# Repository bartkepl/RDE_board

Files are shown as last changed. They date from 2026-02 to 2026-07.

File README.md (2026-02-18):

# RDE (Resistance DEcade)
Resistance DEcade with SCPI, UART, USB, RS485 and ETHERNET in 3U eurocard format

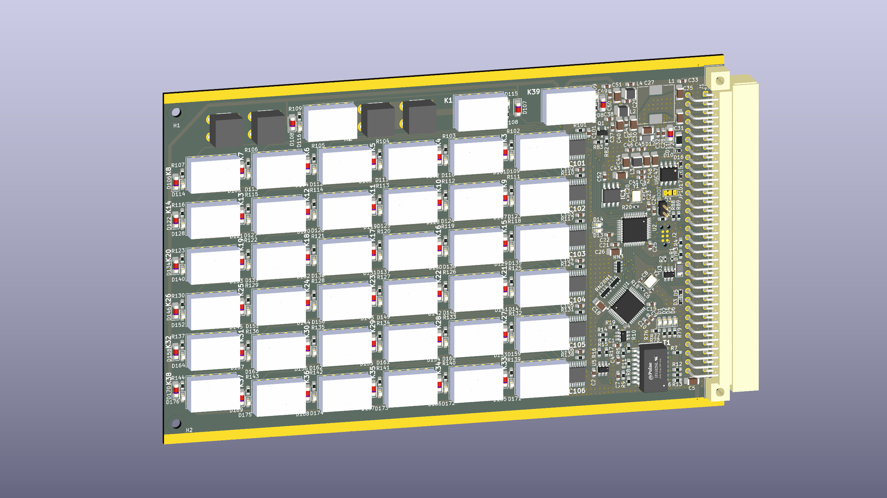
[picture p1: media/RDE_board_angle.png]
Resistance DEcade board


---
## Status : WIP

- First revision of schematic and PCB is done. 
- Creating a complementary board with a DIN 41612 connector and other interface connectors to order a complete assembly and begin work on software and interface testing.

---
## Features:
- 2 layer board
- ARM Cortex-M33 Processor in LQFP48 (STM32G431CBT6) 
- 0 - 999k&#8486; ressistor-relay matrix driven by 6x STPIC6C595
- USB 2.0
- 10/100 Ethernet (based on WIZnet W5500)
- UART
- Half-duplex RS485 
- 3U eurocard IEEE 1101.1-1998 format (160x100 mm)
----

## License and Contribution

[MIT License](/LICENSE)

Open to contributions in both software and hardware!

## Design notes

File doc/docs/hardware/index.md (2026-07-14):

# Sprzęt – Przegląd

## Mikrokontroler STM32G431CBT6

| Parametr | Wartość |
|---|---|
| Rdzeń | ARM Cortex-M33, 170 MHz |
| Flash | 128 KB |
| SRAM | 32 KB |
| Opakowanie | LQFP48 |
| USB | USB 2.0 Full Speed z CRS (bez zewnętrznego kwarcu) |
| Interfejsy | 2× SPI, 1× I2C, 2× UART, USB FS |
| ADC | 12-bit, 5 Msps |
| DAC | 12-bit |

### Przypisanie peryferiów

| Peryferium | Sygnały | Przeznaczenie |
|---|---|---|
| SPI1 | PA5/PA6/PA7, PA4 (REL_EN), PA6 (REL_RCK) | Sterowniki STPIC6C595 (przekaźniki) |
| SPI2 | PB13/PB14/PB15, PB12 (CS) | W5500 Ethernet |
| I2C1 | PB6/PB7 | FRAM FM24C64B |
| UART1 | PA9/PA10 | Debug / SCPI przez UART |
| UART2 | PA2/PA3 | RS485 (half-duplex przez transceiver) |
| USB FS | PA11/PA12, PA11 (VBUS det.) | USB-TMC (TinyUSB) |
| CRS | – | Automatyczne przycinanie HSI48 na SOF USB |

### Mapowanie pinów GPIO

| Pin | Kierunek | Sygnał | Opis |
|-----|:---:|---|---|
| PA2 | OUT | UART2_TX | RS485 TX / RS485 DE |
| PA3 | IN | UART2_RX | RS485 RX |
| PA4 | OUT | REL_EN | Zasilanie przekaźników (STPIC6C595 OE, active HIGH) |
| PA5 | OUT | SPI1_SCK | Zegar SPI dla shift-registrów |
| PA6 | OUT | REL_RCK | Latch shift-registrów (aktywny zboczem narastającym) |
| PA7 | OUT | SPI1_MOSI | Dane do shift-registrów |
| PA9 | OUT | UART1_TX | Debug TX |
| PA10 | IN | UART1_RX | Debug RX |
| PA11 | IN | USB_DETECT | Detekcja VBUS (5V obecne) |
| PA11/12 | IO | USB_DM/DP | Magistrala USB D−/D+ |
| PB6 | OUT | I2C1_SCL | Zegar I2C (FRAM) |
| PB7 | IO | I2C1_SDA | Dane I2C (FRAM) |
| PB12 | OUT | W5500_CS | Chip Select dla W5500 (active LOW) |
| PB13 | OUT | SPI2_SCK | Zegar SPI dla W5500 |
| PB14 | IN | SPI2_MISO | Dane z W5500 |
| PB15 | OUT | SPI2_MOSI | Dane do W5500 |
| PC13 | OUT | LED_R | LED czerwony (błąd SCPI) |
| PC14 | OUT | LED_G | LED zielony (heartbeat) |
| Pxx | OUT | W5500_RST | Reset W5500 (active LOW, 10 ms) |

---

## Schemat blokowy systemu

```
                    ┌──────────────────────────────────────┐
                    │         STM32G431CBT6 @ 170 MHz      │
                    │                                      │
 USB Host ─────────── USB FS (PA11/PA12)                  │
                    │   └─ TinyUSB (USB-TMC Class)         │
                    │                                      │
 RJ-45 ─── PHY ─── │ SPI2 (PB12-15) ── W5500             │
                    │   └─ VXI-11 / DHCP / mDNS            │
                    │                                      │
                    │ SPI1 (PA4-7) ─── STPIC6C595 ×6      │
                    │   └─ REL_EN (PA4)                    │── 48 przekaźników
                    │   └─ REL_RCK (PA6)                   │   (6 dekad + Q6/Q7)
                    │                                      │
 FRAM ─────────────── I2C1 (PB6/PB7) ── FM24C64B         │
 (kalibracja,       │                                      │
  config sieci)     │ UART1 (PA9/PA10) ── Debug           │
                    │ UART2 (PA2/PA3)  ── RS485            │
                    │                                      │
                    │ LED_G (PC14) 1 Hz heartbeat          │
                    │ LED_R (PC13) błąd SCPI               │
                    └──────────────────────────────────────┘
```

---

## Zasilanie

| Szyna | Napięcie | Źródło | Odbiorniki |
|---|:---:|---|---|
| VBUS | 5 V | Złącze USB lub zewnętrzne | Przetwornica 3.3 V, zasilanie przekaźników |
| VDD | 3.3 V | Przetwornica LDO | STM32, W5500, FRAM, STPIC6C595 |
| VREL | 5 V | VBUS | Cewki przekaźników przez STPIC6C595 |

---

## Format płyty

| Parametr | Wartość |
|---|---|
| Standard | 3U Eurocard (IEEE 1101.1-1998) |
| Wymiary | 160 × 100 mm |
| Warstwy PCB | 2 |
| Złącze tylne | DIN 41612 (typ C, 96 pin) |
| Rack | 19" 3U |
| Rewizja | v0.3 |

---

## Sekcje szczegółowe

- **[Macierz przekaźników](relay-matrix.md)** – STPIC6C595, kodowanie cyfr, sekwencja ochronna
- **[Ethernet – W5500](ethernet.md)** – W5500, SPI, gniazda, DHCP, VXI-11
- **[Pamięć – FRAM i Flash](memory.md)** – FM24C64B, mapa pamięci, CRC32, flash fallback

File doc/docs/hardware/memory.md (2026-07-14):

# Pamięć – FRAM i Flash

## FM24C64B – FRAM

**FM24C64B** to ferreoelektryczna pamięć nieulotna (FRAM) 64 Kb (8192 bajtów) firmy Cypress/Infineon, dostępna przez magistralę I2C1.

| Parametr | Wartość |
|---|---|
| Pojemność | 8192 bajtów (64 Kb) |
| Interfejs | I2C, do 1 MHz (Fast Plus) |
| Adres I2C | `0x50` (A0=A1=A2=GND) |
| Czas zapisu | Natychmiastowy (brak opóźnienia Write Cycle jak w EEPROM) |
| Wytrzymałość zapisu | 10^12 cykli (praktycznie nieograniczona) |
| Retencja danych | 151 lat @ 55 °C |
| Napięcie zasilania | 2.7–3.65 V |
| Prąd aktywny | < 1 mA |
| Opakowanie | SOP-8 |

### Przewaga nad Flash / EEPROM

| Cecha | FRAM FM24C64B | EEPROM | STM32 Flash |
|---|:---:|:---:|:---:|
| Czas zapisu | < 1 µs | 5–10 ms | 1–2 ms (po erase) |
| Kasowanie przed zapisem | Nie | Tak | Tak (cała strona) |
| Cykle zapisu | 10^12 | ~10^6 | ~10^4 |
| Granularność | 1 bajt | 1 bajt | 1 strona (2 KB) |

---

## Mapa pamięci FRAM

```
Adres       Rozmiar  Zawartość
──────────────────────────────────────────────────────────────
0x0000      24 B     net_config_t PRIMARY (IP, maska, GW, DHCP, magic)
0x0018       4 B     CRC32 net_config PRIMARY
0x001C       4 B     padding
0x0020      24 B     net_config_t BACKUP
0x0038       4 B     CRC32 net_config BACKUP
0x003C       4 B     padding
──────────────────────────────────────────────────────────────
0x0040     240 B     cal_data_t PRIMARY  [uint32_t milliohm[6][10]]
0x0130       4 B     CRC32 cal_data PRIMARY
0x0134       8 B     cal_config_t PRIMARY  {magic, enabled, pad[3]}
0x013C       4 B     CRC32 cal_config PRIMARY
──────────────────────────────────────────────────────────────
0x0140     240 B     cal_data_t BACKUP
0x0230       4 B     CRC32 cal_data BACKUP
0x0234       8 B     cal_config_t BACKUP
0x023C       4 B     CRC32 cal_config BACKUP
──────────────────────────────────────────────────────────────
0x0240    ~7872 B    WOLNE (do 0x1FFF)
```

### Struktury danych

**`net_config_t`** (24 bajty):
```c
typedef struct {
    uint32_t magic;        // NET_CONFIG_MAGIC = 0xDE1AC0DF
    uint8_t  ip[4];        // Statyczne IP
    uint8_t  sn[4];        // Maska podsieci
    uint8_t  gw[4];        // Brama domyślna
    uint8_t  use_dhcp;     // 0 = statyczne, 1 = DHCP
    uint8_t  phy_mode;     // 0=AUTO, 1=10M HD, 2=100M FD
    uint8_t  _pad[6];
} net_config_t;            // 24 bajty = 3 × DWORD
```

Tryb PHY konfigurowany komendą `NET:PHY:MODE`; patrz [NET – konfiguracja sieci](../scpi/network.md).

**`cal_data_t`** (240 bajtów):
```c
typedef struct {
    uint32_t milliohm[6][10];  // [dekada 0..5][cyfra 0..9]
} cal_data_t;
```

Całkowity rozmiar: 6 × 10 × 4 = **240 bajtów**.

**`cal_config_t`** (8 bajtów):
```c
typedef struct {
    uint32_t magic;    // CAL_MAGIC = 0xCA11B001
    uint8_t  enabled;  // 0 = korekcja wyłączona, 1 = włączona
    uint8_t  _pad[3];
} cal_config_t;
```

---

## Schemat CRC i redundancji

Każdy blok danych ma towarzyszący **CRC32** (IEEE 802.3). Strategia odczytu:

```
Odczyt PRIMARY
    │
    ├─ CRC OK? ──YES──► Użyj PRIMARY
    │
    └─ CRC FAIL──► Odczyt BACKUP
                       │
                       ├─ CRC OK? ──YES──► Użyj BACKUP, przepisz PRIMARY
                       │
                       └─ CRC FAIL──► (dla net_config) spróbuj Flash STM32
                                       │
                                       └─ też błąd → wartości domyślne
```

Przy każdym zapisie dane są najpierw zapisywane do PRIMARY, a następnie do BACKUP (dwa osobne zapisy FRAM z CRC).

---

## Inicjalizacja FRAM w firmware

```c
// Sprawdzenie obecności FRAM przez I2C ping
HAL_StatusTypeDef st = fm24_ping();
if (st != HAL_OK) {
    SCPI_ErrorPush(ctx, SCPI_ERROR_SYSTEM_ERROR);
    // Firmware kontynuuje, ale bez FRAM
    // Konfiguracja sieci: wczytana z Flash STM32
    // Kalibracja: tylko wartości nominalne
}
```

---

## Flash STM32G4 – zapasowa konfiguracja sieci

Gdy FRAM jest niedostępny, konfiguracja sieci jest przechowywana w **ostatniej stronie Flash STM32G4**:

| Parametr | Wartość |
|---|---|
| Adres | `0x0801F800` (strona 63, 2 KB) |
| Rozmiar strony | 2048 bajtów |
| Wytrzymałość | ~10 000 cykli kasowanie/zapis |
| Czas kasowania strony | ~10 ms |
| Format | `net_config_t` + CRC32 (28 bajtów) |

!!! warning
    Flash STM32G4 wymaga skasowania całej strony 2 KB przed zapisem. Ta operacja jest destruktywna i trwa ~10 ms podczas której CPU jest zablokowane (brak ICACHE w STM32G4). Unikaj częstego zapisu do Flash – używaj FRAM gdy dostępny.

### Procedura zapisu do Flash

```c
void net_config_flash_save(const net_config_t *cfg) {
    HAL_FLASH_Unlock();
    
    FLASH_EraseInitTypeDef erase = {
        .TypeErase = FLASH_TYPEERASE_PAGES,
        .Page      = 63,
        .NbPages   = 1
    };
    uint32_t error;
    HAL_FLASHEx_Erase(&erase, &error);
    
    // Zapis double-word (64-bit) – wymóg STM32G4
    for (int i = 0; i < sizeof(net_config_t); i += 8)
        HAL_FLASH_Program(FLASH_TYPEPROGRAM_DOUBLEWORD,
                          FLASH_CONFIG_ADDR + i,
                          *((uint64_t*)(buf + i)));
    
    HAL_FLASH_Lock();
}
```

---

## Sterownik I2C FRAM (`fm24c64b.c`)

| Funkcja | Opis |
|---|---|
| `fm24_ping()` | Sprawdza obecność przez HAL_I2C_IsDeviceReady |
| `fm24_read(addr, buf, len)` | Odczyt `len` bajtów z adresu `addr` |
| `fm24_write(addr, buf, len)` | Zapis `len` bajtów pod adres `addr` |

Bajty adresu wysyłane są big-endian (MSB first), zgodnie ze specyfikacją I2C FRAM.

Prędkość I2C1: **400 kHz** (Fast Mode). FRAM obsługuje do 1 MHz – ograniczenie po stronie konfiguracji STM32 CubeMX.

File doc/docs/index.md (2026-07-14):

# RDE – Programowalny Dekadnik Rezystancyjny

**RDE** (Resistance DEcade) to precyzyjny, programowalny dekadnik rezystancyjny w formacie **3U Eurocard** sterowany przez SCPI. Zastępuje ręczną skrzynkę oporową w stanowiskach automatycznego testowania.

RDE Board

---

## Schemat systemu

```
         ┌─────────────────────────────────────────┐
         │           STM32G431CBT6 @ 170 MHz        │
         │                                         │
USB ─────│─ USB-TMC (TinyUSB)   SPI1 ─ STPIC×6 ────── 48 przekaźników
         │                              REL_EN     │   (6 dekad + Q6/Q7)
RJ-45 ───│─ W5500 (SPI2)        SPI2 ─ W5500      │
  DHCP   │   └─ VXI-11 :703             I2C1 ─ FM24C64B
  mDNS   │   └─ Portmapper :111         UART1 ─ Debug
         │   └─ mDNS :5353              UART2 ─ RS485
         └─────────────────────────────────────────┘
```

---

## Specyfikacja

| Parametr | Wartość |
|---|---|
| Zakres rezystancji | 0 – 999 999 Ω (krok 1 Ω) |
| Dekady | 6 (1 Ω / 10 Ω / 100 Ω / 1 kΩ / 10 kΩ / 100 kΩ) |
| Interfejsy | USB-TMC, VXI-11/Ethernet, UART, RS485 |
| Procesor | ARM Cortex-M33 @ 170 MHz (STM32G431CBT6) |
| Ethernet | WIZnet W5500, 10 Mbps (v0.3), DHCP + mDNS |
| Sterowniki przekaźników | 6× STPIC6C595 (shift-register, SPI) |
| Pamięć nieulotna | FM24C64B FRAM 8 KB + flash STM32G4 (zapas) |
| Kalibracja | 60 punktów (6 dekad × 10 cyfr), CRC32, zapis w FRAM |
| Protokół | SCPI-1999 / IEEE 488.2 |
| Format płyty | 3U Eurocard 160 × 100 mm (IEEE 1101.1-1998) |
| USB VID/PID | `0xCAFE` / `0x4000` |

---

## Szybki start

=== "USB-TMC"

    ```python
    import pyvisa

    rm = pyvisa.ResourceManager('@py')
    inst = rm.open_resource('USB0::0xCAFE::0x4000::A3F7B201::0::INSTR')
    inst.timeout = 3000
    print(inst.query('*IDN?'))
    # bartkepl,RDE,1.0,A3F7B201

    inst.write('RESistance:VALue 4700')
    inst.write('OUTPut:STATe ON')
    ```

=== "VXI-11 / Ethernet"

    ```python
    import pyvisa

    rm = pyvisa.ResourceManager('@py')
    inst = rm.open_resource('TCPIP::192.168.1.6::INSTR')
    inst.timeout = 5000
    print(inst.query('*IDN?'))
    # bartkepl,RDE,1.0,A3F7B201

    inst.write('RESistance:VALue 4700')
    inst.write('OUTPut:STATe ON')
    ```

=== "mDNS (bez znajomości IP)"

    ```python
    import pyvisa

    rm = pyvisa.ResourceManager('@py')
    inst = rm.open_resource('TCPIP::RDE-A3F7B201.local::INSTR')
    print(inst.query('*IDN?'))
    ```

---

## Grupy komend SCPI

| Prefix | Opis | Strona |
|---|---|---|
| `*` | Komendy IEEE 488.2 (IDN, RST, CLS, TST…) | [IEEE 488.2](scpi/ieee488.md) |
| `RESistance`, `OUTPut` | Ustawianie rezystancji, sterowanie wyjściem | [RESistance & OUTPut](scpi/resistance.md) |
| `RELay` | Surowy dostęp do bitów shift-registrów (serwis) | [RELay](scpi/relay.md) |
| `CALibration` | Kalibracja 60-punktowa | [CALibration](scpi/calibration.md) |
| `NET` | Konfiguracja sieci Ethernet | [NET](scpi/network.md) |
| `SYSTem` | Błędy, numer seryjny, bootloader, reset | [SYSTem](scpi/system.md) |

---

## Struktura dokumentacji

| Sekcja | Zawartość |
|---|---|
| **[Pierwsze kroki](getting-started.md)** | Instalacja sterowników, połączenie, pierwsze komendy |
| **[Sprzęt](hardware/index.md)** | MCU, macierz przekaźników, Ethernet, pamięć FRAM |
| **[Firmware](firmware/index.md)** | Architektura kodu, inicjalizacja, API |
| **[Komendy SCPI](scpi/index.md)** | Pełna dokumentacja wszystkich komend |
| **[Procedura kalibracji](calibration.md)** | Krok po kroku: ręczna i automatyczna |
| **[Aplikacja rde_control.py](rde_control.md)** | Opis GUI Python, multimetry, raport PDF |
| **[Status & TODO](todo.md)** | Co zrealizowano, co pozostało, znane błędy |

---

## Licencja

Projekt na licencji **MIT** – zapraszamy do współpracy przy kodzie i elektronice.

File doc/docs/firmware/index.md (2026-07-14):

# Architektura firmware

## Środowisko i zależności

| Element | Wersja / Opis |
|---|---|
| IDE | STM32CubeIDE 1.14+ |
| Kompilator | arm-none-eabi-gcc 12.x (wbudowany w CubeIDE) |
| HAL | STM32Cube HAL + CMSIS (generowane przez CubeMX) |
| USB stack | TinyUSB (vendored w `App/tinyusb/`) |
| Ethernet stack | WIZnet ioLibrary Driver (vendored w `App/wiznet/`) |
| SCPI parser | libscpi (vendored w `App/libscpi/`) |
| Język | C11 |

---

## Struktura katalogów

```
firmware/RDE_soft/
├── Core/
│   ├── Inc/                        # Nagłówki CubeMX (GPIO, SPI, I2C, UART, USB)
│   ├── Src/
│   │   └── main.c                  # Punkt wejścia, inicjalizacja, główna pętla
│   └── Startup/                    # Plik startowy STM32 (assembly)
├── Drivers/
│   ├── CMSIS/                      # ARM CMSIS headers
│   └── STM32G4xx_HAL_Driver/       # STM32 HAL
└── App/                            # Kod aplikacji
    ├── scpi_def.h / scpi_def.c     # Tabela komend SCPI i handlery
    ├── net_config.h / net_config.c # Konfiguracja sieci (FRAM + flash)
    ├── w5500_net.h / w5500_net.c   # Zarządzanie W5500, DHCP, sockety
    ├── usbtmc_app.h / usbtmc_app.c # Warstwa aplikacji USB-TMC
    ├── relay/
    │   ├── relay_ctrl.h / .c       # Sterowanie STPIC6C595
    │   └── relay_cal.h  / .c       # Kalibracja + FRAM
    ├── fram/
    │   └── fm24c64b.h / .c         # Sterownik I2C FRAM
    ├── vxi11/
    │   └── vxi11_server.h / .c     # Serwer VXI-11 RPC
    ├── utils/
    │   └── utils.c                 # Numer seryjny (UID + FNV-1a)
    ├── libscpi/                    # Parser SCPI (zewnętrzny)
    ├── tinyusb/                    # Stack USB (zewnętrzny)
    ├── wiznet/                     # WIZnet driver (zewnętrzny)
    └── mdns/                       # mDNS (zewnętrzny)
```

---

## Przepływ danych

```
Klient VISA (PyVISA)
        │
   ┌────┴─────┐
   │          │
USB-TMC    VXI-11/TCP
(TinyUSB)  (port 703)
   │          │
   └────┬─────┘
        │ SCPI tekst ASCII
        ▼
   libscpi parser
   (scpi_def.c – tabela komend)
        │
   ┌────┴────────────┐
   │                 │
relay_ctrl.c     net_config.c
relay_cal.c      vxi11_server.c
   │                 │
SPI1 (STPIC)     SPI2 (W5500)
   │                 │
Przekaźniki      Ethernet PHY
```

---

## Inicjalizacja – kolejność

```c
// main.c

// 1. HAL i zegar systemowy
HAL_Init();
SystemClock_Config();          // 170 MHz PLL z HSI16, HSI48 dla USB

// 2. Peryferia (CubeMX)
MX_GPIO_Init();
MX_SPI1_Init();                // Shift-registery (przekaźniki)
MX_SPI2_Init();                // W5500 Ethernet
MX_I2C1_Init();                // FRAM FM24C64B
MX_USART1_UART_Init();         // Debug / SCPI przez UART
MX_USART2_UART_Init();         // RS485
MX_USB_Init();                 // USB FS

// 3. CRS – automatyczne trymianie HSI48 synchronizowane przez SOF USB
// (eliminuje potrzebę zewnętrznego kwarcu USB)

// 4. Moduły aplikacji
relay_init();                  // STPIC do bezpiecznego stanu (SHORT ON)
SCPI_Main_Init();              // Kontekst libscpi, rejestracja komend
fm24_ping();                   // Weryfikacja FRAM – push SCPI error jeśli brak
net_config_init();             // Wczytaj konfigurację sieci z FRAM lub flash
relay_cal_init();              // Wczytaj kalibrację z FRAM (lub nominały)

// 5. USB – czeka na VBUS zanim podciągnie D+
tud_init(0);
tud_disconnect();              // D+ LOW, nie widoczny dla hosta

// 6. Ethernet
w5500_net_init();              // Reset W5500, konfiguracja IP, DHCP start
```

---

## Główna pętla (`while(1)`)

Firmware realizuje **kooperatywne planowanie zadań** bez RTOS – wszystkie zadania są nieblokujące:

```c
while (1) {

    /* === Heartbeat i status LED === */
    if (HAL_GetTick() - led_tick > 500) {
        led_tick = HAL_GetTick();
        HAL_GPIO_TogglePin(LED_G_GPIO_Port, LED_G_Pin);  // 1 Hz blink
    }
    // LED_R – świeci gdy kolejka błędów SCPI niepusta
    HAL_GPIO_WritePin(LED_R_GPIO_Port, LED_R_Pin,
                      SCPI_ErrorCount(ctx) > 0 ? GPIO_PIN_SET : GPIO_PIN_RESET);

    /* === USB === */
    bool vbus = HAL_GPIO_ReadPin(USB_DETECT_GPIO_Port, USB_DETECT_Pin);
    if (vbus && !tud_connected()) tud_connect();
    if (!vbus && tud_connected())  tud_disconnect();
    if (vbus) {
        tud_task();               // obsługa zdarzeń USB (SOF, SETUP, IN/OUT)
        usbtmc_app_task_iter();   // parsowanie ramek USB-TMC
    }

    /* === SCPI poll (wymagane przez libscpi) === */
    SCPI_Main_Poll();

    /* === Ethernet: DHCP, VXI-11, portmapper, mDNS === */
    w5500_net_task();
}
```

### Czasy zadań

| Zadanie | Typ | Typowy czas |
|---|:---:|:---:|
| LED toggle | Co 500 ms | < 1 µs |
| `tud_task()` | Co iterację (polling) | 2–50 µs |
| `usbtmc_app_task_iter()` | Co iterację | 1–200 µs |
| `w5500_net_task()` | Co iterację | 50–500 µs |
| `SCPI_Main_Poll()` | Co iterację | < 1 µs |

---

## Moduły – opis

### `scpi_def.c` / `scpi_def.h`

- Tablica `scpi_commands[]` – mapuje ciągi SCPI na wskaźniki do funkcji handlerów
- Współdzielony bufor odpowiedzi `scpi_reply_buf[512]` (używany przez USB-TMC i VXI-11)
- Funkcja `SCPI_Main_Init()` – inicjalizuje kontekst libscpi
- Funkcja `SCPI_Main_Poll()` – nieblokujące wywołanie libscpi

### `net_config.c`

- `net_config_init()` – wczytuje konfigurację z FRAM (PRIMARY → BACKUP → Flash → domyślne)
- `net_config_save()` – zapisuje do FRAM (PRIMARY + BACKUP z CRC32)
- `net_config_flash_save()` – zapisuje do flash STM32G4 strona 63
- `net_config_apply()` – stosuje konfigurację: restartuje stos W5500

### `utils.c`

Generuje numery seryjne z **UID MCU** (96-bitowy unikalny numer STM32):

```c
// Krótki: 32-bitowy FNV-1a hash UID → 8 znaków HEX
void serial_get(char out[9]);

// Długi: surowe 96 bitów UID → 24 znaki HEX  
void serial_get_full(char out[25]);
```

---

## Obsługa błędów

- libscpi utrzymuje kolejkę błędów SCPI (max 16 pozycji)
- LED_R świeci gdy `SCPI_ErrorCount() > 0`
- Błędy kasowane przez `*CLS` lub `SYSTem:ERRor:NEXT?`
- Błąd braku FRAM przy starcie: `SCPI_ERROR_SYSTEM_ERROR` (kod -300)

---

## Sekcje szczegółowe

- **[API przekaźników i kalibracji](relay-api.md)** – `relay_ctrl.c`, `relay_cal.c`, typy, funkcje
- **[API komunikacji](comms-api.md)** – USB-TMC, VXI-11, SCPI, bufor współdzielony

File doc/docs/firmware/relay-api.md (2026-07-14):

# API przekaźników i kalibracji

## Moduł `relay_ctrl` – sterowanie przekaźnikami

### Typy i stałe

```c
// relay_ctrl.h

// Sentinel zwracany przez relay_get_resistance() gdy stan nieznany
#define RELAY_RESISTANCE_UNKNOWN  (-1)

// Maksymalna rezystancja nominalna
#define RELAY_MAX_RESISTANCE  999999   // Ω
```

### Funkcje

---

#### `relay_init`

```c
void relay_init(void);
```

Inicjalizuje SPI1 i ustawia bezpieczny stan startowy:

- PA4 (REL_EN) = LOW → wyłączone wyjścia STPIC
- Wszystkie bajty `data[6] = 0x00`
- Q6 (CONNECT) = 0, Q7 (SHORT) = 1 → zaciski zwarte
- PA4 = HIGH → wyjścia aktywne

Wywoływana raz przy starcie, przed `SCPI_Main_Init()`.

---

#### `relay_set_resistance`

```c
int relay_set_resistance(int32_t ohms);
```

Ustawia rezystancję z pełną sekwencją ochronną.

**Parametry:**

| Parametr | Typ | Zakres | Opis |
|---|:---:|:---:|---|
| `ohms` | `int32_t` | 0–999 999 | Żądana rezystancja w omach |

**Zwraca:** `0` sukces, `-1` błąd zakresu.

**Sekwencja wewnętrzna** (gdy wyjście podłączone):

```c
relay_set_bit_raw(6, SHORT_BIT, 1);   // SHORT ON
HAL_Delay(1);
// dekoduj ohms → cyfry 6 dekad
for (int d = 0; d < 6; d++)
    data[d] = digit_to_byte[digit[d]];
relay_latch();                         // prześlij przez SPI
HAL_Delay(1);
relay_set_bit_raw(6, CONNECT_BIT, 1); // CONNECT ON
relay_set_bit_raw(7, SHORT_BIT, 0);   // SHORT OFF
relay_latch();
```

Specjalny przypadek `ohms = 0`:

```c
relay_set_output(false);              // SHORT ON, CONNECT OFF
// Wszystkie dekady = cyfra 0 (bypass)
```

---

#### `relay_get_resistance`

```c
int32_t relay_get_resistance(void);
```

Zwraca aktualną nominalną rezystancję w omach, lub `RELAY_RESISTANCE_UNKNOWN` jeśli stan jest niezdefiniowany (np. po `RELay:STATe`).

---

#### `relay_set_output`

```c
void relay_set_output(bool connected);
```

Steruje przekaźnikami ochronnymi terminali:

| `connected` | Q6 (CONNECT) | Q7 (SHORT) |
|:---:|:---:|:---:|
| `true` | 1 | 0 |
| `false` | 0 | 1 |

Zapis natychmiastowy przez SPI bez zmiany bitów Q0–Q5.

---

#### `relay_get_output`

```c
bool relay_get_output(void);
```

Zwraca aktualny stan wyjścia (`true` = CONNECT, `false` = SHORT).

---

#### `relay_set_decade`

```c
int relay_set_decade(int decade, int digit);
```

Ustawia jedną dekadę z sekwencją ochronną. Pozostałe dekady nie są zmieniane.

**Parametry:**

| Parametr | Zakres | Opis |
|---|:---:|---|
| `decade` | 1–6 | Numer dekady (1=1Ω, 6=100kΩ) |
| `digit` | 0–9 | Żądana cyfra |

**Zwraca:** `0` sukces, `-1` błąd zakresu.

---

#### `relay_get_decade`

```c
int relay_get_decade(int decade);
```

Zwraca aktualną cyfrę dekady (0–9) lub `-1` gdy stan nieznany.

---

#### `relay_set_bit`

```c
void relay_set_bit(int decade, int bit, bool on);
```

Bezpośrednie ustawienie jednego bitu Q bez sekwencji ochronnej.

!!! warning
    Po wywołaniu tej funkcji `relay_get_resistance()` zwraca `RELAY_RESISTANCE_UNKNOWN`. Stan resetuje się dopiero przez `relay_set_resistance()` lub `relay_set_decade()`.

**Parametry:**

| Parametr | Zakres | Opis |
|---|:---:|---|
| `decade` | 1–6 | Numer dekady |
| `bit` | 0–5 | Numer bitu Q (Q0–Q5) |
| `on` | `bool` | Stan bitu |

---

#### `relay_get_bit`

```c
bool relay_get_bit(int decade, int bit);
```

Odczytuje stan bitu Q z wewnętrznego bufora (bez odczytu SPI).

---

#### `relay_set_raw`

```c
void relay_set_raw(const uint8_t data[6]);
```

Bezpośredni zapis 6 bajtów do shift-registrów przez SPI. Zachowuje aktualne bity Q6/Q7 (CONNECT/SHORT) – nadpisuje je wartościami z wewnętrznego stanu.

Używana przez komendę `RELay:RAW`.

---

#### `relay_get_raw`

```c
void relay_get_raw(uint8_t data[6]);
```

Kopiuje aktualny wewnętrzny bufor 6 bajtów do `data`.

---

### Przykłady użycia

```c
// Inicjalizacja
relay_init();

// Ustaw 4.7 kΩ, podłącz wyjście
relay_set_resistance(4700);
relay_set_output(true);

// Odczyt stanu
int32_t r = relay_get_resistance();   // 4700
int d4 = relay_get_decade(4);         // 4 (bo 4000 Ω w dekadzie 4)

// Zmień dekadę 2 na cyfrę 7 (70 Ω)
relay_set_decade(2, 7);
// r_total = 4700 - 0 + 70 = 4770 Ω (dekada 2 zmieniona z 0 na 7)

// Zwieranie wyjścia
relay_set_output(false);
```

---

## Moduł `relay_cal` – kalibracja

### Typy i stałe

```c
// relay_cal.h

#define CAL_MAGIC    0xCA11B001u   // Magic word w FRAM dla kalibracji

typedef struct {
    uint32_t milliohm[6][10];     // [dekada_idx 0..5][cyfra 0..9]
} cal_data_t;

typedef struct {
    uint32_t magic;               // CAL_MAGIC
    uint8_t  enabled;             // 0 = korekcja wyłączona, 1 = włączona
    uint8_t  _pad[3];
} cal_config_t;
```

Indeks dekady w tablicy: 0 = dekada 1 (1 Ω), 5 = dekada 6 (100 kΩ).

### Funkcje

---

#### `relay_cal_init`

```c
void relay_cal_init(void);
```

Wczytuje kalibrację z FRAM (PRIMARY → BACKUP → nominały). Wywoływana przy starcie po `fm24_ping()`.

---

#### `relay_cal_set`

```c
void relay_cal_set(int decade, int digit, uint32_t milliohm);
```

Zapisuje punkt kalibracyjny do RAM (nie do FRAM). Wymaga oddzielnego `relay_cal_save()`.

**Parametry:**

| Parametr | Zakres | Opis |
|---|:---:|---|
| `decade` | 1–6 | Numer dekady |
| `digit` | 0–9 | Cyfra |
| `milliohm` | 0–900 000 000 | Zmierzona rezystancja w mΩ |

---

#### `relay_cal_get`

```c
uint32_t relay_cal_get(int decade, int digit);
```

Zwraca zapisany punkt kalibracyjny w mΩ.

---

#### `relay_cal_save`

```c
int relay_cal_save(void);
```

Zapisuje całą tablicę kalibracji do FRAM (PRIMARY + BACKUP z CRC32).

**Zwraca:** `0` sukces, `-1` błąd zapisu FRAM.

---

#### `relay_cal_load`

```c
int relay_cal_load(void);
```

Przeładowuje kalibrację z FRAM (jak przy starcie). Przydatne po ręcznej zmianie `CALibration:DECade` bez `CALibration:SAVE`.

**Zwraca:** `0` sukces, `-1` błąd odczytu lub CRC.

---

#### `relay_cal_reset`

```c
void relay_cal_reset(void);
```

Resetuje wszystkie punkty do wartości nominalnych:

```c
milliohm[d][digit] = (uint32_t)digit * multiplier[d] * 1000;
// multiplier[] = {1, 10, 100, 1000, 10000, 100000}
```

Nie zapisuje do FRAM – wymagane oddzielne `relay_cal_save()`.

---

#### `relay_cal_set_enabled`

```c
void relay_cal_set_enabled(bool enable);
```

Włącza lub wyłącza stosowanie korekcji kalibracyjnej.

---

#### `relay_cal_get_enabled`

```c
bool relay_cal_get_enabled(void);
```

Zwraca stan flagi korekcji.

---

#### `relay_cal_get_resistance_mo`

```c
uint64_t relay_cal_get_resistance_mo(void);
```

Sumuje miliohmowe wartości kalibracyjne dla aktualnie nastawionych cyfr każdej dekady.

```c
uint64_t total = 0;
for (int d = 0; d < 6; d++)
    total += cal_data.milliohm[d][current_digit[d]];
return total;
```

Wywoływana przez handler `RESistance:VALue?` gdy kalibracja jest włączona.

---

### Przykłady użycia

```c
// Inicjalizacja (przy starcie)
relay_cal_init();

// Załaduj nowy punkt kalibracyjny (dekada 1, cyfra 5, zmierzono 4983 mΩ)
relay_cal_set(1, 5, 4983);

// Zapisz do FRAM
relay_cal_save();

// Włącz korekcję
relay_cal_set_enabled(true);

// Odczyt skalibrowanej rezystancji
uint64_t mo = relay_cal_get_resistance_mo();
printf("%.3f Ω\n", mo / 1000.0);
```

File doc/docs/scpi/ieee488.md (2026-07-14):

# IEEE 488.2 – Komendy obowiązkowe

Komendy zaczynające się od `*` są obowiązkowe w standardzie IEEE 488.2 i obecne w każdym urządzeniu SCPI.

---

## `*IDN?`

Identyfikacja urządzenia.

**Składnia:** `*IDN?`

**Odpowiedź:**
```
bartkepl,RDE,1.0,<serial>
```

Pola oddzielone przecinkami:

| Pole | Wartość | Opis |
|---|---|---|
| Manufacturer | `bartkepl` | Identyfikator producenta |
| Model | `RDE` | Model urządzenia |
| Serial | `<8 znaków HEX>` | FNV-1a hash z UID MCU |
| Firmware | `1.0` | Wersja firmware |

**Przykład Python:**

```python
idn = inst.query('*IDN?')
manufacturer, model, firmware, serial = idn.split(',')
print(f'Połączono z: {model} ({serial})')
```

---

## `*RST`

Reset urządzenia do stanu domyślnego.

**Składnia:** `*RST`

**Efekt:**

- Rezystancja → 0 Ω (zwarcie wszystkich dekad)
- Wyjście → SHORT ON, CONNECT OFF (zaciski zwarte)
- Kolejka błędów → **nie** czyszczona (użyj `*CLS`)
- Konfiguracja sieci → **nie** zmieniana
- Kalibracja → **nie** zmieniana

!!! note
    `*RST` jest równoważny `SYSTem:RST` w zakresie stanu przekaźników. Nie powoduje twardego restartu MCU.

**Przykład Python:**

```python
inst.write('*RST')
print(inst.query('RESistance:VALue?'))   # 0
print(inst.query('OUTPut:STATe?'))       # 0
```

---

## `*CLS`

Czyszczenie rejestrów statusu i kolejki błędów.

**Składnia:** `*CLS`

**Efekt:**

- Kolejka błędów SCPI → wyczyszczona
- Event Status Register (ESR) → 0
- Status Byte (STB) → 0
- LED_R → gaśnie

```python
inst.write('*CLS')
```

---

## `*TST?`

Self-test urządzenia.

**Składnia:** `*TST?`

**Odpowiedź:**

| Wartość | Znaczenie |
|:---:|---|
| `0` | Test przeszedł pomyślnie |
| `1` | Błąd: FRAM niedostępny (bit 0) |

Self-test sprawdza:
- Obecność FRAM FM24C64B na I2C (przez `fm24_ping()`)

!!! info
    Self-test nie testuje stanu przekaźników ani sieci Ethernet. Wartość `1` oznacza że kalibracja i konfiguracja sieci nie będą zapisywane trwale.

**Przykład Python:**

```python
result = inst.query('*TST?')
if int(result) != 0:
    print('Uwaga: FRAM niedostępny – kalibracja nie będzie zapisana')
```

---

## `*OPC` / `*OPC?`

Operation Complete – synchronizacja.

**Składnia:** `*OPC` / `*OPC?`

Ponieważ wszystkie operacje RDE są synchroniczne (przekaźniki przełączają się w callbacku komendy), `*OPC?` zawsze zwraca `1` natychmiast.

**Odpowiedź `*OPC?`:** `1`

```python
inst.write('RESistance:VALue 100000')
opc = inst.query('*OPC?')   # → "1" (operacja już zakończona)
```

---

## `*WAI`

Czekaj na zakończenie operacji.

**Składnia:** `*WAI`

No-op dla RDE – wszystkie operacje są synchroniczne.

---

## `*ESE <val>` / `*ESE?`

Event Status Enable – rejestr maski ESR.

**Składnia:**
- `*ESE <val>` – ustaw maskę (0–255)
- `*ESE?` – odczytaj maskę

**Bity ESR (IEEE 488.2):**

| Bit | Waga | Znaczenie |
|:---:|:---:|---|
| 0 | 1 | Operation Complete (OPC) |
| 2 | 4 | Query Error |
| 3 | 8 | Device Dependent Error |
| 4 | 16 | Execution Error |
| 5 | 32 | Command Error |
| 6 | 64 | User Request |
| 7 | 128 | Power On |

```python
inst.write('*ESE 255')   # włącz wszystkie bity
print(inst.query('*ESE?'))  # 255
```

---

## `*ESR?`

Event Status Register – odczyt i wyczyszczenie.

**Składnia:** `*ESR?`

**Odpowiedź:** liczba 0–255 (bity jak w `*ESE`)

Odczyt ESR automatycznie go zeruje.

```python
esr = int(inst.query('*ESR?'))
if esr & 0x20:
    print('Błąd komendy w ESR')
```

---

## `*SRE <val>` / `*SRE?`

Service Request Enable – rejestr maski SRQ.

**Składnia:**
- `*SRE <val>` – ustaw maskę (0–255)
- `*SRE?` – odczytaj maskę

Bit 6 (64) zarezerwowany (zawsze 0 w SRE, nie można włączyć własnego bitu MSS).

---

## `*STB?`

Status Byte – odczyt rejestru statusu.

**Składnia:** `*STB?`

**Odpowiedź:** liczba 0–255

| Bit | Waga | Znaczenie |
|:---:|:---:|---|
| 2 | 4 | Error/Event Queue not empty (MAV dla kolejki błędów) |
| 4 | 16 | Message Available (MAV) |
| 5 | 32 | Event Status Summary (ESB) |
| 6 | 64 | Request Service (MSS/RQS) |

---

## Tabela podsumowująca

| Komenda | Parametr | Odpowiedź | Opis |
|---|---|---|---|
| `*IDN?` | – | `bartkepl,RDE,1.0,<serial>` | Identyfikacja |
| `*RST` | – | – | Reset do stanu domyślnego |
| `*CLS` | – | – | Czyszczenie statusu i błędów |
| `*TST?` | – | `0` lub `1` | Self-test |
| `*OPC` | – | – | Operation Complete (set bit) |
| `*OPC?` | – | `1` | Czy wszystkie operacje zakończone |
| `*WAI` | – | – | Czekaj (no-op) |
| `*ESE <n>` | 0–255 | – | Ustaw maskę ESR |
| `*ESE?` | – | 0–255 | Odczyt maski ESR |
| `*ESR?` | – | 0–255 | Odczyt i zerowanie ESR |
| `*SRE <n>` | 0–255 | – | Ustaw maskę SRQ |
| `*SRE?` | – | 0–255 | Odczyt maski SRQ |
| `*STB?` | – | 0–255 | Odczyt Status Byte |

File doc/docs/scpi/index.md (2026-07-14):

# Komendy SCPI – Przegląd

RDE implementuje protokół **SCPI-1999** (Standard Commands for Programmable Instruments) nad IEEE 488.2. Komendy dostępne są przez USB-TMC i VXI-11/Ethernet – te same komendy, ten sam wynik.

---

## Grupy komend

| Prefix | Plik | Opis |
|---|---|---|
| `*` | [IEEE 488.2](ieee488.md) | Komendy obowiązkowe (IDN, RST, CLS, TST, ...) |
| `RESistance`, `OUTPut` | [RESistance & OUTPut](resistance.md) | Ustawianie rezystancji, sterowanie wyjściem |
| `RELay` | [RELay](relay.md) | Surowy dostęp do bitów shift-registrów |
| `CALibration` | [CALibration](calibration.md) | Kalibracja 60-punktowa |
| `NET` | [NET](network.md) | Konfiguracja sieci Ethernet |
| `SYSTem` | [SYSTem](system.md) | Błędy, wersja, numer seryjny, reset, bootloader |

---

## Składnia SCPI

### Forma długa i krótka

Duże litery w nazwie komendy wyznaczają minimalny skrót:

```
RESistance:VALue 1000   →  RES:VAL 1000   ✓
OUTPut:STATe ON         →  OUTP:STAT ON   ✓
SYSTem:ERRor:NEXT?      →  SYST:ERR:NEXT? ✓
```

### Zapytania (query)

Znak `?` na końcu tworzy zapytanie zamiast komendy:

```
RESistance:VALue 4700      ← ustawia
RESistance:VALue?          ← odpytuje → "4700"
```

### Łączenie komend

Średnik `;` łączy komendy w jednej linii (dzielą prefiks):

```
RESistance:VALue 1000; OUTPut:STATe ON
```

### Typy wartości

| Typ | Przykłady |
|-----|---|
| Liczba całkowita | `0`, `4700`, `999999` |
| Liczba zmiennoprzecinkowa | `4.983`, `1.5e3` |
| Bool | `ON`, `OFF`, `1`, `0` |
| String | `"tekst"` |
| Wybór | `SHORT`, `LONG`, `HIGH`, `MEDIUM`, `LOW` |

---

## Kolejka błędów

RDE utrzymuje kolejkę błędów SCPI (max 16 pozycji, FIFO).

- Błąd pojawia się przy: nieprawidłowej komendzie, złych parametrach, braku FRAM
- **LED_R** świeci gdy kolejka niepusta
- Odczyt i usunięcie błędu: `SYSTem:ERRor[:NEXT]?`
- Wyczyszczenie całej kolejki: `*CLS`

Format odpowiedzi:
```
SYSTem:ERRor?  →  -222,"Data out of range"
SYSTem:ERRor?  →  0,"No error"
```

### Wzorzec obsługi błędów w Pythonie

```python
def check_errors(inst):
    while True:
        resp = inst.query('SYSTem:ERRor?')
        code, desc = resp.split(',', 1)
        if int(code) == 0:
            break
        print(f'RDE Error {code}: {desc.strip()}')

inst.write('RESistance:VALue 9999999')  # błąd: poza zakresem
check_errors(inst)
# RDE Error -222: "Data out of range"
```

---

## Tabela dostępności komend

| Komenda | Dostępna | Uwagi |
|---|:---:|---|
| Wszystkie `*` (IEEE 488.2) | ✓ | Zawsze dostępne |
| `RESistance:*` | ✓ | – |
| `OUTPut:*` | ✓ | – |
| `RELay:*` | ✓ | Tryb serwisowy |
| `CALibration:*` | ✓ | Wymaga FRAM dla `CAL:SAVE/LOAD` |
| `NET:*` | ✓ | `NET:APPLy` restartuje stos |
| `SYSTem:*` | ✓ | `SYSTem:BOOTloader:ENter` nieodwracalne |

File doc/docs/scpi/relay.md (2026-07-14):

# RELay – surowy dostęp do przekaźników

!!! warning "Tryb serwisowy"
    Komendy `RELay` omijają sekwencję ochronną i mechanizm śledzenia rezystancji. Po ich użyciu `RESistance:VALue?` i `RESistance:DECade?` zwracają `UNKN`. Stan resetuje się dopiero przez `RESistance:VALue` lub `*RST`.

    Używaj wyłącznie do testowania sprzętu i serwisowania.

---

## `RELay:RAW`

Ustawia przekaźniki bezpośrednio przez format numeryczny kodujący dekadę i bit.

**Składnia:** `RELay:RAW <xRy>[,<xRy>,...]`

**Format parametru `xRy`:**

Trzy cyfry dziesiętne tworzą jeden adres bitu:

| Pozycja | Cyfra | Znaczenie |
|:---:|:---:|---|
| Setki (`x`) | 1–6 | Numer dekady |
| Dziesiątki | dowolne | Ignorowane (separator) |
| Jedności (`y`) | 0–5 | Numer bitu Q |

Można podać wiele adresów oddzielonych przecinkami – wszystkie bity zostaną ustawione jednocześnie.

**Uwaga:** `RELay:RAW` **ustawia** tylko podane bity; pozostałe bity zachowują poprzedni stan. Bity Q6 i Q7 (CONNECT/SHORT) są zawsze zachowywane z aktualnego stanu wyjścia – nie można ich zmienić przez `RELay:RAW`.

**Przykłady:**

```
RELay:RAW 103        ← dekada 1 (setki=1), bit Q3 (jedności=3) = ON
RELay:RAW 206,405    ← dekada 2 bit Q6 (nieważne – ale Q6 jest zarezerwowane)
                        i dekada 4 bit Q5 = ON
RELay:RAW 100        ← dekada 1, bit Q0 (bypass) = ON
```

```python
# Ustawienie bypass (cyfra 0) dla dekady 1
inst.write('RELay:RAW 100')

# Ustawienie cyfry 5 dla dekady 3 (bity Q1 i Q4)
# Cyfra 5 = Q1=1, Q4=1 → adresy: 301 i 304
inst.write('RELay:RAW 301,304')

# Sprawdzenie stanu
raw = inst.query('RELay:RAW?')
print(raw)   # np. "1,0,18,0,0,0"  (6 bajtów dziesiętnie)
```

---

## `RELay:RAW?`

Odczytuje aktualny stan wszystkich 6 bajtów shift-registrów.

**Składnia:** `RELay:RAW?`

**Odpowiedź:** `<b0>,<b1>,<b2>,<b3>,<b4>,<b5>` – 6 liczb dziesiętnych

Kolejność bajtów:

| Pozycja | Bajt | Odpowiada |
|:---:|:---:|---|
| `b0` | `data[0]` | Dekada 6 (100 kΩ) |
| `b1` | `data[1]` | Dekada 5 (10 kΩ) |
| `b2` | `data[2]` | Dekada 4 (1 kΩ) |
| `b3` | `data[3]` | Dekada 3 (100 Ω) |
| `b4` | `data[4]` | Dekada 2 (10 Ω) |
| `b5` | `data[5]` | Dekada 1 (1 Ω) + bity Q6/Q7 |

```python
raw = inst.query('RELay:RAW?')
bytes_val = [int(x) for x in raw.split(',')]

# Dekodowanie bajtu dekady 1 (b5)
b5 = bytes_val[5]
connect = (b5 >> 6) & 1
short   = (b5 >> 7) & 1
print(f'CONNECT={connect}, SHORT={short}')
print(f'Bity Q0-Q5 dekady 1: {b5 & 0x3F:06b}')
```

---

## `RELay:STATe`

Ustawia pojedynczy bit Q bez sekwencji ochronnej.

**Składnia:** `RELay:STATe <decade>,<bit>,<state>`

**Parametry:**

| Parametr | Typ | Zakres | Opis |
|---|:---:|:---:|---|
| `<decade>` | Integer | 1–6 | Numer dekady |
| `<bit>` | Integer | 0–5 | Numer bitu Q |
| `<state>` | Bool | ON/OFF/1/0 | Żądany stan bitu |

Po tej komendzie wszystkie odczyty `RESistance:DECade?` dla tej dekady zwrócą `UNKN`.

```python
# Włącz bit Q3 w dekadzie 2 (bez sekwencji ochronnej!)
inst.write('RELay:STATe 2,3,ON')
inst.write('RELay:STATe 2,3,1')    # równoważne

# Wyłącz bit Q0 (bypass) w dekadzie 4
inst.write('RELay:STATe 4,0,OFF')
```

---

## `RELay:STATe?`

Odczytuje stan bitu Q.

**Składnia:** `RELay:STATe? <decade>,<bit>`

**Parametry:**

| Parametr | Zakres |
|---|:---:|
| `<decade>` | 1–6 |
| `<bit>` | 0–5 |

**Odpowiedź:** `0` lub `1`

```python
# Sprawdzenie stanu bitu Q0 (bypass) dekady 1
bit = int(inst.query('RELay:STATe? 1,0'))
print('Bypass' if bit else 'Normalny')
```

---

## Typowy przypadek użycia: testowanie sprzętu

```python
# Sekwencja testu: czy każdy przekaźnik reaguje?
import time

inst.write('OUTPut:RELay:ENable ON')
inst.write('OUTPut:STATe OFF')   # SHORT dla bezpieczeństwa

for decade in range(1, 7):
    for bit in range(6):
        inst.write(f'RELay:STATe {decade},{bit},ON')
        time.sleep(0.02)   # 20 ms stabilizacja
        state = int(inst.query(f'RELay:STATe? {decade},{bit}'))
        print(f'd{decade} Q{bit}: {"OK" if state == 1 else "BŁĄD"}')
        inst.write(f'RELay:STATe {decade},{bit},OFF')

# Powrót do normalnego stanu
inst.write('*RST')
```

---

## Tabela podsumowująca

| Komenda | Parametry | Odpowiedź | Opis |
|---|---|---|---|
| `RELay:RAW <xRy>[,...]` | Format `xRy` (dekada×100 + bit) | – | Ustaw bity przez adres |
| `RELay:RAW?` | – | `b0,b1,...,b5` | Odczyt 6 bajtów shift-registrów |
| `RELay:STATe <d>,<b>,<s>` | d=1–6, b=0–5, s=ON/OFF | – | Ustaw pojedynczy bit Q |
| `RELay:STATe? <d>,<b>` | d=1–6, b=0–5 | 0 lub 1 | Odczyt stanu bitu Q |

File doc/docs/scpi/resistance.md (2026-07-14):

# RESistance & OUTPut

Komendy do ustawiania rezystancji i sterowania terminalami wyjściowymi.

---

## `RESistance:VALue`

Ustawia rezystancję wyjściową.

**Składnia:** `RESistance:VALue <ohms>`

**Parametry:**

| Parametr | Typ | Zakres | Opis |
|---|:---:|:---:|---|
| `<ohms>` | Integer | 0–999 999 | Żądana rezystancja w omach |

Wartość `0` powoduje:

- SHORT ON, CONNECT OFF (zaciski zwarte)
- Wszystkie dekady ustawione na cyfrę 0

Wartość `> 0` powoduje sekwencję ochronną (SHORT → nastaw dekad → CONNECT):

```python
inst.write('RESistance:VALue 0')       # zwarcie wyjścia
inst.write('RESistance:VALue 4700')    # 4.7 kΩ
inst.write('RESistance:VALue 999999')  # 999.999 kΩ
```

!!! warning "Wartość poza zakresem"
    Wartości < 0 lub > 999 999 generują błąd SCPI `-222,"Data out of range"`.

---

## `RESistance:VALue?`

Odczytuje aktualną rezystancję.

**Składnia:** `RESistance:VALue?`

**Odpowiedź:**

| Tryb kalibracji | Format | Przykład |
|:---:|:---:|:---:|
| Wyłączona (domyślnie) | Integer | `4700` |
| Włączona (`CALibration:ENable ON`) | Float 3 miejsca | `4700.123` |
| Stan nieznany (po `RELay:STATe`) | String | `UNKN` |

```python
# Kalibracja wyłączona
r = inst.query('RESistance:VALue?')
print(int(r))          # 4700

# Kalibracja włączona
r = inst.query('RESistance:VALue?')
print(float(r))        # 4700.123

# Stan nieznany
r = inst.query('RESistance:VALue?')
if r.strip() == 'UNKN':
    print('Rezystancja nieznana – użyj RELay:STATe lub RST')
```

---

## `RESistance:DECade`

Ustawia pojedynczą dekadę.

**Składnia:** `RESistance:DECade <decade>,<digit>`

**Parametry:**

| Parametr | Typ | Zakres | Opis |
|---|:---:|:---:|---|
| `<decade>` | Integer | 1–6 | Numer dekady (1 = 1 Ω, 6 = 100 kΩ) |
| `<digit>` | Integer | 0–9 | Cyfra |

Wkład dekady do łącznej rezystancji:

| Dekada | Jednostka | Cyfra 1 | Cyfra 5 | Cyfra 9 |
|:---:|:---:|:---:|:---:|:---:|
| 1 | 1 Ω | 1 Ω | 5 Ω | 9 Ω |
| 2 | 10 Ω | 10 Ω | 50 Ω | 90 Ω |
| 3 | 100 Ω | 100 Ω | 500 Ω | 900 Ω |
| 4 | 1 kΩ | 1 kΩ | 5 kΩ | 9 kΩ |
| 5 | 10 kΩ | 10 kΩ | 50 kΩ | 90 kΩ |
| 6 | 100 kΩ | 100 kΩ | 500 kΩ | 900 kΩ |

```python
# Ustaw 4 700 Ω = dekada 4 na 4, dekada 3 na 7, reszta 0
inst.write('RESistance:VALue 0')        # najpierw zerownie
inst.write('RESistance:DECade 4,4')     # +4000 Ω
inst.write('RESistance:DECade 3,7')     # +700 Ω
# Łącznie: 4700 Ω
```

---

## `RESistance:DECade?`

Odczytuje aktualną cyfrę dekady.

**Składnia:** `RESistance:DECade? <decade>`

**Parametry:**

| Parametr | Typ | Zakres |
|---|:---:|:---:|
| `<decade>` | Integer | 1–6 |

**Odpowiedź:**

| Wartość | Znaczenie |
|:---:|---|
| `0`–`9` | Aktualna cyfra dekady |
| `UNKN` | Stan nieznany (po komendzie `RELay:STATe`) |

```python
# Odczyt wszystkich cyfr
for d in range(1, 7):
    digit = inst.query(f'RESistance:DECade? {d}')
    print(f'Dekada {d}: {digit}')
```

---

## `OUTPut:STATe`

Steruje podłączeniem sieci rezystorów do zacisków wyjściowych.

**Składnia:** `OUTPut:STATe <state>`

**Parametry:**

| Parametr | Akceptowane wartości |
|---|---|
| `<state>` | `ON`, `1`, `OFF`, `0` |

| Stan | Q6 CONNECT | Q7 SHORT | Efekt |
|:---:|:---:|:---:|---|
| `ON` / `1` | 1 | 0 | Sieć rezystorów podłączona do zacisków |
| `OFF` / `0` | 0 | 1 | Zaciski zwarte do masy |

!!! tip "Dobra praktyka"
    Zawsze zwieraj zaciski (`OUTPut:STATe OFF`) przed i po pomiarze. Chroni to przed przepięciami indukcyjnymi podczas przełączania dekad.

```python
# Przełączanie z odpowiednim opóźnieniem
import time

inst.write('RESistance:VALue 10000')
inst.write('OUTPut:STATe ON')
time.sleep(0.05)                    # 50 ms stabilizacja przekaźników
# ... pomiar ...
inst.write('OUTPut:STATe OFF')
```

---

## `OUTPut:STATe?`

Odczytuje stan wyjścia.

**Składnia:** `OUTPut:STATe?`

**Odpowiedź:** `1` (CONNECT) lub `0` (SHORT)

```python
state = int(inst.query('OUTPut:STATe?'))
print('Wyjście: ' + ('podłączone' if state else 'zwarte'))
```

---

## `OUTPut:RELay:ENable`

Włącza lub wyłącza zasilanie przekaźników (pin REL_EN / PA4).

**Składnia:** `OUTPut:RELay:ENable <state>`

**Parametry:** `ON`, `1`, `OFF`, `0`

!!! warning
    Wyłączenie zasilania (`OFF`) powoduje otwarcie **wszystkich** przekaźników (cewki bez prądu). Zaciski wyjściowe stają się otwarte (rezystancja → ∞), niezależnie od nastawy CONNECT/SHORT. Stan shift-registrów jest zachowany w RAM i zostaje przywrócony po ponownym włączeniu.

```python
inst.write('OUTPut:RELay:ENable OFF')   # wyłącz wszystkie przekaźniki
# ... bezpieczna praca mechaniczna ...
inst.write('OUTPut:RELay:ENable ON')    # włącz z powrotem
```

---

## `OUTPut:RELay:ENable?`

Odczytuje stan zasilania przekaźników.

**Składnia:** `OUTPut:RELay:ENable?`

**Odpowiedź:** `1` (włączone) lub `0` (wyłączone)

---

## Tabela podsumowująca

| Komenda | Parametr | Odpowiedź | Opis |
|---|---|---|---|
| `RESistance:VALue <ohms>` | 0–999 999 | – | Ustaw rezystancję z sekwencją ochronną |
| `RESistance:VALue?` | – | int lub float lub `UNKN` | Odczytaj aktualną rezystancję |
| `RESistance:DECade <d>,<n>` | d=1–6, n=0–9 | – | Ustaw cyfrę jednej dekady |
| `RESistance:DECade? <d>` | d=1–6 | 0–9 lub `UNKN` | Odczytaj cyfrę dekady |
| `OUTPut:STATe <s>` | ON/OFF/1/0 | – | Podłącz lub zwórz zaciski |
| `OUTPut:STATe?` | – | 0 lub 1 | Stan zacisków |
| `OUTPut:RELay:ENable <s>` | ON/OFF/1/0 | – | Zasilanie przekaźników |
| `OUTPut:RELay:ENable?` | – | 0 lub 1 | Stan zasilania przekaźników |

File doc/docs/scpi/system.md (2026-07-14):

# SYSTem – system i diagnostyka

---

## `SYSTem:ERRor[:NEXT]?`

Pobiera i usuwa pierwszy błąd z kolejki SCPI.

**Składnia:** `SYSTem:ERRor?` lub `SYSTem:ERRor:NEXT?`

**Odpowiedź:** `<code>,"<description>"`

| Przykład odpowiedzi | Znaczenie |
|---|---|
| `0,"No error"` | Kolejka pusta |
| `-222,"Data out of range"` | Parametr poza zakresem |
| `-113,"Undefined header"` | Nieznana komenda |

!!! tip "Wzorzec obsługi błędów"
    Zawsze opróżniaj kolejkę po sekwencji komend:
    ```python
    def drain_errors(inst):
        errors = []
        while True:
            resp = inst.query('SYSTem:ERRor?')
            code, desc = resp.split(',', 1)
            if int(code) == 0:
                break
            errors.append((int(code), desc.strip().strip('"')))
        return errors
    ```

---

## `SYSTem:ERRor:COUNt?`

Zwraca liczbę błędów w kolejce bez ich usuwania.

**Składnia:** `SYSTem:ERRor:COUNt?`

**Odpowiedź:** Integer (0–16)

```python
count = int(inst.query('SYSTem:ERRor:COUNt?'))
if count > 0:
    print(f'{count} błędów w kolejce')
```

---

## `SYSTem:VERSion?`

Wersja standardu SCPI zaimplementowanego w urządzeniu.

**Składnia:** `SYSTem:VERSion?`

**Odpowiedź:** `1999.0`

---

## `SYSTem:ID?`

Numer seryjny urządzenia z UID mikrokontrolera STM32G431.

**Składnia:** `SYSTem:ID? [SHORT|LONG]`

**Parametry (opcjonalne):**

| Wartość | Opis |
|:---:|---|
| `SHORT` (domyślne) | 8 znaków HEX – FNV-1a hash 96-bitowego UID MCU |
| `LONG` | 24 znaki HEX – surowe 96 bitów UID MCU |

**Przykłady odpowiedzi:**

```
SYSTem:ID?        → A3F7B201
SYSTem:ID? SHORT  → A3F7B201
SYSTem:ID? LONG   → 0034002B3438510A00360035
```

!!! info "Skąd pochodzi numer seryjny"
    UID STM32G4 to trzy słowa 32-bitowe zapisane w flash at adresie `0x1FFF7590`. Hash FNV-1a (32-bit) zapewnia równomierne rozkładanie wartości – nie ma ryzyka kolizji przy małych wolumenach urządzeń.

```python
serial_short = inst.query('SYSTem:ID?')
serial_long  = inst.query('SYSTem:ID? LONG')
print(f'S/N: {serial_short}')
print(f'UID: {serial_long}')
```

---

## `SYSTem:BOOTloader:ENter`

Wchodzi w tryb bootloadera DFU (Device Firmware Update) przez USB.

**Składnia:** `SYSTem:BOOTloader:ENter`

Sekwencja:

1. Urządzenie ustawia magiczny znacznik w RAM (`0xDEADBEEF` na początku SRAM)
2. Wywołuje `NVIC_SystemReset()`
3. Startup code wykrywa znacznik i przeskakuje do systemowego bootloadera ST (`0x1FFF0000`)
4. Urządzenie pojawia się jako `STM32 BOOTLOADER` w menedżerze urządzeń

!!! warning "Nieodwracalne (do restartu)"
    Po wejściu w bootloader nie można wysyłać komend SCPI. Wymagane fizyczne odłączenie i ponowne podłączenie USB (lub power cycle) po zakończeniu aktualizacji.

**Procedura aktualizacji firmware:**

```bash
# Wejście w bootloader przez SCPI (jeśli połączony)
python -c "import pyvisa; rm=pyvisa.ResourceManager('@py'); \
           inst=rm.open_resource('USB0::0xCAFE::0x4000::...::INSTR'); \
           inst.write('SYSTem:BOOTloader:ENter')"

# Wgranie firmware przez dfu-util (Linux/macOS)
dfu-util -a 0 -s 0x08000000:leave -D RDE_soft.bin

# Lub przez DfuSe (Windows) – GUI aplikacja STMicroelectronics
```

---

## `SYSTem:FRAM:PING?`

Sprawdza obecność modułu FRAM na magistrali I2C.

**Składnia:** `SYSTem:FRAM:PING?`

**Odpowiedź:** `1` (FRAM odpowiada na I2C) lub `0` (NACK/timeout)

```python
ok = int(inst.query('SYSTem:FRAM:PING?'))
print('FRAM OK' if ok else 'FRAM BRAK')
```

!!! note
    Wynik `0` oznacza brak fizycznego modułu lub zablokowaną magistralę I2C. W takim przypadku konfiguracja sieci jest pobierana z flash STM32G4, a kalibracja z wartości nominalnych.

---

## `SYSTem:FRAM:DIAG?`

Diagnostyka magistrali I2C1 – zwraca surowe dane sprzętowe do analizy zawieszenia.

**Składnia:** `SYSTem:FRAM:DIAG?`

**Odpowiedź:** `"<ping>,<isr_hex>,<hal_state>"`

| Pole | Opis |
|---|---|
| `ping` | `1` = FRAM ACK, `0` = NACK/timeout |
| `isr_hex` | Rejestr `I2C1->ISR` w hex (flagi: BUSY, TCR, TC, STOPF, NACKF, RXNE, TXIS, TXE) |
| `hal_state` | `HAL_I2C_GetState()`: `0`=READY, `1`=BUSY, `2`=BUSY_TX, `3`=BUSY_RX |

**Przykładowe odpowiedzi:**

```
"1,0x00000001,0"   → FRAM OK, I2C gotowy
"0,0x00008000,1"   → BRAK FRAM, I2C zablokowany (BUSY bit ustawiony)
```

```python
diag = inst.query('SYSTem:FRAM:DIAG?')
ping, isr, state = diag.split(',')
print(f'ping={ping}  ISR={isr}  state={state}')
```

!!! tip "Kiedy używać"
    Po wykryciu błędów kalibracji lub konfiguracji – pozwala sprawdzić czy problem tkwi w sprzęcie FRAM czy w magistrali I2C. Przy `BUSY=1` w ISR magistrala jest zablokowana i wymaga resetu przez `SYSTem:RST`.

---

## `SYSTem:I2C:SCAN?`

Skanuje magistralę I2C1 w poszukiwaniu podłączonych urządzeń.

**Składnia:** `SYSTem:I2C:SCAN?`

**Odpowiedź:** lista adresów hex rozdzielona przecinkami lub `NONE`

Skanuje adresy 0x08–0x77 z timeoutem 10 ms na adres.

**Przykładowe odpowiedzi:**

```
"0x50"          → tylko FRAM FM24C64B
"0x50,0x51"     → FRAM + drugie urządzenie
"NONE"          → brak urządzeń I2C
```

```python
devices = inst.query('SYSTem:I2C:SCAN?')
print(f'Urządzenia I2C: {devices}')
# Oczekiwany wynik: "0x50"
```

!!! note
    Czas trwania skanu: ~1,7 s (112 adresów × 10 ms timeout przy braku odpowiedzi). Nie używaj w pętli produkcyjnej.

---

## `SYSTem:RST`

Miękki reset mikrokontrolera.

**Składnia:** `SYSTem:RST`

Wywołuje `NVIC_SystemReset()` – pełny restart CPU, peryferiów i stosu aplikacji. Urządzenie wraca do normalnej pracy po ~1 sekundzie.

Różnica względem `*RST`:

| Komenda | Efekt |
|---|---|
| `*RST` | Reset stanu przekaźników do domyślnego (bez restartu CPU) |
| `SYSTem:RST` | Twardy restart CPU – jak power cycle |

!!! note
    `SYSTem:RST` przeładowuje konfigurację z FRAM – przydatne po ręcznej modyfikacji FRAM.

---

## Kody błędów SCPI

| Kod | Kategoria | Opis |
|:---:|:---:|---|
| 0 | – | Brak błędu |
| **Błędy komend** | | |
| -100 | Command | Ogólny błąd komendy |
| -101 | Command | Nieprawidłowy znak |
| -102 | Command | Błąd składni |
| -103 | Command | Nieprawidłowy separator |
| -104 | Command | Typ danych niezgodny |
| -108 | Command | Błąd delimitera parametru |
| -109 | Command | Brakujący parametr |
| -113 | Command | Nieznana komenda (Undefined header) |
| **Błędy wykonania** | | |
| -200 | Execution | Ogólny błąd wykonania |
| -220 | Execution | Błąd parametru |
| -221 | Execution | Ustawienie sprzeczne |
| -222 | Execution | Wartość poza zakresem |
| -223 | Execution | Zbyt dużo danych |
| -224 | Execution | Niedozwolona wartość parametru |
| **Błędy zapytań** | | |
| -400 | Query | Ogólny błąd zapytania |
| -410 | Query | Przerwa zapytania (INTERRUPTED) |
| -420 | Query | Brak danych (UNTERMINATED) |
| **Błędy systemowe** | | |
| -300 | System | Błąd systemowy (np. brak FRAM) |
| -350 | System | Przepełnienie kolejki błędów |

---

## Tabela podsumowująca

| Komenda | Parametry | Odpowiedź | Opis |
|---|---|---|---|
| `SYSTem:ERRor[:NEXT]?` | – | `<code>,"<desc>"` | Pobierz i usuń błąd z kolejki |
| `SYSTem:ERRor:COUNt?` | – | Integer | Liczba błędów w kolejce |
| `SYSTem:VERSion?` | – | `1999.0` | Wersja standardu SCPI |
| `SYSTem:ID? [SHORT\|LONG]` | SHORT/LONG | HEX string | Numer seryjny z UID MCU |
| `SYSTem:BOOTloader:ENter` | – | – | Wejdź w DFU bootloader |
| `SYSTem:RST` | – | – | Miękki reset CPU |
| `SYSTem:FRAM:PING?` | – | `0` lub `1` | Sprawdź obecność FRAM na I2C |
| `SYSTem:FRAM:DIAG?` | – | `ping,isr_hex,state` | Diagnostyka magistrali I2C1 |
| `SYSTem:I2C:SCAN?` | – | lista hex / `NONE` | Skanuj adresy 0x08–0x77 |

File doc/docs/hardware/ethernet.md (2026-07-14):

# Ethernet – W5500

## Układ WIZnet W5500

**W5500** to jednoukładowy sterownik Ethernet z wbudowanym, sprzętowym stosem TCP/IP. Podłączony przez SPI2 do STM32G431.

| Parametr | Wartość |
|---|---|
| Prędkość | 10/100 Mbps |
| Interfejs do MCU | SPI (tryb 0, do 80 MHz) |
| Gniazda sprzętowe | 8 niezależnych (TCP/UDP/MACRAW) |
| Protokoły wbudowane | TCP, UDP, ICMP, IPv4, ARP, IGMP, PPPoE |
| DHCP | Przez bibliotekę ioLibrary (klient) |
| Zasilanie | 3,3 V I/O, wbudowane terminatory magistrali |
| Obudowa | QFN48 |

### Podłączenie SPI2

| Pin MCU | Sygnał | Pin W5500 | Opis |
|:---:|:---:|:---:|---|
| PB12 | SPI2_CS | /SCS | Chip Select (active LOW) |
| PB13 | SPI2_SCK | SCLK | Zegar SPI |
| PB14 | SPI2_MISO | MISO | Dane z W5500 |
| PB15 | SPI2_MOSI | MOSI | Dane do W5500 |
| Pxx | W5500_RST | /RSTn | Reset (active LOW, min 2 µs) |
| Pxx | W5500_INT | INTn | Przerwanie (opcjonalne, polling w v0.3) |

Prędkość SPI2: **10 MHz** (przez prescaler APB1, konfiguracja w `MX_SPI2_Init()`).

---

## Adres MAC

Adres MAC jest generowany z prefiksu **WIZnet OUI** i 3 bajtów z unikalnego numeru seryjnego MCU (`serial_get_full()`):

```c
mac[0] = 0x00;   /* WIZnet OUI – globally administered unicast */
mac[1] = 0x08;
mac[2] = 0xDC;
/* Ostatnie 3 bajty z numeru seryjnego (hex ASCII → binary) */
mac[3] = (serial[0] << 4) | serial[1];
mac[4] = (serial[2] << 4) | serial[3];
mac[5] = (serial[4] << 4) | serial[5];
```

Dzięki temu każde urządzenie ma unikalny adres MAC oparty na zarejestrowanym OUI producenta układu Ethernet (WIZnet Co., Ltd).

!!! info
    Prefix `00:08:DC` to zarejestrowany OUI firmy WIZnet (globally administered). Trzy ostatnie bajty są wyznaczane ze skróconego numeru seryjnego MCU.

---

## Alokacja gniazd

W5500 ma 8 niezależnych gniazd sprzętowych. RDE używa:

| Gniazdo | Protokół | Port | Cel |
|:---:|:---:|:---:|---|
| 0 | UDP | 68 (DHCP) | Klient DHCP |
| 1 | TCP | 111 | Portmapper ONC-RPC |
| 2 | UDP | 111 | Portmapper ONC-RPC |
| 3 | TCP | 703 | VXI-11 Core serwer |
| 4 | UDP | 5353 | mDNS (multicast 224.0.0.251) |
| 5–7 | – | – | Wolne |

---

## PHY i interfejs fizyczny

W5500 ma wbudowany PHY 10/100BASE-T z auto-negocjacją. Podłączony bezpośrednio do złącza RJ-45 z transformatorem (magnetic module lub integrowany w gnieździe).

### Konfiguracja prędkości PHY przez SCPI

Tryb PHY jest konfigurowany w czasie rzeczywistym komendą `NET:PHY:MODE` (integer 0/1/2) i przechowywany w FRAM. Zmiana wchodzi w życie po `NET:APPLy` (restart stosu W5500).

| Kod | Tryb | Komenda SCPI | PHYCFGR (reset/run) | OPMDC | Uwagi |
|:---:|:---:|:---:|:---:|:---:|---|
| `0` | Auto-negocjacja | `NET:PHY:MODE 0` | (domyślne z PMODE) | – | Wymaga dobrego sygnału 100M RX |
| `1` | 10 Mbps half-duplex  | `NET:PHY:MODE 1` | `0x40` / `0xC0` | `000` | Działa przy osłabionym RX |
| `2` | 100 Mbps full-duplex | `NET:PHY:MODE 2` | `0x58` / `0xD8` | `011` | Wymaga dobrego sygnału RX |

!!! danger "Uwaga – nie używaj 0x70/0xF0!"
    Te wartości kodują **OPMDC=110 (PHY Power Down)**, nie 100M FD. Poprawne dla 100BT FD bez auto-neg to **OPMDC=011 → 0x58/0xD8**.

```python
inst.write('NET:PHY:MODE 2')   # 100M FD
inst.write('NET:APPLy')
```

---

## Topologia sieci

```
                 STM32G431
                 ┌────────┐
     SPI2 ───── │ W5500  │ ── MAG ── RJ-45
                │        │
                └────────┘
                     │
               (DHCP klient)
                     │
              ┌──────┴──────┐
              │             │
           Router        Komputer
           (DHCP serwer) (PyVISA)
```

---

## Konfiguracja sieci – wartości domyślne

| Parametr | Wartość domyślna |
|---|:---:|
| DHCP | Włączony |
| Statyczne IP (fallback) | `192.168.1.6` |
| Maska podsieci | `255.255.255.0` |
| Brama domyślna | `192.168.1.1` |
| Link speed | Konfigurowalny przez SCPI `NET:PHY:MODE` (domyślnie: AUTO) |

Zmiana przez SCPI: patrz [NET – konfiguracja sieci](../scpi/network.md).

---

## DHCP – mechanizm

```
w5500_net_init()
   │
   ├── DHCP enabled? ──YES──► DHCP_init() → DHCP_run() (nieblokujące)
   │                              │
   │                              ├── Odpowiedź w < 10s → używaj adresu DHCP
   │                              └── Timeout → fallback na statyczne IP
   │
   └── DHCP disabled? ──YES──► Użyj natychmiast statycznego IP
```

Timeout DHCP: **12 sekund** (`DHCP_TIMEOUT_MS` w `w5500_net.c`).

Po przyznaniu adresu przez DHCP, aktualny adres można odczytać komendą `NET:STATe?`.

---

## mDNS

Urządzenie rozgłasza obecność przez **Multicast DNS** (RFC 6762) na gnieździe 4 (UDP 5353):

- **Hostname**: `RDE-<serial_short>.local` (np. `RDE-A3F7B201.local`)
- **Rekord A**: wskazuje na aktualny adres IP urządzenia
- **Rekord SRV**: usługa `_vxi-11._tcp`, port 703
- **Rekord TXT**: `model=RDE`

Dzięki mDNS można połączyć się z urządzeniem bez znajomości adresu IP:
```
TCPIP::RDE-A3F7B201.local::INSTR
```

---

## VXI-11 – protokół sieciowy

VXI-11 Core działa przez ONC-RPC (Remote Procedure Call) na TCP port **703**. Portmapper (port 111) informuje klienta o tym porcie.

Szczegółowy opis implementacji VXI-11: [API komunikacji](../firmware/comms-api.md).

Konfiguracja sieci przez SCPI: [NET – konfiguracja sieci](../scpi/network.md).

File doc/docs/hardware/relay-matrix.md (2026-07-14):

# Macierz przekaźników rezystancyjnych

## Sterownik STPIC6C595

Każda z 6 dekad jest sterowana przez jeden układ **STPIC6C595TTR** – 8-bitowy shift-register z wyjściami open-drain 50 V / 150 mA (zdolny do bezpośredniego sterowania cewkami przekaźników).

| Parametr | Wartość |
|---|---|
| Napięcie zasilania | 5 V |
| Prąd wyjścia (sink) | 150 mA per kanał, 500 mA suma |
| Napięcie wyjściowe (max) | 50 V |
| Interfejs wejściowy | SPI (MOSI/SCK) + latch (RCLK) |
| Czas propagacji | < 50 ns |
| Liczba układów | 6 (połączone szeregowo) |

### Podłączenie do MCU (SPI1)

```
MCU PA7 (MOSI) ─────────────────────────────────────── SER IN
MCU PA5 (SCK) ──────────────────────────────────────── SRCLK
MCU PA6 (REL_RCK) ──────────────────────────────────── RCLK (latch)
MCU PA4 (REL_EN) ──────── OE\ ─── wszystkie 6 układów  (active LOW!)
                  ┌──────────────────────────────┐
         QH' ─────┤STPIC1 (d1, 1Ω)  data[5]     ├── Q0..Q7
                  ├──────────────────────────────┤
         QH' ─────┤STPIC2 (d2, 10Ω) data[4]     ├── Q0..Q7
                  ├──────────────────────────────┤
         ...  ────┤STPIC3..6                     ├── Q0..Q7
                  └──────────────────────────────┘
```

!!! note "Polaryzacja OE"
    REL_EN (PA4) jest aktywny **HIGH** w firmware (`relay_init()` ustawia PA4=HIGH żeby włączyć wyjścia), ale pin OE układu STPIC6C595 jest aktywny LOW. Między PA4 a OE\ jest inwerter na płycie lub sygnał jest podłączony bezpośrednio (sprawdź schemat v0.3).

### Kolejność danych w łańcuchu

SPI wysyła **6 bajtów** – pierwszy bajt trafia do ostatniego układu w łańcuchu:

| Bajt `data[]` | Układ STPIC | Dekada | Jednostka |
|:---:|:---:|:---:|:---:|
| `data[0]` | STPIC6 | 6 | 100 kΩ |
| `data[1]` | STPIC5 | 5 | 10 kΩ |
| `data[2]` | STPIC4 | 4 | 1 kΩ |
| `data[3]` | STPIC3 | 3 | 100 Ω |
| `data[4]` | STPIC2 | 2 | 10 Ω |
| `data[5]` | STPIC1 | 1 | 1 Ω + Q6/Q7 |

Po wysłaniu 6 bajtów dany jest sygnał RCLK (PA6) – dane przechodzą z shift register do output register.

---

## Topologia sieci rezystorowej

Każda dekada składa się z **5 rezystorów** w topologii drabinkowej 1-2-2-2-2:

```
         Q0  Q1  Q2         Q3         Q4         Q5
(wejście) ●───┤  ├───R1───●───R2───●───R2───●───R2───●───R2───● (wyjście)
               │          │        │        │        │
              (0Ω)       tap1    tap2    tap3    tap4
```

| Przekaźnik | Typ | Rezystancja |
|:---:|:---:|:---:|
| Q0 (SW1) | Bypass | Zwarcie całej dekady → 0 × jednostka |
| Q1 (SW2) | Bypass R1 | Pomija R1 (umożliwia parzyste kroki) |
| Q2 (SW3) | Tap po R1 | Wybór wartości 1× |
| Q3 (SW4) | Tap po R2 | Wybór wartości 3× |
| Q4 (SW5) | Tap po R3 | Wybór wartości 5× |
| Q5 (SW6) | Tap po R4 | Wybór wartości 7× |

---

## Kodowanie cyfr 0–9

Poniższa tabela pokazuje, które bity Q są aktywne dla każdej cyfry każdej dekady. Kodowanie jest identyczne dla wszystkich 6 dekad (tylko wartości jednostkowe różnią się):

| Cyfra | Q0 | Q1 | Q2 | Q3 | Q4 | Q5 | Bajt HEX | Rezystancja |
|:---:|:---:|:---:|:---:|:---:|:---:|:---:|:---:|:---:|
| 0 | 1 | 0 | 0 | 0 | 0 | 0 | `0x01` | 0 × unit |
| 1 | 0 | 1 | 1 | 0 | 0 | 0 | `0x06` | 1 × unit |
| 2 | 0 | 0 | 1 | 0 | 0 | 0 | `0x04` | 2 × unit |
| 3 | 0 | 1 | 0 | 1 | 0 | 0 | `0x0A` | 3 × unit |
| 4 | 0 | 0 | 0 | 1 | 0 | 0 | `0x08` | 4 × unit |
| 5 | 0 | 1 | 0 | 0 | 1 | 0 | `0x12` | 5 × unit |
| 6 | 0 | 0 | 0 | 0 | 1 | 0 | `0x10` | 6 × unit |
| 7 | 0 | 1 | 0 | 0 | 0 | 1 | `0x22` | 7 × unit |
| 8 | 0 | 0 | 0 | 0 | 0 | 1 | `0x20` | 8 × unit |
| 9 | 0 | 0 | 1 | 1 | 0 | 1 | `0x24` | 9 × unit |

!!! note
    Bajt HEX dotyczy **tylko bitów Q0–Q5** (bity 0–5 bajtu). Bity 6 i 7 są używane tylko w bajcie `data[5]` (STPIC1) dla Q6 i Q7.

---

## Przekaźniki ochronne terminali wyjściowych

W bajcie `data[5]` (STPIC1, dekada 1 Ω) bity 6 i 7 sterują **przekaźnikami ochronnymi**:

| Bit | Nazwa | Stan = 1 | Stan = 0 |
|:---:|:---:|---|---|
| 6 | Q6 – CONNECT | Sieć rezystorów podłączona do zacisków | Zaciski odłączone |
| 7 | Q7 – SHORT | Zaciski wyjściowe zwarte do masy | Zaciski otwarte |

### Dozwolone stany Q6/Q7

| Stan wyjścia | Q6 | Q7 | Efekt |
|:---:|:---:|:---:|---|
| **Zwarte** (`OUTPut:STATe OFF`) | 0 | 1 | Zaciski zwarte – bezpieczny stan przy braku pomiaru |
| **Podłączone** (`OUTPut:STATe ON`) | 1 | 0 | Dekady podłączone do zacisków – pomiar możliwy |
| ~~Q6=1, Q7=1~~ | ~~1~~ | ~~1~~ | **Zabroniony** – zwarcie dekad przez SHORT |
| Q6=0, Q7=0 | 0 | 0 | Wyjście otwarte (niezdefiniowane – unikać) |

---

## Sekwencja ochronna

Przy zmianie rezystancji firmware realizuje sekwencję chroniącą przed przepięciami indukcyjnymi:

### Ustawianie R > 0 przy wyjściu podłączonym (CONNECT ON)

```
1. SHORT ON  (Q7=1)          ← zwiera wyjście zanim cokolwiek zmieni się w dekadach
2. Czekaj > 1 ms             ← prąd przez cewki opada
3. Nastawiaj każdą dekadę    ← możliwa dowolna zmiana bitu
4. CONNECT ON, SHORT OFF      ← odblokowanie wyjścia
```

### Przejście do R = 0

```
1. CONNECT OFF               ← odłącza dekady od zacisków
2. SHORT ON                  ← zwiera zaciski
3. Nastawiaj dekadę 1 na cyfrę 0  ← opcjonalnie
```

### Zmiana pojedynczej dekady (`RESistance:DECade`)

```
1. SHORT ON                  ← bezpieczne zwieranie
2. Zmień cyfrę wybranej dekady
3. SHORT OFF (jeśli CONNECT był ON)
```

!!! warning "Pominięcie sekwencji"
    Komendy `RELay:RAW` i `RELay:STATe` **pomijają** sekwencję ochronną. Mogą powodować przepięcia indukcyjne jeśli zmiana dotyczy aktywnego przekaźnika przy podłączonym wyjściu. Używaj tylko w trybie serwisowym.

---

## Prędkość SPI i czas latch

- Prędkość SPI1: 10 MHz (wewnętrzny APB2 / prescaler)
- Czas transferu 6 bajtów: ~5 µs
- Opóźnienie po RCLK: ≥ 50 ns (już gwarantowane przez HAL)
- Czas ustabilizowania przekaźnika: 5–10 ms (typowo dla małych przekaźników sygnałowych)

Firmware czeka minimalnie **1 ms** po każdym przełączeniu gdy wyjście jest aktywne.

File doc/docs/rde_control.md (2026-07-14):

# Aplikacja rde_control.py

Desktopowa aplikacja GUI w Pythonie do sterowania urządzeniem RDE, konfiguracji sieci i przeprowadzania kalibracji z obsługą popularnych multimetrów laboratoryjnych.

**Plik:** `test_tools/rde_control.py`  
**Wersja:** 1.0

---

## Instalacja

```bash
# Wymagane
pip install pyvisa pyvisa-py ttkthemes fpdf2

# Windows – USB-TMC
pip install pyusb
# + zainstaluj sterownik WinUSB przez Zadig dla VID=0xCAFE, PID=0x4000

# Uruchomienie
python test_tools/rde_control.py
```

| Biblioteka | Cel | Wymagana |
|---|-----|:---:|
| `pyvisa` | Interfejs VISA (USB-TMC, VXI-11) | Tak |
| `pyvisa-py` | Backend VISA bez NI-VISA | Tak |
| `ttkthemes` | Motywy Tkinter (wygląd) | Nie |
| `fpdf2` | Generowanie raportu PDF kalibracji | Nie |
| `pyusb` | USB-TMC na Windows | Tak (Windows) |

---

## Architektura kodu

```
rde_control.py
│
├── Stałe (COL_*, DECADE_LABELS, SCPI_ERRORS, NPLC_VALUES, ...)
│
├── Klasy transportu
│   ├── Transport (ABC)            # interfejs bazowy
│   └── VISATransport              # implementacja PyVISA (USB-TMC / VXI-11)
│
├── Klasy multimetrów
│   ├── Multimeter (ABC)           # interfejs bazowy
│   ├── HP34401A                   # HP/Agilent 34401A
│   ├── Agilent34970A              # 34970A z kartą MUX
│   └── Keithley2000               # Keithley 2000/2002
│
├── RDEDevice                      # wrapper komend SCPI dla RDE
│
├── Widżety GUI
│   ├── LogPanel                   # kolorowany panel logów
│   ├── DecadeFrame                # panel sterowania jedną dekadą
│   ├── CalTableFrame              # tabela kalibracyjna 6×10
│   └── NetworkFrame               # panel konfiguracji sieci
│
└── App (tk.Tk / ThemedTk)         # główne okno aplikacji
```

---

## Transport i połączenie

Aplikacja używa PyVISA jako warstwy abstrakcji:

```python
class VISATransport(Transport):
    def __init__(self, resource_name: str, timeout_ms: int = 3000):
        self.rm   = pyvisa.ResourceManager('@py')
        self.inst = self.rm.open_resource(resource_name)
        self.inst.timeout = timeout_ms

    def query(self, cmd: str) -> str:
        return self.inst.query(cmd).strip()

    def write(self, cmd: str) -> None:
        self.inst.write(cmd)
```

### Obsługiwane adresy VISA

| Typ | Format |
|-----|---|
| USB-TMC | `USB0::0xCAFE::0x4000::<serial>::0::INSTR` |
| VXI-11/Ethernet | `TCPIP::<ip>::INSTR` |
| VXI-11/mDNS | `TCPIP::<name>.local::INSTR` |

---

## Klasa RDEDevice

Wrapper wysokopoziomowy – każda metoda odpowiada jednej lub kilku komendą SCPI:

```python
class RDEDevice:
    def identify(self) -> str:
        return self.transport.query('*IDN?')

    def reset(self) -> None:
        self.transport.write('*RST')

    def set_resistance(self, ohms: int) -> None:
        self.transport.write(f'RESistance:VALue {ohms}')

    def get_resistance(self) -> str:
        return self.transport.query('RESistance:VALue?')

    def set_decade(self, decade: int, digit: int) -> None:
        self.transport.write(f'RESistance:DECade {decade},{digit}')

    def set_output(self, connected: bool) -> None:
        self.transport.write(f'OUTPut:STATe {"ON" if connected else "OFF"}')

    def cal_set(self, decade: int, digit: int, milliohm: int) -> None:
        self.transport.write(f'CALibration:DECade {decade},{digit},{milliohm}')

    def cal_save(self) -> None:
        self.transport.write('CALibration:SAVE')

    def get_errors(self) -> list[tuple[int, str]]:
        errors = []
        while True:
            resp = self.transport.query('SYSTem:ERRor?')
            code, desc = resp.split(',', 1)
            if int(code) == 0:
                break
            errors.append((int(code), desc.strip().strip('"')))
        return errors
```

---

## Sterowniki multimetrów

### HP/Agilent 34401A

```python
class HP34401A(Multimeter):
    def measure_resistance_4w(self) -> float:
        """Pomiar 4-przewodowy (Kelvin)."""
        self.inst.write(f'SENSe:RESistance:NPLCycles {self.nplc}')
        return float(self.inst.query('MEASure:FRESistance?'))
```

Konfiguracja:
- NPLC: 0.02 / 0.2 / 1 / 2 / 10 / 100 (domyślnie 10)
- Rozdzielczość: 4.5 / 5.5 / 6.5 cyfry

### Agilent 34970A

```python
class Agilent34970A(Multimeter):
    def __init__(self, ...):
        # Auto-detekcja kart MUX przez SYSTem:CTYPE?
        cards = self.inst.query('SYSTem:CTYPE? 100').split(',')
        # 34901A / 34902A → OK
        # 34908A → ostrzeżenie (mniejsza dokładność)
        # inne → odrzucone
```

Obsługiwane karty:

| Karta | Obsługa | Opis |
|:---:|:---:|---|
| 34901A | ✓ | 20-kanałowy MUX, 4-przewodowy |
| 34902A | ✓ | 16-kanałowy MUX, 4-przewodowy |
| 34908A | ⚠ | 40-kanałowy, brak 4W – ostrzeżenie |
| Inne | ✗ | Nieobsługiwane |

### Keithley 2000/2002

```python
class Keithley2000(Multimeter):
    def measure_resistance_4w(self) -> float:
        self.inst.write(f':SENSe:FRESistance:NPLCycles {self.nplc}')
        return float(self.inst.query(':MEASure:FRESistance?'))
```

---

## Zakładki GUI

### Sterowanie

```
┌──────────────────────────────────────────┐
│  Rezystancja: [________4700__________]   │
│  [Ustaw]  [0 Ω]  [999999 Ω]  [OFF]      │
│                                          │
│  100 kΩ (d6): [▼][ 0 ][▲]  contrib: 0   │
│   10 kΩ (d5): [▼][ 0 ][▲]  contrib: 0   │
│    1 kΩ (d4): [▼][ 4 ][▲]  contrib: 4000│
│   100 Ω (d3): [▼][ 7 ][▲]  contrib: 700 │
│    10 Ω (d2): [▼][ 0 ][▲]  contrib: 0   │
│     1 Ω (d1): [▼][ 0 ][▲]  contrib: 0   │
│                                          │
│  Łącznie: 4700 Ω                         │
│  Wyjście: [ON]  [OFF]                    │
└──────────────────────────────────────────┘
```

Każda dekada ma przyciski `-`/`+` oraz pole spinbox (0–9). Łączna rezystancja aktualizuje się na żywo (bez wysyłania do urządzenia aż do naciśnięcia [Ustaw]).

### Kalibracja

```
┌────────────────────────────────────────────────┐
│  Multimetr: [HP 34401A ▼]  [Połącz]            │
│  NPLC: [10 ▼]  Próbki: [3]                     │
│                                                 │
│  ┌──────────────────────────────────────────┐   │
│  │      0      1      2  ...      9         │   │
│  │ 1Ω   0    983   1981  ...   8972         │   │
│  │10Ω   0   9990  19988  ...  89910         │   │
│  │ ...                                      │   │
│  └──────────────────────────────────────────┘   │
│                                                 │
│  [Odczyt z RDE]  [Start auto-kalibracji]        │
│  [Zapisz do FRAM]  [Reset nominały]  [PDF]      │
└────────────────────────────────────────────────┘
```

### Konfiguracja sieci

```
┌──────────────────────────────────┐
│  DHCP:  [☑] Włączony             │
│  IP:    [192.168.1.6           ] │
│  Maska: [255.255.255.0         ] │
│  Brama: [192.168.1.1           ] │
│  Aktywny adres: 192.168.1.67    │
│                                  │
│  [Odczyt z RDE]  [Zastosuj]      │
└──────────────────────────────────┘
```

[Zastosuj] wysyła `NET:APPLy` – urządzenie restartuje stos Ethernet.

### Terminal SCPI

Pole tekstowe do ręcznego wpisywania komend z historią i kolorowaniem:

```
[    Wyślij komendę SCPI:  _____________________  ] [Wyślij]

▶ *IDN?
◀ bartkepl,RDE,1.0,A3F7B201
▶ RESistance:VALue 1000
▶ RESistance:VALue?
◀ 1000
⚠ SYSTem:ERRor? → 0,"No error"
```

Kolory logów:

| Kolor | Znaczenie |
|:---:|---|
| Szary | Komendy wysłane (`▶`) |
| Niebieski | Odpowiedzi RDE (`◀`) |
| Czerwony | Błędy SCPI |
| Zielony | Komunikaty systemowe (połączenie, zapis) |

---

## Automatyczna kalibracja – algorytm

```python
def run_auto_calibration(self):
    self.rde.write('CALibration:ENable OFF')
    self.rde.write('OUTPut:STATe ON')

    for decade in range(6, 0, -1):    # od 100kΩ do 1Ω
        for digit in range(10):
            self.rde.set_decade_isolated(decade, digit)
            time.sleep(0.2)            # stabilizacja przekaźnika

            readings = []
            for _ in range(self.num_samples):
                readings.append(self.dmm.measure_resistance_4w())
                time.sleep(0.05)

            avg_ohm = statistics.mean(readings)
            avg_mo  = round(avg_ohm * 1000)
            self.rde.cal_set(decade, digit, avg_mo)

            self.update_table(decade, digit, avg_mo)
            self.update_progress()

    self.rde.cal_save()
    self.rde.write('CALibration:ENable ON')
    self.generate_pdf_report()
```

---

## Raport PDF kalibracji

Generowany przez `fpdf2` w wątku tła (nie blokuje GUI). Uruchamiany przyciskiem **[PDF]** lub automatycznie po zakończeniu auto-kalibracji.

**Nazwa pliku:** `RDE_cal_YYYYMMDD_HHMM.pdf`  
Przykład: `RDE_cal_20260524_1445.pdf`

Raport składa się z czterech części:

**1. Nagłówek**

| Pole | Opis |
|---|---|
| Data i czas | Timestamp kalibracji |
| RDE IDN | Odpowiedź na `*IDN?` |
| Meter IDN | Identyfikacja multimetru |
| Tryb | `4W FRES` lub `2W RES`, NPLC, liczba uśrednień |

**2. Tabela kalibracyjna [mΩ]**

Siatka 6 dekad × 10 cyfr ze zmierzonymi wartościami w miliohmach. Komórki kolorowane wg odchyłki od wartości nominalnej:

| Kolor | Odchyłka |
|:-----:|---|
| Biały | ≤ 1% |
| Żółty | 1–5% |
| Czerwony | > 5% |

**3. Tabela odchyłek od nominału**

- Kolumna `d=0`: bezwzględna wartość zwarcia w mΩ (brak wartości nominalnej)
- Kolumny `d=1..9`: odchyłka procentowa `|zmierzone - nominalne| / nominalne × 100%`
- Ta sama kolorystyka co tabela kalibracyjna

**4. Tabela podsumowująca**

Dla każdej dekady i wiersz zbiorczy `ALL DECADES`:

| Kolumna | Opis |
|---|---|
| Zwarcie d=0 [mΩ] | Offset zwarciowy dekady |
| Średnia odchyłka [%] | Średnia z cyfr 1–9 |
| Maks. odchyłka [%] | Najgorsza cyfra w dekadzie |

---

## Skaner VXI-11

Menu **Narzędzia → Skanuj sieć** skanuje podsieć w poszukiwaniu urządzeń VXI-11:

```python
def scan_vxi11(subnet: str, timeout: float = 0.5):
    for ip in ipaddress.ip_network(subnet, strict=False).hosts():
        try:
            with socket.create_connection((str(ip), 703), timeout=timeout):
                # Spróbuj portmapper query
                idn = probe_vxi11_idn(str(ip))
                if 'RDE' in idn:
                    yield str(ip), idn
        except (socket.timeout, ConnectionRefusedError, OSError):
            pass
```

---

## Katalog błędów SCPI (`SCPI_ERRORS`)

Lokalny słownik opisów dla 30+ kodów błędów SCPI – używany do czytelniejszego logowania:

```python
SCPI_ERRORS = {
      0: "No error",
   -100: "Command error",
   -113: "Undefined header",
   -222: "Data out of range",
   -350: "Queue overflow",
   # ...
}
```

---

## Wymagania systemowe

| Element | Wymaganie |
|---|---|
| Python | 3.9+ |
| pyvisa + pyvisa-py | ≥ 1.13 + ≥ 0.7 |
| ttkthemes | ≥ 3.2 (opcjonalne) |
| fpdf2 | ≥ 2.7 (opcjonalne) |
| pyusb | ≥ 1.2 (Windows, USB-TMC) |
| OS | Windows 10/11, Linux, macOS |

---

## Znane ograniczenia

- Brak auto-reconnect po utracie połączenia (wymaga ręcznego ponownego połączenia)
- Eksport/import tabeli kalibracyjnej do CSV nie zaimplementowany
- Jednoczesna praca multimetru i RDE na tym samym interfejsie USB wymaga dwóch oddzielnych VISA resource managers
- Na Linuksie wymagana reguła udev: `SUBSYSTEM=="usb", ATTRS{idVendor}=="cafe", MODE="0666"`

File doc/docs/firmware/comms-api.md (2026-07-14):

# API komunikacji

Moduł komunikacji obejmuje trzy warstwy: parser SCPI (libscpi), USB-TMC (TinyUSB), oraz VXI-11/Ethernet. Wszystkie trzy współdzielą jeden bufor odpowiedzi.

---

## Bufor współdzielony

```c
// scpi_def.h
extern uint8_t scpi_reply_buf[512];
extern uint16_t scpi_reply_len;
```

```
                ┌──────────────────────┐
                │    libscpi context   │
                │    SCPI_Main_Init()  │
                └──────────┬───────────┘
                           │ wypełnia po każdej komendzie
                           ▼
                  scpi_reply_buf[512]
                      ┌────┴────┐
                      │         │
               usbtmc_app   vxi11_server
               (USB-TMC)   (VXI-11/TCP)
```

!!! warning "Brak mutexa"
    Bufor nie jest chroniony mutexem. Jednoczesne żądania przez USB i Ethernet (od różnych hostów) mogą powodować wyścig danych. W praktyce jest to mało prawdopodobne przy braku RTOS, ale jest to znane ograniczenie.

---

## Parser SCPI – libscpi

### Inicjalizacja

```c
// scpi_def.c

static scpi_t scpi_context;
static char   scpi_input_buf[256];
static scpi_error_t scpi_error_queue[16];

void SCPI_Main_Init(void) {
    SCPI_Init(&scpi_context,
              scpi_commands,         // tablica komend
              &scpi_interface,       // callbacks I/O
              scpi_units_def,        // definicje jednostek SCPI
              "bartkepl", "RDE", "1.0", serial_str,
              scpi_input_buf, sizeof(scpi_input_buf),
              scpi_error_queue, ARRAY_SIZE(scpi_error_queue),
              scpi_reply_buf, sizeof(scpi_reply_buf));
}
```

### Interfejs I/O libscpi

libscpi wywołuje cztery callbacki przez wskaźnik `scpi_interface`:

| Callback | Kiedy wywoływany | Implementacja |
|---|---|---|
| `write(ctx, data, len)` | Przy każdej odpowiedzi komendy | Wypełnia `scpi_reply_buf` |
| `flush(ctx)` | Po zakończeniu komendy | Ustawia `scpi_reply_len` |
| `error(ctx, err)` | Przy błędzie parsowania | Wpisuje do kolejki błędów |
| `control(ctx, name, val)` | Sygnały statusu IEEE 488 | Opcjonalne |

### Przetwarzanie danych wejściowych

```c
// Wejście od USB-TMC:
SCPI_Input(&scpi_context, (char*)buf, len);

// Wejście od VXI-11:
SCPI_Input(&scpi_context, (char*)buf, len);
// → po zakończeniu, scpi_reply_buf zawiera odpowiedź
```

### Poll (nieblokujące)

```c
void SCPI_Main_Poll(void) {
    SCPI_Input(&scpi_context, NULL, 0);  // brak danych → tylko housekeeping
}
```

---

## USB-TMC – TinyUSB

### Konfiguracja deskryptorów USB

```c
// usb_descriptors.c (generowane przez TinyUSB)

#define USB_VID   0xCAFE
#define USB_PID   0x4000

// Klasa USBTMC: Class=0xFE, SubClass=0x03, Protocol=0x01 (USB488)
// Interfejs 0: USBTMC Bulk-OUT (komendy) + Bulk-IN (odpowiedzi) + Interrupt-IN (status)
```

### Maszyna stanów USB-TMC (`usbtmc_app.c`)

```c
typedef enum {
    USBTMC_STATE_IDLE,
    USBTMC_STATE_PROCESSING,
    USBTMC_STATE_REPLY_READY,
} usbtmc_state_t;
```

```c
void usbtmc_app_task_iter(void) {
    switch (state) {

    case USBTMC_STATE_IDLE:
        if (tud_usbtmc_rx_buf_count()) {         // Czy jest nowy pakiet?
            tud_usbtmc_receive_cb(buf, &len);    // Pobierz dane
            if (is_end_of_message(buf, len)) {
                SCPI_Input(&scpi_context, buf, len);
                state = USBTMC_STATE_REPLY_READY;
            }
        }
        break;

    case USBTMC_STATE_REPLY_READY:
        // Host prosi o dane (REQUEST_DEV_DEP_MSG_IN)?
        if (pending_request_dev_dep_in) {
            tud_usbtmc_transmit(scpi_reply_buf, scpi_reply_len, true /* EOM */);
            state = USBTMC_STATE_IDLE;
        }
        break;
    }
}
```

### Obsługiwane MsgID USBTMC

| MsgID | Nazwa | Kierunek | Opis |
|:---:|---|:---:|---|
| 1 | `DEV_DEP_MSG_OUT` | Host → Urządzenie | Komenda SCPI (ASCII) |
| 2 | `REQUEST_DEV_DEP_MSG_IN` | Host → Urządzenie | Żądanie odpowiedzi |
| 3 | `DEV_DEP_MSG_IN` | Urządzenie → Host | Odpowiedź SCPI |
| 128 | `VENDOR_SPECIFIC_OUT` | Host → Urządzenie | Ignorowany |

### Wykrywanie VBUS

```c
// W głównej pętli main.c:
bool vbus = HAL_GPIO_ReadPin(USB_DETECT_GPIO_Port, USB_DETECT_Pin) == GPIO_PIN_SET;

if (vbus && !tud_connected())  tud_connect();    // PA12 (D+) podciągnięty
if (!vbus && tud_connected())  tud_disconnect(); // PA12 LOW
```

Urządzenie nie jest widoczne dla hosta dopóki nie ma napięcia na VBUS (PA11).

---

## VXI-11 – serwer ONC-RPC

### Protokół

VXI-11 Core to protokół RPC (Remote Procedure Call) zdefiniowany przez VXI-11 rev 1.0:

| Element | Wartość |
|---|---|
| Transport | TCP port **703** |
| RPC Program | `0x0607AF` |
| RPC Version | `1` |
| Portmapper | UDP+TCP port 111 |

### Obsługiwane procedury RPC

| Numer RPC | Nazwa | Opis |
|:---:|---|----|
| 10 | `create_link` | Otwiera sesję instrumentu, zwraca `link_id` |
| 11 | `device_write` | Wysyła dane do parsera SCPI |
| 12 | `device_read` | Odczytuje z `scpi_reply_buf` |
| 15 | `device_clear` | Czyści kolejkę błędów (jak `*CLS`) |
| 17 | `device_remote` | Wejście w tryb zdalny (no-op) |
| 18 | `device_local` | Wyjście z trybu zdalnego (no-op) |
| 23 | `destroy_link` | Zamyka sesję instrumentu |

### Ograniczenia

- **Jedno połączenie naraz** – próba `create_link` gdy sesja już otwarta zwraca błąd `ERR_DEVICE_LOCKED`
- **Brak SRQ** (Service Request) – przerwanie instrumentu niezaimplementowane
- **Brak Lock** mechanizmu (VXI-11 `device_lock` ignorowany)

### Przepływ połączenia

```
Klient (PyVISA)                     Serwer RDE
      │                                   │
      │── Portmapper TCP:111 ────────────►│ "Gdzie VXI-11 Core?"
      │◄─────────────────── Port 703 ────-│
      │                                   │
      │── TCP connect :703 ─────────────► │
      │── RPC: create_link ─────────────► │ Otwiera sesję
      │◄─────────── link_id=1, error=0 ──-│
      │                                   │
      │── RPC: device_write "*IDN?\n" ──► │ → SCPI_Input()
      │── RPC: device_read ─────────────► │ ← scpi_reply_buf
      │◄── "bartkepl,RDE,1.0,A3F7B201" ──│
      │                                   │
      │── RPC: destroy_link ────────────► │ Zamknięcie sesji
      │── TCP FIN ──────────────────────► │
```

---

## mDNS (`mdns/`)

Implementacja mDNS rozgłasza urządzenie w sieci lokalnej co **~1 sekundę** (TTL = 120 s):

```
Multicast 224.0.0.251:5353 (UDP, gniazdo W5500 nr 4)
  Rekord A:   RDE-A3F7B201.local → <aktualny IP>
  Rekord SRV: _vxi-11._tcp.local → RDE-A3F7B201.local:703
  Rekord TXT: model=RDE
```

---

## Portmapper (`w5500_net.c`)

Portmapper (RFC 1833) informuje klientów VXI-11 o porcie serwera. RDE implementuje uproszczoną wersję obsługującą tylko jeden program:

```
Program:  0x0607AF (VXI-11 Core)
Version:  1
Protocol: TCP → port 703
```

Gniazda 1 (TCP:111) i 2 (UDP:111) obsługują zapytania portmappera.

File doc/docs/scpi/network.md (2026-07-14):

# NET – konfiguracja sieci

Komendy do konfiguracji Ethernet. Zmiany NET:IPADdress/SMASk/GATEway/DHCP są tymczasowe (RAM) do czasu wywołania `NET:APPLy`, które zapisuje je do FRAM i restartuje stos W5500.

---

## `NET:IPADdress`

Ustawia statyczny adres IP.

**Składnia:** `NET:IPADdress <a.b.c.d>`

**Parametry:**

| Parametr | Format | Przykład |
|---|:---:|:---:|
| `<a.b.c.d>` | IPv4 dziesiętny z kropkami | `192.168.10.25` |

!!! note
    Zmiana jest tymczasowa (tylko RAM). Wywołaj `NET:APPLy` aby zapisać i zastosować.

```python
inst.write('NET:IPADdress 192.168.10.25')
```

---

## `NET:IPADdress?`

Odczytuje skonfigurowany statyczny adres IP.

**Składnia:** `NET:IPADdress?`

**Odpowiedź:** `<a.b.c.d>` – aktualnie skonfigurowany statyczny IP (może być inny niż operacyjny gdy DHCP przydzieliło inny adres)

```python
print(inst.query('NET:IPADdress?'))   # 192.168.1.6
```

---

## `NET:SMASk`

Ustawia maskę podsieci.

**Składnia:** `NET:SMASk <a.b.c.d>`

```python
inst.write('NET:SMASk 255.255.255.0')
```

---

## `NET:SMASk?`

Odczytuje maskę podsieci.

**Składnia:** `NET:SMASk?`

**Odpowiedź:** `<a.b.c.d>`

---

## `NET:GATEway`

Ustawia adres bramy domyślnej.

**Składnia:** `NET:GATEway <a.b.c.d>`

```python
inst.write('NET:GATEway 192.168.10.1')
```

---

## `NET:GATEway?`

Odczytuje adres bramy domyślnej.

**Składnia:** `NET:GATEway?`

**Odpowiedź:** `<a.b.c.d>`

---

## `NET:DHCP`

Włącza lub wyłącza klienta DHCP.

**Składnia:** `NET:DHCP <state>`

**Parametry:** `ON`, `1`, `OFF`, `0`

| Stan | Działanie |
|:---:|---|
| `ON` | Urządzenie próbuje uzyskać IP przez DHCP. Po timeout (~10 s) przełącza się na statyczne IP |
| `OFF` | Zawsze używa statycznego IP (NET:IPADdress) |

```python
inst.write('NET:DHCP OFF')           # wyłącz DHCP
inst.write('NET:IPADdress 10.0.0.5')
inst.write('NET:SMASk 255.0.0.0')
inst.write('NET:GATEway 10.0.0.1')
inst.write('NET:APPLy')              # zapisz i zastosuj
```

---

## `NET:DHCP?`

Odczytuje stan flagi DHCP.

**Składnia:** `NET:DHCP?`

**Odpowiedź:** `1` (DHCP włączone) lub `0` (DHCP wyłączone)

---

## `NET:PHY:MODE`

Ustawia tryb prędkości PHY. Zmiana jest tymczasowa (RAM) do czasu wywołania `NET:APPLy`.

**Składnia:** `NET:PHY:MODE <code>`

**Parametry (integer):**

| Kod | Tryb | Opis |
|:---:|:---:|---|
| `0` | `AUTO` | Auto-negocjacja przez piny PMODE (wymaga dobrego sygnału 100M RX) |
| `1` | `10M`  | Wymuś 10 Mbps half-duplex (działa przy osłabionym sygnale RX) |
| `2` | `100M` | Wymuś 100 Mbps full-duplex (wymaga dobrego sygnału RX) |

!!! info "Dlaczego integer?"
    Parser libscpi traktuje `10M`/`100M` jako liczbę z sufiksem mega (M), a nie mnemonik. Integer 0/1/2 jest najbardziej niezawodną formą.

!!! note
    Zmiana jest tymczasowa (tylko RAM). Wywołaj `NET:APPLy` aby zapisać do FRAM i zastosować (wymaga restartu stosu W5500).

```python
inst.write('NET:PHY:MODE 0')   # AUTO (auto-negocjacja)
inst.write('NET:APPLy')

inst.write('NET:PHY:MODE 2')   # 100M FD
inst.write('NET:APPLy')
```

---

## `NET:PHY:MODE?`

Odczytuje skonfigurowany tryb PHY.

**Składnia:** `NET:PHY:MODE?`

**Odpowiedź (human-readable):** `AUTO`, `10M` lub `100M`

```python
print(inst.query('NET:PHY:MODE?'))   # 100M
```

---

## `NET:APPLy`

Zapisuje konfigurację sieci do FRAM i restartuje stos Ethernet.

**Składnia:** `NET:APPLy`

Sekwencja po wywołaniu:

1. Zapisuje `net_config_t` do FRAM (PRIMARY + BACKUP + CRC32)
2. Jeśli FRAM niedostępny: zapisuje do flash STM32G4 (strona 63)
3. Zamyka wszystkie otwarte gniazda W5500
4. Restartuje W5500 z nową konfiguracją
5. Jeśli DHCP=ON: uruchamia klienta DHCP

!!! warning "Chwilowa przerwa w komunikacji"
    Po `NET:APPLy` połączenie TCP/VXI-11 zostaje zerwane (restart stosu). Jeśli zmieniasz IP, musisz nawiązać nowe połączenie pod nowym adresem.

```python
# Kompletna zmiana adresacji
inst.write('NET:DHCP OFF')
inst.write('NET:IPADdress 192.168.20.100')
inst.write('NET:SMASk 255.255.255.0')
inst.write('NET:GATEway 192.168.20.1')
inst.write('NET:APPLy')

# Poczekaj na restart stosu
import time
time.sleep(3)

# Nawiąż połączenie pod nowym adresem
inst.close()
inst = rm.open_resource('TCPIP::192.168.20.100::INSTR')
print(inst.query('*IDN?'))
```

---

## `NET:STATe?`

Odczytuje aktualny operacyjny adres IP.

**Składnia:** `NET:STATe?`

**Odpowiedź:** `<a.b.c.d>` – aktualny adres IP (DHCP lub statyczny)

Różni się od `NET:IPADdress?` gdy DHCP przydzieliło inny adres niż skonfigurowany statyczny.

```python
static_ip = inst.query('NET:IPADdress?')   # 192.168.1.6 (skonfigurowany)
actual_ip  = inst.query('NET:STATe?')       # 192.168.1.100 (przydzielony przez DHCP)
```

---

## Przykład: odczyt pełnej konfiguracji sieci

```python
print(f"DHCP:     {inst.query('NET:DHCP?')}")
print(f"IP:       {inst.query('NET:IPADdress?')}")
print(f"Maska:    {inst.query('NET:SMASk?')}")
print(f"Brama:    {inst.query('NET:GATEway?')}")
print(f"PHY:      {inst.query('NET:PHY:MODE?')}")
print(f"Aktywne:  {inst.query('NET:STATe?')}")
```

Przykładowy wynik:
```
DHCP:     1
IP:       192.168.1.6
Maska:    255.255.255.0
Brama:    192.168.1.1
PHY:      AUTO
Aktywne:  192.168.1.100
```

---

## Wartości domyślne

| Parametr | Wartość domyślna |
|---|:---:|
| DHCP | `ON` |
| Statyczne IP | `192.168.1.6` |
| Maska | `255.255.255.0` |
| Brama | `192.168.1.1` |
| PHY Speed | `AUTO` |

---

## Tabela podsumowująca

| Komenda | Parametry | Odpowiedź | Opis |
|---|---|---|---|
| `NET:IPADdress <ip>` | IPv4 | – | Ustaw statyczny IP (RAM) |
| `NET:IPADdress?` | – | IPv4 | Odczytaj statyczny IP |
| `NET:SMASk <mask>` | IPv4 | – | Ustaw maskę podsieci (RAM) |
| `NET:SMASk?` | – | IPv4 | Odczytaj maskę |
| `NET:GATEway <gw>` | IPv4 | – | Ustaw bramę (RAM) |
| `NET:GATEway?` | – | IPv4 | Odczytaj bramę |
| `NET:DHCP <s>` | ON/OFF/1/0 | – | Włącz/wyłącz DHCP (RAM) |
| `NET:DHCP?` | – | 0 lub 1 | Stan DHCP |
| `NET:PHY:MODE <n>` | 0/1/2 | – | Ustaw tryb PHY (RAM): 0=AUTO, 1=10M, 2=100M |
| `NET:PHY:MODE?` | – | AUTO/10M/100M | Odczytaj tryb PHY |
| `NET:APPLy` | – | – | Zapisz do FRAM i restartuj stos W5500 |
| `NET:STATe?` | – | IPv4 | Aktualny operacyjny adres IP |

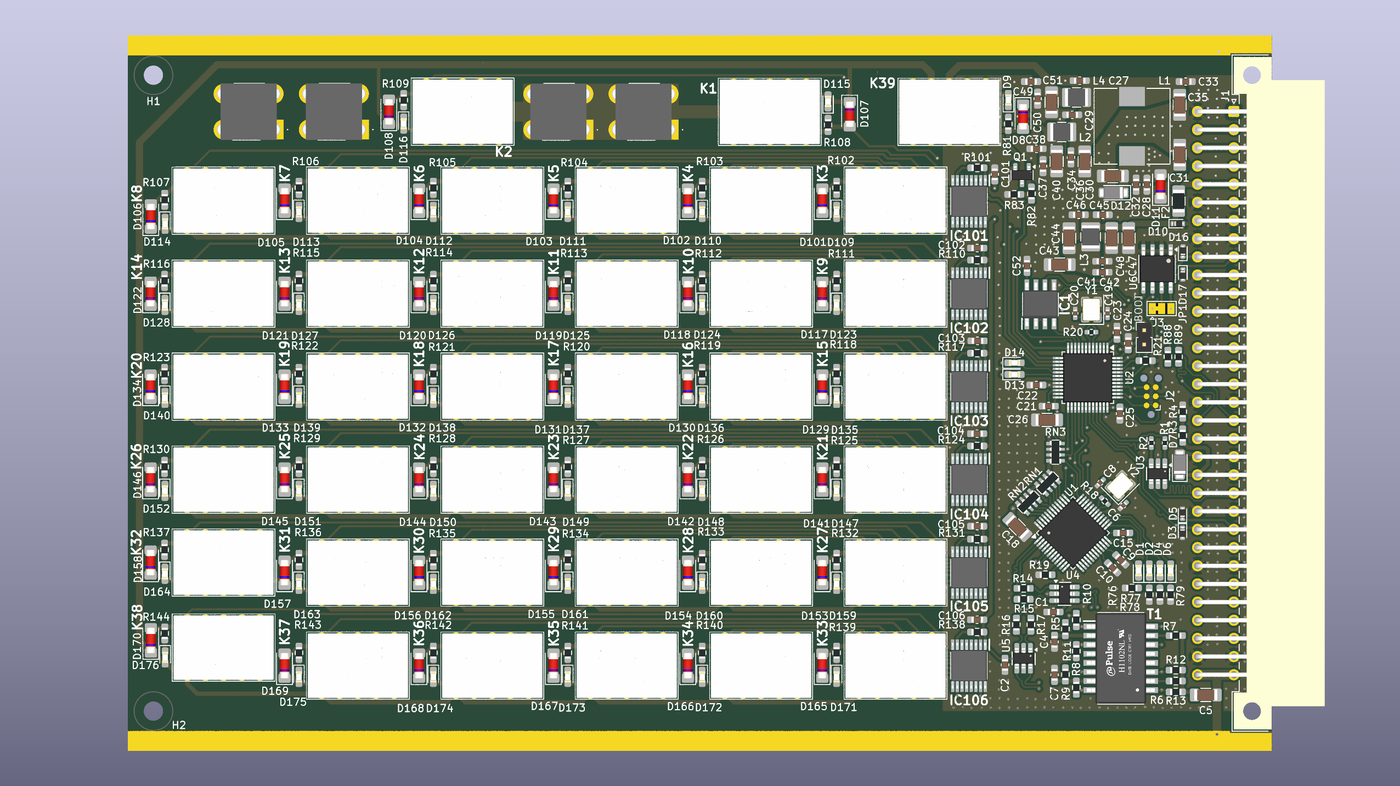
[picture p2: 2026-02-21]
doc/docs/img/RDE_board_front.png

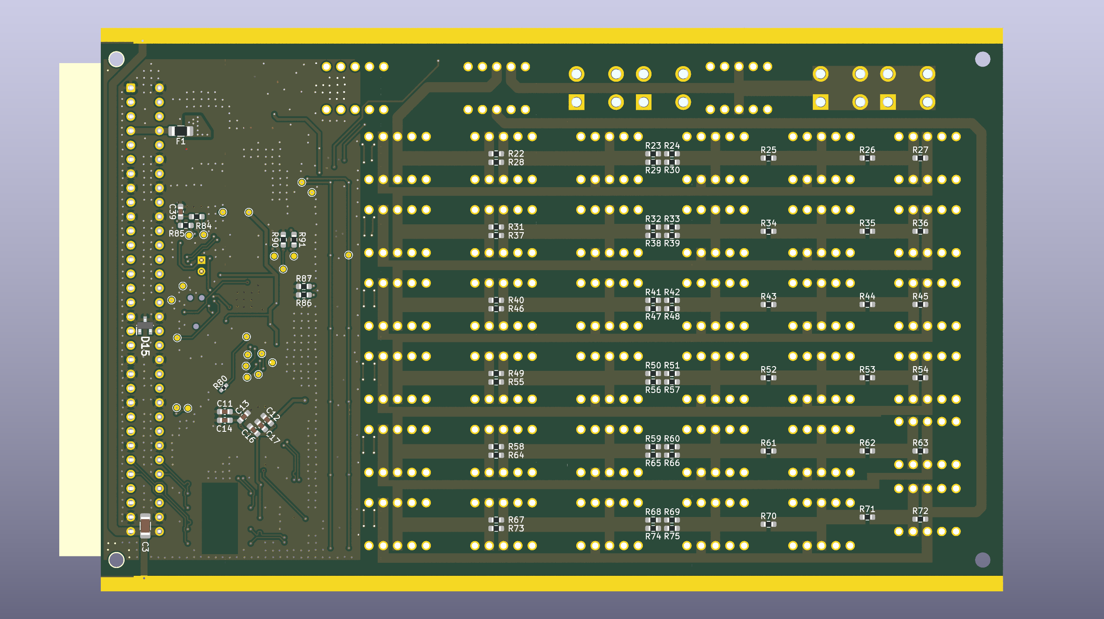
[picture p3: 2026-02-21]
media/RDE_board_back.png

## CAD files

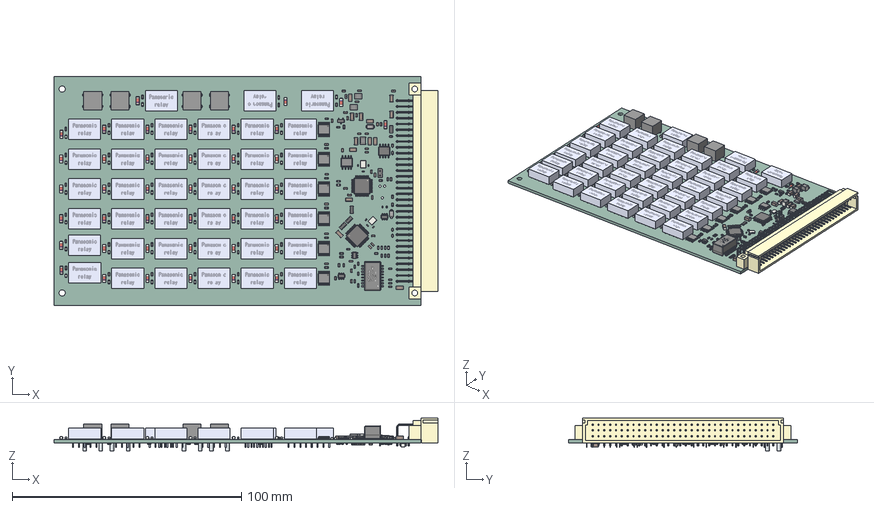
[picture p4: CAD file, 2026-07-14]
mechanical/RDE_board_model.step
167.4 x 100.0 x 14.4 mm
LQFP-48_7x7mm_P0.5mm x 2
LED_0603_1608Metric x 45
TQ2-5V x 39
PinsArrayLR x 6
D_SMF x 2
R_0603_1608Metric x 130
C_0603_1608Metric x 40
SOIC-8_3.9x4.9mm_P1.27mm
C_0402_1005Metric x 4
R_0402_1005Metric x 5
D_MiniMELF x 40
D_SOD-523 x 5
DIN41612_C_2x32_Male_Horizontal_THT
SOT-23-6 x 3
L_1210_3225Metric x 3
C_1206_3216Metric x 14
Leads x 4
Crystal_SMD_3225-4Pin_3.2x2.5mm x 2
R_Array_Convex_4x0603 x 3
Fuse_1206_3216Metric x 2
H1102NL
SOT-23
BODY-SO
LEAD-D0008A x 8
PinHeader_1x02_P2.00mm_Vertical
PinsArrayL
FilletPinR
RDE_board_PCB

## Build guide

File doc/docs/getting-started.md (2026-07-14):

# Pierwsze kroki

## Wymagania

| Element | Minimalne wymaganie |
|---|---|
| Python | 3.9+ |
| PyVISA | ≥ 1.13 |
| pyvisa-py | ≥ 0.7 (bez NI-VISA) lub NI-VISA ≥ 21 |
| System | Windows 10/11, Linux, macOS |
| Kabel | USB Micro-B lub RJ-45 Ethernet |

---

## Podłączenie przez USB

### 1. Instalacja sterownika (Windows)

USBTMC wymaga sterownika libusb na Windows. Bez niego urządzenie nie pojawi się w PyVISA.

1. Pobierz **[Zadig](https://zadig.akeo.ie/)** i uruchom jako Administrator.
2. Podłącz urządzenie kablem USB – powinno się pojawić jako `RDE` lub `USB Serial Device`.
3. W menu *Options* zaznacz **List All Devices**.
4. Wybierz urządzenie z VID = `0xCAFE`, PID = `0x4000`.
5. Wybierz sterownik **WinUSB** i kliknij **Install Driver**.

!!! info "Linux / macOS"
    Sterownik `usbtmc` jest wbudowany w jądro Linux. Na macOS działa przez `pyvisa-py`. Dodaj regułę udev na Linuksie:
    ```
    echo 'SUBSYSTEM=="usb", ATTRS{idVendor}=="cafe", MODE="0666"' | sudo tee /etc/udev/rules.d/99-rde.rules
    sudo udevadm control --reload-rules
    ```

### 2. Instalacja bibliotek Python

```bash
pip install pyvisa pyvisa-py
# Windows USB:
pip install pyusb
```

### 3. Pierwsze połączenie USB

```python
import pyvisa

rm = pyvisa.ResourceManager('@py')      # pyvisa-py bez NI-VISA
resources = rm.list_resources()
print(resources)
# ('USB0::0xCAFE::0x4000::A3F7B201::0::INSTR',)

inst = rm.open_resource('USB0::0xCAFE::0x4000::A3F7B201::0::INSTR')
inst.timeout = 3000
print(inst.query('*IDN?'))
# bartkepl,RDE,1.0,A3F7B201
```

---

## Podłączenie przez Ethernet

### 1. Połączenie fizyczne

Podłącz kabel RJ-45 do tej samej podsieci co komputer. Urządzenie automatycznie pobierze adres przez DHCP.

!!! tip "Wykrywanie adresu IP"
    Sprawdź DHCP lease w routerze lub użyj skanera mDNS:
    ```bash
    # Linux/macOS
    avahi-browse -t _vxi-11._tcp
    # Windows (z Bonjour)
    dns-sd -B _vxi-11._tcp
    ```
    Hostname mDNS: `RDE-<serial>.local`

Domyślny fallback jeśli brak DHCP: **`192.168.1.6`**

### 2. Pierwsze połączenie VXI-11

```python
import pyvisa

rm = pyvisa.ResourceManager('@py')
inst = rm.open_resource('TCPIP::192.168.1.6::INSTR')
inst.timeout = 5000
print(inst.query('*IDN?'))
# bartkepl,RDE,1.0,A3F7B201
```

Lub przez mDNS (Python ≥ 3.13 lub z biblioteką `zeroconf`):

```python
inst = rm.open_resource('TCPIP::RDE-A3F7B201.local::INSTR')
```

---

## Podstawowe komendy SCPI

Po nawiązaniu połączenia możesz od razu sterować urządzeniem:

```python
# Identyfikacja
print(inst.query('*IDN?'))
# bartkepl,RDE,1.0,A3F7B201

# Reset do stanu domyślnego (R = 0 Ω, wyjście zwarte)
inst.write('*RST')

# Ustawienie rezystancji
inst.write('RESistance:VALue 4700')
print(inst.query('RESistance:VALue?'))
# 4700

# Podłączenie wyjścia (CONNECT)
inst.write('OUTPut:STATe ON')
print(inst.query('OUTPut:STATe?'))
# 1

# Zwieranie wyjścia (SHORT – bezpieczny stan pomiarowy)
inst.write('OUTPut:STATe OFF')
```

---

## Kompletny przykład – pomiar 4-przewodowy

```python
import pyvisa
import time

def check_errors(inst):
    """Odczytaj i wydrukuj błędy z kolejki SCPI."""
    while True:
        err = inst.query('SYSTem:ERRor?')
        code, desc = err.split(',', 1)
        if int(code) == 0:
            break
        print(f'  SCPI Error {code}: {desc.strip()}')

rm = pyvisa.ResourceManager('@py')
inst = rm.open_resource('TCPIP::192.168.1.6::INSTR')
inst.timeout = 5000

# Zresetuj i ustaw rezystancję
inst.write('*RST')
inst.write('*CLS')
inst.write('RESistance:VALue 10000')   # 10 kΩ

# Podłącz wyjście – teraz możesz mierzyć
inst.write('OUTPut:STATe ON')
time.sleep(0.1)    # stabilizacja przekaźników

# Odczyt (jeśli kalibracja włączona – wartość ze skrótem mΩ)
r = inst.query('RESistance:VALue?')
print(f'Nastawa: {r} Ω')

check_errors(inst)
inst.write('OUTPut:STATe OFF')   # bezpieczne zwieranie po pomiarze
inst.close()
```

---

## Ustawianie pojedynczej dekady

```python
# Dekada 4 (1 kΩ) = cyfra 7 → wkład 7000 Ω
inst.write('RESistance:DECade 4,7')

# Odczyt cyfry danej dekady
d = inst.query('RESistance:DECade? 4')
print(d)   # 7
```

---

## Sprawdzenie konfiguracji sieci

```python
print(inst.query('NET:DHCP?'))        # 1
print(inst.query('NET:IPADdress?'))   # 192.168.1.6
print(inst.query('NET:STATe?'))       # 192.168.1.67  (adres DHCP)
```

---

## Wejście w bootloader DFU (aktualizacja firmware)

```python
inst.write('SYSTem:BOOTloader:ENter')
# Urządzenie pojawi się jako "STM32 BOOTLOADER" w menedżerze urządzeń
# Wgraj nowy firmware przez DfuSe lub dfu-util
```

!!! warning
    Po wejściu w bootloader urządzenie nie odpowiada na SCPI. Wymagane fizyczne odłączenie i ponowne podłączenie USB po aktualizacji.

---

## Rozwiązywanie problemów

| Objaw | Przyczyna | Rozwiązanie |
|---|---|---|
| Urządzenie niewidoczne w `list_resources()` | Brak sterownika WinUSB | Ponownie uruchom Zadig jako Admin |
| `VISA ERROR -1073807339` | Błędny VID/PID lub brak sterownika | Sprawdź VID=0xCAFE, PID=0x4000 w Zadig |
| Timeout po `*IDN?` | Zbyt krótki timeout | Ustaw `inst.timeout = 5000` |
| LED_R świeci | Błędy w kolejce SCPI | Wywołaj `SYSTem:ERRor?` do wyczyszczenia |
| Brak odpowiedzi przez Ethernet | Urządzenie nie dostało IP | Sprawdź DHCP, użyj statycznego IP |
| `RESistance:VALue?` zwraca `UNKN` | Po komendzie `RELay:STATe` | Ustaw ponownie przez `RESistance:VALue` |

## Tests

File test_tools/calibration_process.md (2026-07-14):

# Proces kalibracji dekady rezystancyjnej RDE_board

## Cel

Kalibracja polega na zmierzeniu rzeczywistej rezystancji dla każdej cyfry (0–9) w każdej z 6 dekad
i wpisaniu tych wartości do pamięci FRAM. Po włączeniu korekcji komenda `RESistance:VALue?` zwraca
rzeczywistą wartość w ohmach (z 3 miejscami po przecinku) zamiast wartości nominalnej.

---

## Wymagany sprzęt

| Sprzęt | Minimalne wymagania |
|---|---|
| Multimetr wzorcowy | 4,5 cyfry (np. Keithley 2000, HP 34401A, Fluke 8846A) |
| Kable pomiarowe | 4-przewodowe Kelvin (pomiar 4-wire) – eliminuje rezystancję przewodów |
| Ewentualnie | 2-przewodowe + zerowanie (REL / NULL) na multimetrze |

> **Uwaga:** Dla dekady 1Ω (1–9 Ω) rezystancja przewodów (~0,1–0,5 Ω) jest istotna.
> Użyj pomiaru 4-wire lub wyzeruj multimetr przy zwartych zaciskach RDE.

---

## Przygotowanie

1. Podłącz multimetr do zacisków wyjściowych RDE (terminale OUTPUT).
2. Połącz się z urządzeniem (VXI-11 lub USB-TMC) przez `rde_tester.py` lub PyVISA.
3. Włącz zasilanie przekaźników:
   ```
   OUTPut:RELay:ENable ON
   OUTPut:STATe ON
   ```
4. Jeśli używasz pomiaru 2-wire: ustaw `RESistance:VALue 0`, zwróć kable na zaciski
   i wyzeruj (NULL/REL) multimetr.

---

## Procedura kalibracji (dekada po dekadzie)

Dla każdej dekady D (1=1Ω, 2=10Ω, 3=100Ω, 4=1kΩ, 5=10kΩ, 6=100kΩ):

### Krok 1: Zeruj pozostałe dekady

```
RESistance:VALue 0
```

Lub ręcznie przez GUI: ustaw wszystkie spinboxy na 0 → `Set All`.

### Krok 2: Kalibruj cyfry 1–9 tej dekady

Dla cyfry N = 1, 2, ..., 9:

```
RESistance:DECade D,N
```

Odczytaj wskazanie multimetru i wpisz wartość w **miliohmach**:

```
CALibration:DECade D,N,<wartość_mΩ>
```

**Przykład** — dekada 1 (1Ω), cyfra 5, zmierzono 4,983 Ω = 4983 mΩ:
```
RESistance:DECade 1,5
CALibration:DECade 1,5,4983
```

### Krok 3: Cyfra 0 (zawsze 0 mΩ)

Cyfra 0 oznacza zwarcie przez przekaźnik SW1 (0 Ω). Wartość nominalna = 0 mΩ.
Jeśli chcesz uwzględnić resztkową rezystancję stykową, możesz wpisać zmierzoną wartość.
W przeciwnym razie zostaw 0 mΩ (wartość domyślna).

---

## Sekwencja SCPI – pełna kalibracja dekady 1 (przykład)

```
RESistance:VALue 0
RESistance:DECade 1,1
CALibration:DECade 1,1,985
RESistance:DECade 1,2
CALibration:DECade 1,2,1978
RESistance:DECade 1,3
CALibration:DECade 1,3,2963
RESistance:DECade 1,4
CALibration:DECade 1,4,3952
RESistance:DECade 1,5
CALibration:DECade 1,5,4941
RESistance:DECade 1,6
CALibration:DECade 1,6,5928
RESistance:DECade 1,7
CALibration:DECade 1,7,6914
RESistance:DECade 1,8
CALibration:DECade 1,8,7902
RESistance:DECade 1,9
CALibration:DECade 1,9,8888
```

Powtórz dla dekad 2–6 (zmieniaj `D` i wpisuj wartości w mΩ).

---

## Zapis do FRAM

Po skalibraniu wszystkich dekad zapisz dane:

```
CALibration:SAVE
```

Dane są przechowywane z CRC-32 i kopią backup — bezpieczne przy utracie zasilania.

---

## Weryfikacja po kalibracji

1. Włącz korekcję:
   ```
   CALibration:ENable ON
   ```

2. Ustaw wartość i sprawdź odczyt:
   ```
   RESistance:VALue 5000
   RESistance:VALue?
   ```
   Odpowiedź będzie w formacie `XXXX.XXX` (ohmy z 3 miejscami po przecinku), np. `4998.450`.

3. Porównaj z multimetrem – powinna być zgodność w granicach dokładności kalibracji.

---

## Kalibracja przez GUI (rde_tester.py)

Sekcja **Calibration** w GUI zawiera:

- **Decade / Digit / Milliohm** – selektor punktu + przycisk `Set Point` i `Query Point`
- **Save to FRAM** – zapisuje wszystkie punkty do FRAM
- **Load from FRAM** – ładuje punkty z FRAM i odświeża tabelę
- **Reset to nominal** – przywraca wartości nominalne w RAM (bez zapisu do FRAM)
- **Enable correction ON/OFF** – włącza/wyłącza korekcję
- **Query All → Table** – odpytuje wszystkie 60 punktów i wyświetla w tabeli

### Zalecana kolejność w GUI

1. Ustaw dekadę i cyfrę spinboxami
2. Wyślij `RESistance:DECade D,N` przez sekcję Decade Control lub pole Manual Command
3. Odczytaj multimetr
4. Wpisz wartość milliohm w polu **Milliohm**
5. Kliknij **Set Point**
6. Powtórz dla wszystkich punktów
7. Kliknij **Save to FRAM**
8. Kliknij **Query All → Table** żeby sprawdzić wpisane wartości

---

## Notatki

- Kalibracja poprawia jedynie **odczyt** (`RESistance:VALue?`). Nastawiona wartość
  (relay_set_resistance) pozostaje nominalna – dekada zawsze ustawia dokładnie te
  przekaźniki które odpowiadają zadanej cyfrze.
- Suma kalibrowanych wartości = `cal[dec1][digit] + cal[dec2][digit] + ... + cal[dec6][digit]`.
  Zakłada niezależność dekad (typowe dla dekad rezystancyjnych klasy 0,1–1%).
- Zalecana rekalibracja po wymianie przekaźników lub elementów rezystancyjnych.
- Dane kalibracyjne przeżywają restart i wyłączenie zasilania (FRAM, >10^13 cykli zapisu).

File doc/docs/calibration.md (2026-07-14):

# Procedura kalibracji

Kalibracja polega na zmierzeniu rzeczywistej rezystancji każdego stopnia każdej dekady i zapisaniu tych wartości jako punktów korekcyjnych. Komendy SCPI służące do kalibracji opisane są w [CALibration](scpi/calibration.md).

---

## Zasada działania

- Kalibracja **nie zmienia** nastawianych wartości przekaźników
- Korekta jest stosowana tylko przy odpowiedzi na `RESistance:VALue?`
- Dane przechowywane w FRAM – trwałe przez wyłączenie zasilania
- 60 punktów: **6 dekad × 10 cyfr (0–9)**

Gdy kalibracja włączona (`CALibration:ENable ON`):

```
RESistance:VALue?  →  suma mΩ ze wszystkich aktywnych dekad / 1000
                       format: "XXXX.XXX" (3 miejsca po przecinku)
```

---

## Wymagany sprzęt

| Urządzenie | Wymaganie | Obsługa w rde_control.py |
|---|---|:---:|
| **HP/Agilent 34401A** | 4,5–6,5 cyfry, 4-przewodowe (Kelvin) | ✓ |
| **Agilent 34970A** z kartą 34901A/34902A | MUX, 4-przewodowe | ✓ |
| **Keithley 2000/2002** | 4,5–6,5 cyfry, 4-przewodowe | ✓ |
| Inny multimetr 4W | SCPI-kompatybilny | Ręczna obsługa |

Kable 4-przewodowe (Kelvin) do podłączenia z zaciskami wyjściowymi RDE są niezbędne dla dokładności poniżej 1 Ω.

---

## Procedura ręczna (przez SCPI)

### Krok 1: Przygotowanie

```python
inst.write('*RST')               # reset do stanu domyślnego
inst.write('*CLS')               # wyczyść kolejkę błędów
inst.write('CALibration:ENable OFF')  # wyłącz korekcję podczas kalibracji
inst.write('OUTPut:STATe ON')    # podłącz wyjście do sieci rezystorów
```

### Krok 2: Pomiar cyfry 0 każdej dekady (rezystancja zacisku)

Cyfra 0 to bypass – dekada zwarta. Zmierz oporność zacisku i przewodów:

```python
for decade in range(1, 7):
    # Ustaw tylko tę dekadę na 0, resztę też na 0
    inst.write('RESistance:VALue 0')
    # Zmierz multimetrem 4-przewodowo (np. 12 mΩ = 0.012 Ω)
    measured_mo = int(input(f'Dekada {decade}, cyfra 0 [mΩ]: '))
    inst.write(f'CALibration:DECade {decade},0,{measured_mo}')
```

### Krok 3: Pomiar cyfr 1–9

Dla każdej dekady, ustaw tylko tę dekadę na daną cyfrę (pozostałe = 0):

```python
multipliers = {1: 1, 2: 10, 3: 100, 4: 1000, 5: 10000, 6: 100000}

for decade in range(1, 7):
    for digit in range(1, 10):
        # Ustaw tylko jedną dekadę
        inst.write('RESistance:VALue 0')
        inst.write(f'RESistance:DECade {decade},{digit}')
        inst.write('OUTPut:STATe ON')

        nominal_mo = digit * multipliers[decade] * 1000
        print(f'Dekada {decade}, cyfra {digit}: nominal = {nominal_mo/1000:.3f} Ω')

        # Zmierz 4-przewodowo i wpisz wynik w mΩ
        measured_mo = int(input('  Zmierzone [mΩ]: '))
        inst.write(f'CALibration:DECade {decade},{digit},{measured_mo}')

        inst.write('OUTPut:STATe OFF')
```

!!! tip "Kolejność pomiarów"
    Zacznij od dekad 6→1 (od największych). Ciepło wydzielane w mniejszych rezystorach przy dużym prądzie testowym zaburza pomiar. Przy dekadach 100 kΩ – 10 kΩ prąd testowy z multimetru jest minimalny.

### Krok 4: Zapis i aktywacja

```python
inst.write('CALibration:SAVE')       # zapis do FRAM (PRIMARY + BACKUP + CRC32)
inst.write('CALibration:ENable ON')  # włącz korekcję

# Weryfikacja
inst.write('RESistance:VALue 4700')
r = inst.query('RESistance:VALue?')
print(f'Skalibrowane: {r} Ω')       # np. 4700.012
```

---

## Procedura automatyczna (rde_control.py)

Aplikacja `rde_control.py` realizuje pełną automatyczną kalibrację z obsługą multimetru:

1. Uruchom `python test_tools/rde_control.py`
2. Połącz się z RDE (zakładka *Połączenie*)
3. Połącz multimetr przez VISA (zakładka *Kalibracja*)
4. Podłącz kable 4-przewodowe z multimetru do zacisków RDE
5. Kliknij **Start kalibracji automatycznej**

Aplikacja:
- Iteruje przez 60 punktów (dekady 6→1, cyfry 0→9)
- Ustawia dekadę przez `RESistance:DECade`
- Odpytuje multimetr N razy i uśrednia (domyślnie 3 próbki)
- Zapisuje wynik przez `CALibration:DECade`
- Po zakończeniu wywołuje `CALibration:SAVE` i `CALibration:ENable ON`
- Generuje **raport PDF** z wynikami i odchyłkami w ppm

Czas kalibracji: ok. **15–30 minut** (zależy od NPLC multimetru i liczby uśrednień).

---

## Weryfikacja kalibracji

Po kalibracji porównaj wartości nominalne ze skalibrowanymi:

```python
print(f'{"Dekada":>8} {"Cyfra":>6} {"Nominal [Ω]":>14} {"Skalibrowane [Ω]":>18} {"Błąd [ppm]":>12}')

multipliers = {1: 1, 2: 10, 3: 100, 4: 1000, 5: 10000, 6: 100000}
for decade in range(1, 7):
    for digit in range(1, 10):
        inst.write(f'RESistance:DECade {decade},{digit}')
        nominal = digit * multipliers[decade]
        cal_mo  = int(inst.query(f'CALibration:DECade? {decade},{digit}'))
        cal_ohm = cal_mo / 1000.0
        ppm     = (cal_ohm - nominal) / nominal * 1e6
        print(f'{multipliers[decade]:>8} {digit:>6} {nominal:>14.3f} {cal_ohm:>18.3f} {ppm:>+12.0f}')
```

---

## Typowe wartości odchyłek

Dla rezystorów metalowych (MFR 0,1% tolerancja):

| Dekada | Typowy błąd |
|:---:|:---:|
| 1 Ω | ±5 000 ppm (5 mΩ absolutne) |
| 10 Ω | ±2 000 ppm |
| 100 Ω | ±1 000 ppm |
| 1 kΩ | ±500 ppm |
| 10 kΩ | ±300 ppm |
| 100 kΩ | ±200 ppm |

Kalibracja eliminuje błąd systematyczny rezystorów. Błąd powtarzalności (stabilność termiczna, kontakty przekaźników) pozostaje na poziomie ok. 50–200 ppm.

---

## Mapa danych w FRAM

| Adres FRAM | Zawartość |
|:---:|---|
| `0x0040` | `cal_data_t` PRIMARY (240 B: `uint32_t milliohm[6][10]`) |
| `0x0130` | CRC32 PRIMARY (4 B) |
| `0x0138` | `cal_config_t` PRIMARY (8 B: magic + enabled) |
| `0x0148` | CRC32 cal_config PRIMARY (4 B) |
| `0x0150` | `cal_data_t` BACKUP (240 B) |
| `0x0248` | `cal_config_t` BACKUP (12 B) |

Szczegółowa mapa pamięci: [Pamięć – FRAM i Flash](hardware/memory.md).

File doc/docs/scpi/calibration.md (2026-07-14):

# CALibration – komendy kalibracyjne

Komendy do zarządzania 60-punktową kalibracją rezystancji. Szczegółowa procedura kalibracji z multimetrem opisana jest na stronie [Procedura kalibracji](../calibration.md).

---

## `CALibration:DECade`

Zapisuje punkt kalibracyjny do RAM.

**Składnia:** `CALibration:DECade <decade>,<digit>,<milliohm>`

**Parametry:**

| Parametr | Typ | Zakres | Opis |
|---|:---:|:---:|---|
| `<decade>` | Integer | 1–6 | Numer dekady (1=1Ω, 6=100kΩ) |
| `<digit>` | Integer | 0–9 | Cyfra |
| `<milliohm>` | Integer | 0–900 000 000 | Zmierzona rezystancja w miliohmach |

!!! note "Przelicznik"
    1 Ω = 1 000 mΩ, 1 kΩ = 1 000 000 mΩ.
    Przykład: zmierzono 4.983 Ω → `<milliohm>` = 4983.

**Przykłady:**

```python
# Dekada 1 (1Ω), cyfra 5: zmierzono 4.983 Ω = 4983 mΩ
inst.write('CALibration:DECade 1,5,4983')

# Dekada 4 (1kΩ), cyfra 3: zmierzono 2998.7 Ω = 2998700 mΩ
inst.write('CALibration:DECade 4,3,2998700')

# Cyfra 0 każdej dekady: oporność zacisku i przewodów (np. 12 mΩ)
inst.write('CALibration:DECade 1,0,12')
```

---

## `CALibration:DECade?`

Odczytuje zapisany punkt kalibracyjny.

**Składnia:** `CALibration:DECade? <decade>,<digit>`

**Odpowiedź:** Wartość w miliohmach (Integer)

```python
mo = int(inst.query('CALibration:DECade? 1,5'))
print(f'{mo / 1000:.3f} Ω')    # 4.983 Ω

# Odczyt całej tabeli kalibracyjnej
print(f'{"":8}', end='')
for digit in range(10):
    print(f'{digit:>10}', end='')
print()
for decade in range(1, 7):
    unit = 10**(decade-1)
    print(f'{unit:>6} Ω:', end='')
    for digit in range(10):
        mo = int(inst.query(f'CALibration:DECade? {decade},{digit}'))
        print(f'{mo:>10}', end='')
    print()
```

---

## `CALibration:SAVE`

Zapisuje wszystkie 60 punktów kalibracyjnych do FRAM.

**Składnia:** `CALibration:SAVE`

Operacja zapisuje PRIMARY i BACKUP z CRC32. Dane są trwałe po wyłączeniu zasilania.

!!! warning "Wymaga FRAM"
    Jeśli FRAM jest niedostępny (`*TST?` zwraca 1), komenda zakończy się błędem SCPI. Dane w RAM zostają zachowane do restartu urządzenia.

```python
# Po zmodyfikowaniu punktów kalibracyjnych:
inst.write('CALibration:SAVE')

# Sprawdzenie czy nie było błędu:
err = inst.query('SYSTem:ERRor?')
code = int(err.split(',')[0])
if code == 0:
    print('Kalibracja zapisana do FRAM')
else:
    print(f'Błąd zapisu: {err}')
```

---

## `CALibration:LOAD`

Przeładowuje kalibrację z FRAM do RAM.

**Składnia:** `CALibration:LOAD`

Przydatne po ręcznych zmianach `CALibration:DECade` które chcesz cofnąć (bez restartu urządzenia). Efekt jest taki sam jak restart, ale bez przerwy w pracy.

```python
inst.write('CALibration:DECade 1,5,9999')  # tymczasowa zmiana
# ... testowanie ...
inst.write('CALibration:LOAD')              # cofnij do zapisanej wersji
```

---

## `CALibration:RESet`

Resetuje wszystkie 60 punktów do wartości nominalnych.

**Składnia:** `CALibration:RESet`

Wartości nominalne: `digit × multiplier × 1000` mΩ, gdzie multiplier to 1, 10, 100, ... 100 000.

!!! note
    `CALibration:RESet` **nie zapisuje** do FRAM. Aby utrwalić nominały, wywołaj następnie `CALibration:SAVE`.

```python
# Reset i zapis nominałów
inst.write('CALibration:RESet')
inst.write('CALibration:SAVE')

# Weryfikacja – cyfra 7 dekady 3 (700 Ω nominalnie)
mo = int(inst.query('CALibration:DECade? 3,7'))
print(mo)   # 700000 (700.000 Ω)
```

---

## `CALibration:ENable`

Włącza lub wyłącza stosowanie korekcji kalibracyjnej.

**Składnia:** `CALibration:ENable <state>`

**Parametry:** `ON`, `1`, `OFF`, `0`

| Stan | Efekt na `RESistance:VALue?` |
|:---:|---|
| `OFF` (domyślnie) | Zwraca nominalną wartość całkowitą (np. `4700`) |
| `ON` | Zwraca sumę mΩ ze skalibrowanych punktów podzieloną przez 1000, 3 miejsca po przecinku (np. `4700.123`) |

```python
inst.write('CALibration:ENable ON')
r = inst.query('RESistance:VALue?')
print(float(r))    # 4700.123

inst.write('CALibration:ENable OFF')
r = inst.query('RESistance:VALue?')
print(int(r))      # 4700
```

!!! tip
    Flaga `CALibration:ENable` jest zapisywana do FRAM razem z danymi przez `CALibration:SAVE`. Po restarcie urządzenia stan jest odtwarzany.

---

## `CALibration:ENable?`

Odczytuje stan flagi korekcji.

**Składnia:** `CALibration:ENable?`

**Odpowiedź:** `1` (włączona) lub `0` (wyłączona)

---

## Tabela podsumowująca

| Komenda | Parametry | Odpowiedź | Opis |
|---|---|---|---|
| `CALibration:DECade <d>,<n>,<mΩ>` | d=1–6, n=0–9, mΩ=0..9×10^8 | – | Zapisz punkt kalibracyjny do RAM |
| `CALibration:DECade? <d>,<n>` | d=1–6, n=0–9 | Integer [mΩ] | Odczytaj punkt kalibracyjny |
| `CALibration:SAVE` | – | – | Zapisz 60 punktów do FRAM (PRIMARY + BACKUP + CRC32) |
| `CALibration:LOAD` | – | – | Przeładuj kalibrację z FRAM do RAM |
| `CALibration:RESet` | – | – | Przywróć nominały (bez zapisu do FRAM) |
| `CALibration:ENable <s>` | ON/OFF/1/0 | – | Włącz/wyłącz korekcję kalibracyjną |
| `CALibration:ENable?` | – | 0 lub 1 | Stan korekcji |

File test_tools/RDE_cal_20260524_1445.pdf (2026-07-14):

# RDE Calibration Report

### Date: 2026-05-24 14:45:15 RDE IDN: bartkepl,RDE,15A07EC4,1.0 Meter IDN: HEWLETT-PACKARD,34401A,0,4-1-1

Mode: | 4W (FRES), NPLC=100.0, Avg=13
Decade | d=0 | d=1 | d=2 | d=3 | d=4 | d=5 | d=6 | d=7 | d=8 | d=9
1 Ohm (d1) | 20 | 1264 | 2288 | 3272 | 4293 | 5278 | 6300 | 7284 | 8284 | 9270
10 Ohm (d2) | 19 | 10249 | 20260 | 30229 | 40238 | 50207 | 60217 | 70185 | 80167 | 90137
100 Ohm(d3) | 18 | 100174 | 200106 | 300002 | 399923 | 499819 | 599716 | 699610 | 799536 | 899435
1 kOhm (d4) | 18 | 999116 | 1998034 | 2996850 | 3995659 | 4994489 | 5993378 | 6992187 | 7991022 | 8989879
10 kOhm(d5) | 17 | 9989037 | 19980397 | 29969786 | 39960183 | 49949781 | 59943149 | 69932556 | 79921805 | 89911895
100 kOhm(d6) | 17 | 99898523 | 199781508 | 299671577 | 399558658 | 499449693 | 599327475 | 699218828 | 799106822 | 898998239

### Deviation from Nominal:

Decade | d=0 (mO) | d=1 % | d=2 % | d=3 % | d=4 % | d=5 % | d=6 % | d=7 % | d=8 % | d=9 %
1 Ohm (d1) | 20 | 26.40 | 14.40 | 9.07 | 7.32 | 5.56 | 5.00 | 4.06 | 3.55 | 3.00
10 Ohm (d2) | 19 | 2.49 | 1.30 | 0.76 | 0.60 | 0.41 | 0.36 | 0.26 | 0.21 | 0.15
100 Ohm(d3) | 18 | 0.17 | 0.05 | 0.00 | 0.02 | 0.04 | 0.05 | 0.06 | 0.06 | 0.06
1 kOhm (d4) | 18 | 0.09 | 0.10 | 0.10 | 0.11 | 0.11 | 0.11 | 0.11 | 0.11 | 0.11
10 kOhm(d5) | 17 | 0.11 | 0.10 | 0.10 | 0.10 | 0.10 | 0.09 | 0.10 | 0.10 | 0.10
100 kOhm(d6) | 17 | 0.10 | 0.11 | 0.11 | 0.11 | 0.11 | 0.11 | 0.11 | 0.11 | 0.11

### Summary:

Decade | Short d=0 (mO) | Mean dev % | Max dev %
1 Ohm (d1) | 20 | 8.71 | 26.40
10 Ohm (d2) | 19 | 0.73 | 2.49
100 Ohm(d3) | 18 | 0.06 | 0.17
1 kOhm (d4) | 18 | 0.11 | 0.11
10 kOhm(d5) | 17 | 0.10 | 0.11
100 kOhm(d6) | 17 | 0.11 | 0.11
ALL DECADES | - | 1.63 | 26.40

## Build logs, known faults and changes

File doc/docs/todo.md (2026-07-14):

# Status projektu & TODO

## Co zostało zrealizowane

### Elektronika / PCB

- [x] Projekt schematu elektrycznego (13 arkuszy KiCAD)
- [x] Projekt PCB dwuwarstwowy, format 3U Eurocard 160×100 mm
- [x] Złącze tylne DIN 41612 (montaż w rack 19")
- [x] Sprzętowy stos TCP/IP (W5500 na SPI2)
- [x] Sterowniki shift-register STPIC6C595 (6 układów, łańcuch SPI1)
- [x] Pamięć FRAM FM24C64B (I2C1)
- [x] Interfejs USB 2.0 FS (STM32G4 wbudowany, CRS)
- [x] UART1 (debug), UART2 (RS485 half-duplex)
- [x] Wskaźniki LED (heartbeat + błąd SCPI)
- [x] Zamówienie i składanie prototypu PCB v0.3

### Firmware

- [x] Inicjalizacja STM32G431CBT6 (HAL, zegary, peryferia)
- [x] Obsługa STPIC6C595 – sterowanie 6 dekadami rezystancji
- [x] Sekwencja ochronna przekaźników (zapobiega przepięciom przy przełączaniu)
- [x] Przekaźniki ochronne terminali Q6 (CONNECT) i Q7 (SHORT)
- [x] Parser SCPI (libscpi) – pełna zgodność z IEEE 488.2
- [x] Komendy SCPI: `RESistance`, `OUTPut`, `RELay`, `NET`, `CALibration`, `SYSTem`, IEEE 488.2
- [x] USB-TMC (TinyUSB) z detekcją VBUS
- [x] VXI-11 serwer (ONC-RPC, port 703)
- [x] Portmapper RPC (port 111 TCP+UDP)
- [x] Klient DHCP (WIZnet ioLibrary)
- [x] mDNS/zeroconf discovery
- [x] Sterownik FRAM FM24C64B (I2C)
- [x] Kalibracja 60-punktowa z zapisem do FRAM (PRIMARY + BACKUP + CRC32)
- [x] Konfiguracja sieci w FRAM + fallback na flash STM32G4 (strona 63)
- [x] Numer seryjny z UID MCU (FNV-1a hash)
- [x] Heartbeat LED_G, błąd LED_R
- [x] Komenda `SYSTem:BOOTloader:ENter` (DFU przez USB)

### Oprogramowanie PC

- [x] `rde_control.py` – GUI Tkinter, sterowanie dekadami, kalibracja, config sieci
- [x] Obsługa multimetrów: HP 34401A, Agilent 34970A, Keithley 2000/2002
- [x] Automatyczna kalibracja z raportem PDF
- [x] Skaner VXI-11 w podsieci
- [x] Katalog błędów SCPI z opisami

---

## TODO – do zrobienia

### Krytyczne / Hardware

- [ ] **v0.4**: naprawa problemu tłumienia RX (umożliwi 100 Mbps Ethernet)
- [ ] Weryfikacja wartości rezystorów sieci dekad na płycie v0.3 pod kątem liniowości
- [ ] Testy termiczne (dryf rezystancji w zakresie -20°C do +70°C)

### Firmware

- [ ] **RS485**: zaimplementować obsługę UART2 z half-duplex transceiverem
- [ ] Pełna obsługa SCPI przez UART1 (aktualnie tylko debug)
- [ ] Mutex na buforze `scpi_reply_buf` (zabezpieczenie przed jednoczesnym USB+ETH)
- [ ] Komenda `NET:MACaddress?` – odczyt adresu MAC
- [ ] `CALibration:DATE?` – data ostatniej kalibracji (wymaga RTC lub NTP)
- [ ] Weryfikacja sekwencji ochronnej w ekstremalnych przypadkach (R = 999 999 → 0)
- [ ] Aktualizacja firmware OTA przez Ethernet (prosty HTTP bootloader)

### Oprogramowanie PC

- [ ] Testy `rde_control.py` na docelowym sprzęcie z wszystkimi multimetrami
- [ ] Auto-reconnect po utracie połączenia VISA
- [ ] Eksport/import tabeli kalibracyjnej do CSV
- [ ] Testy regresji dla `scpi_test.py` – automatyczny smoke-test po wgraniu firmware
- [ ] Obsługa RS485 w `rde_control.py` (gdy firmware gotowe)
- [ ] Pakiet instalacyjny (PyInstaller exe dla Windows)

### Dokumentacja

- [ ] Schemat elektryczny jako PDF w dokumentacji (link do `prod/`)
- [ ] Interaktywny BoM (link do `prod/`)

---

## Znane błędy / ograniczenia

| ID | Opis | Severity | Status |
|----|---|:---:|:---:|
| HW-01 | PCB v0.3: tłumienie RX Ethernet – tylko 10 Mbps half-duplex | Medium | Obejście w FW |
| FW-01 | Brak mutexa na `scpi_reply_buf` – ryzyko przy jednoczesnym USB+ETH | Low | Otwarte |
| FW-02 | RS485 (UART2) niezaimplementowane | Medium | Otwarte |
| SW-01 | `rde_control.py` brak auto-reconnect | Low | Otwarte |

---

## Historia zmian (git)

| Commit | Opis |
|---|---|
| `8cf27d9` | Added FRAM param storage and calibration |
| `c4bb4f2` | Done core functionality – needs polishing |
| `50a9998` | Firmware development – USBTMC done, ETH almost with hardware and soft modifications |
| `19b9de2` | Edited Resistor array to be included in BoM |
| `6d148f0` | Updated revision: v0.3 |

---

## Środowisko pracy

| Narzędzie | Wersja / Uwagi |
|---|---|
| STM32CubeIDE | 1.14+ |
| arm-none-eabi-gcc | 12.x (wbudowany w CubeIDE) |
| KiCAD | 7.x / 8.x |
| Python | 3.9+ |
| ST-Link | V2/V3 (debug i flash) |
| PyVISA | 1.13+ |

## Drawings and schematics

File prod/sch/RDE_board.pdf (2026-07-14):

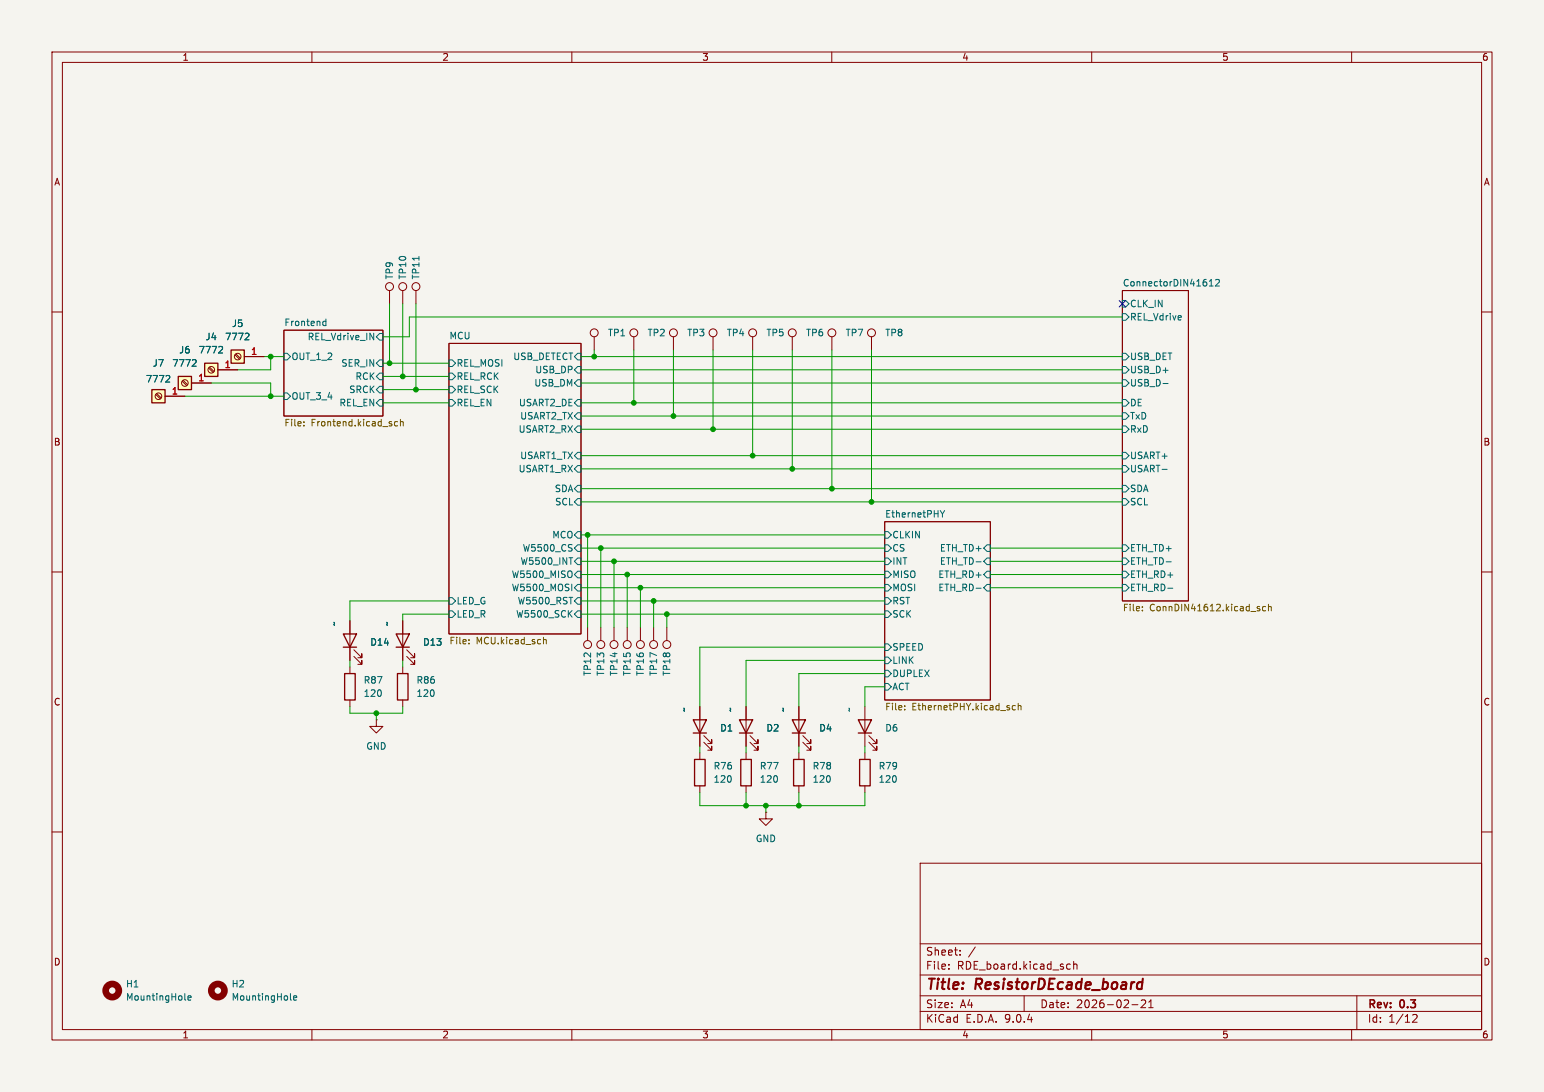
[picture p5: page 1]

USB_DP W5500_CS W5500_INT W5500_MISO W5500_MOSI W5500_RST W5500_SCK MCO
File: RDE_board.kicad_sch Sheet: / ACT CSDUPLEX

SCL SDA ConnectorDIN41612 File: ConnDIN41612.kicad_sch RCK

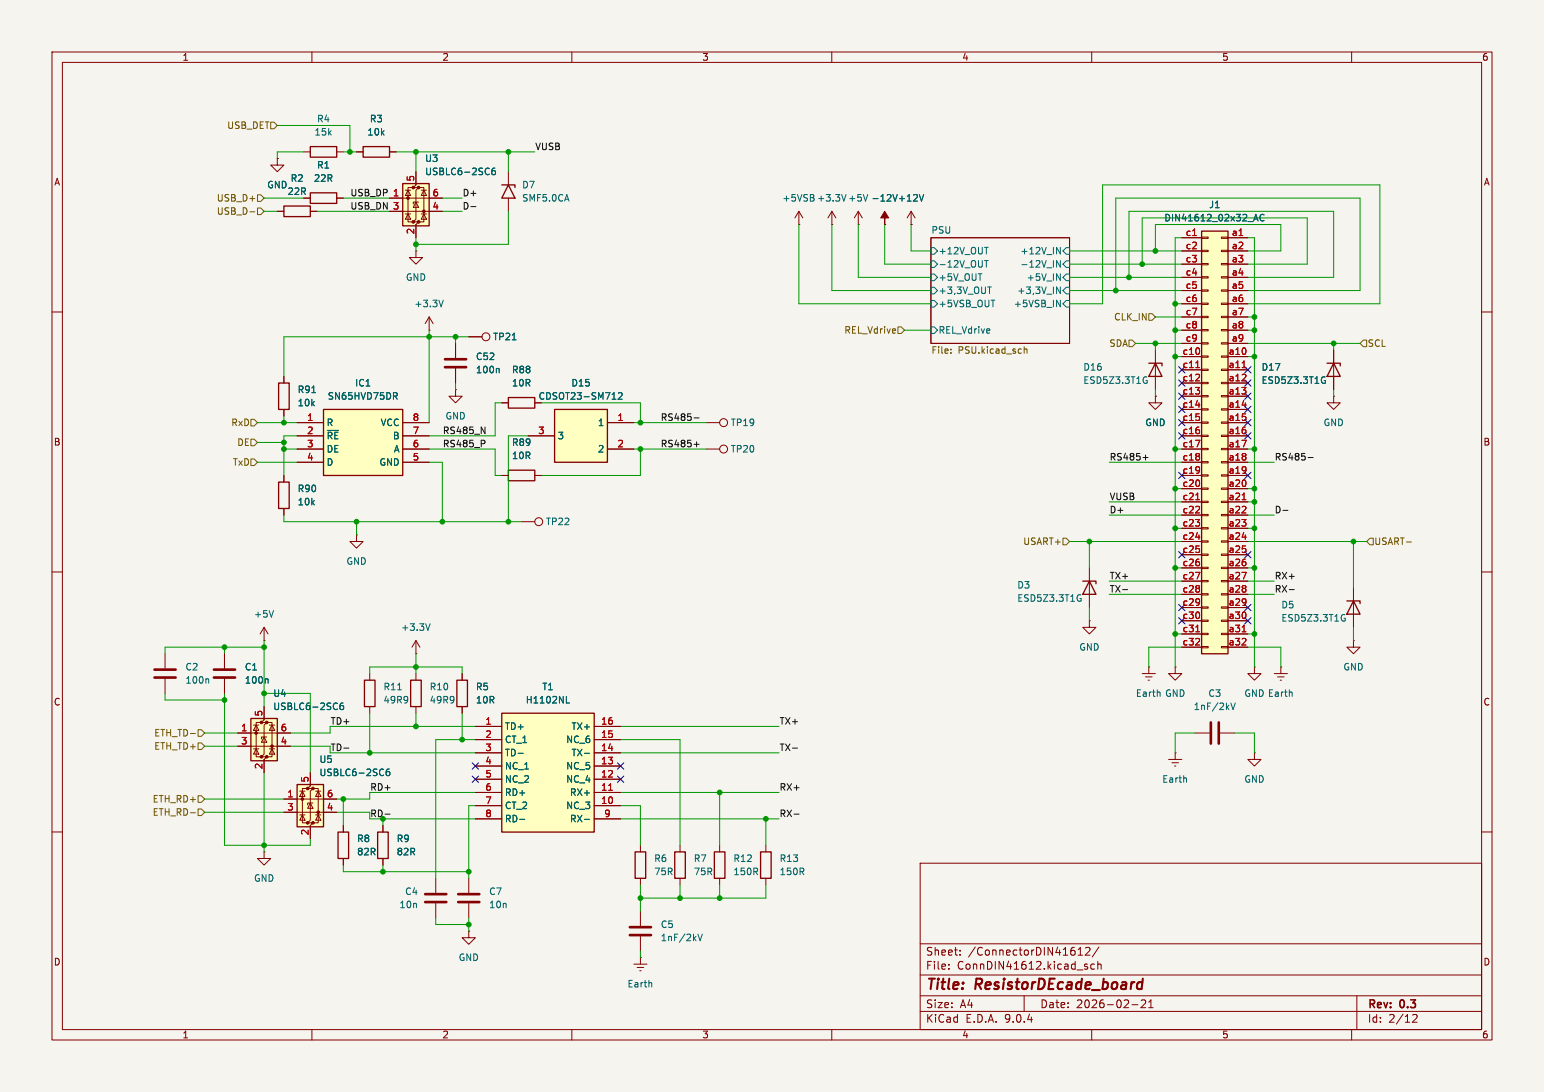
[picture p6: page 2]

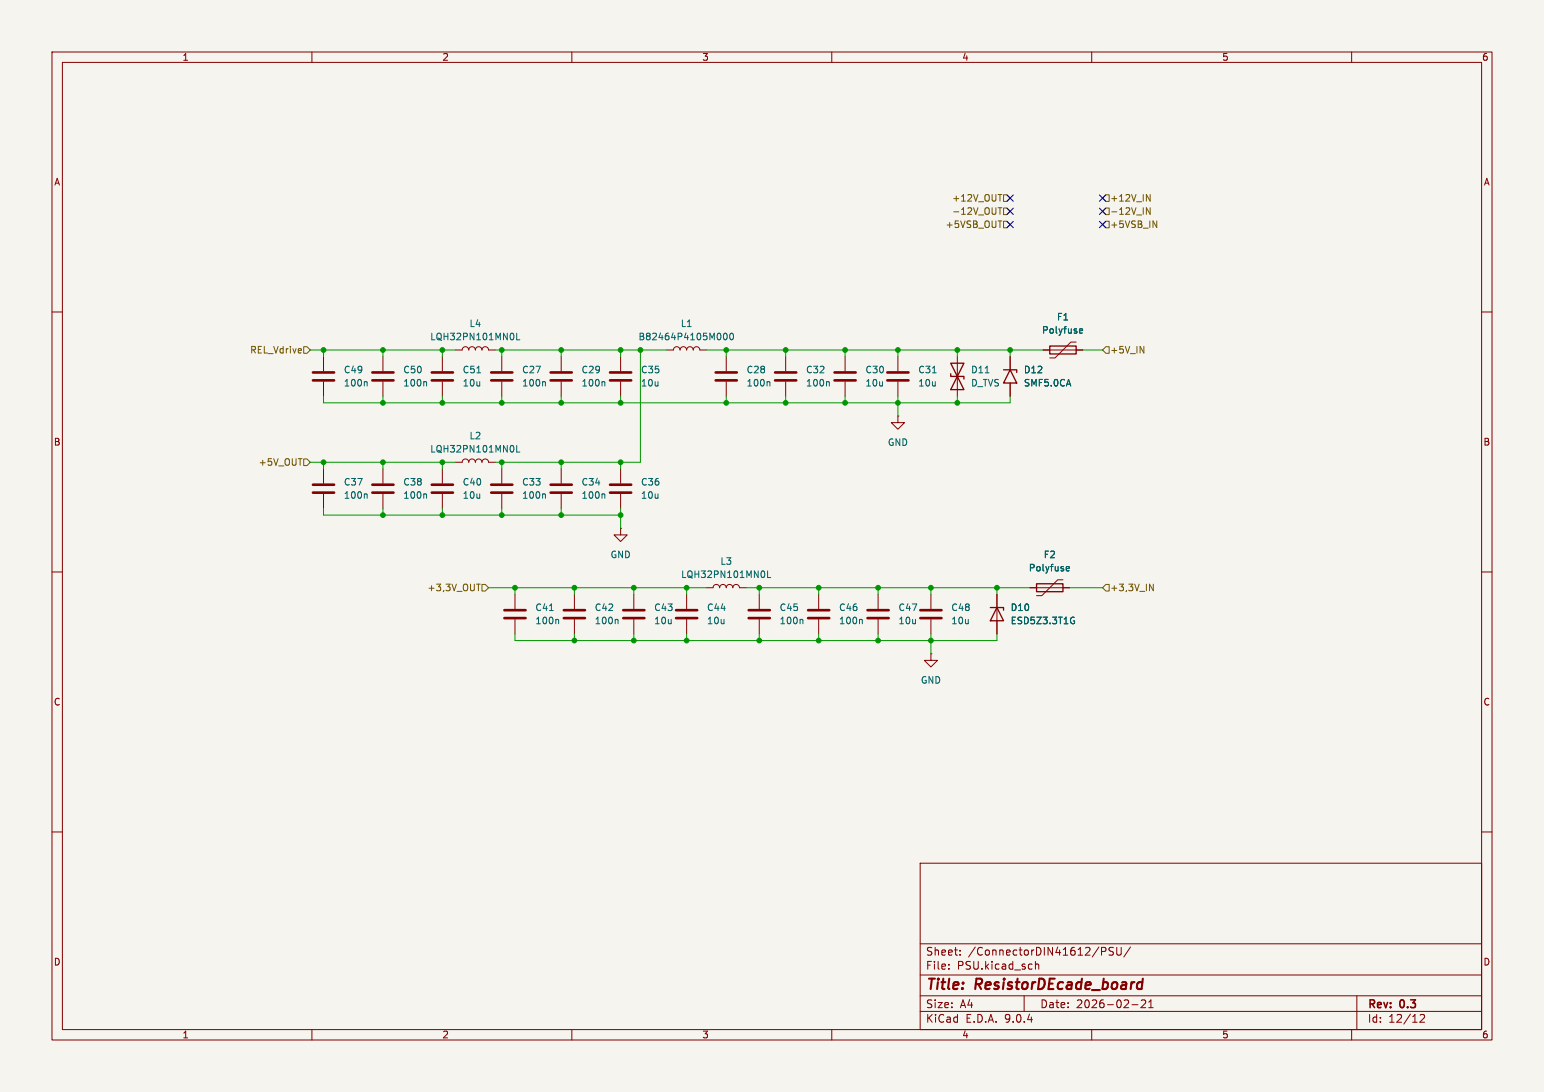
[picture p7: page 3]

File: PSU.kicad_sch Sheet: /ConnectorDIN41612/PSU/
Id: 12/12 Title: ResistorDEcade_board

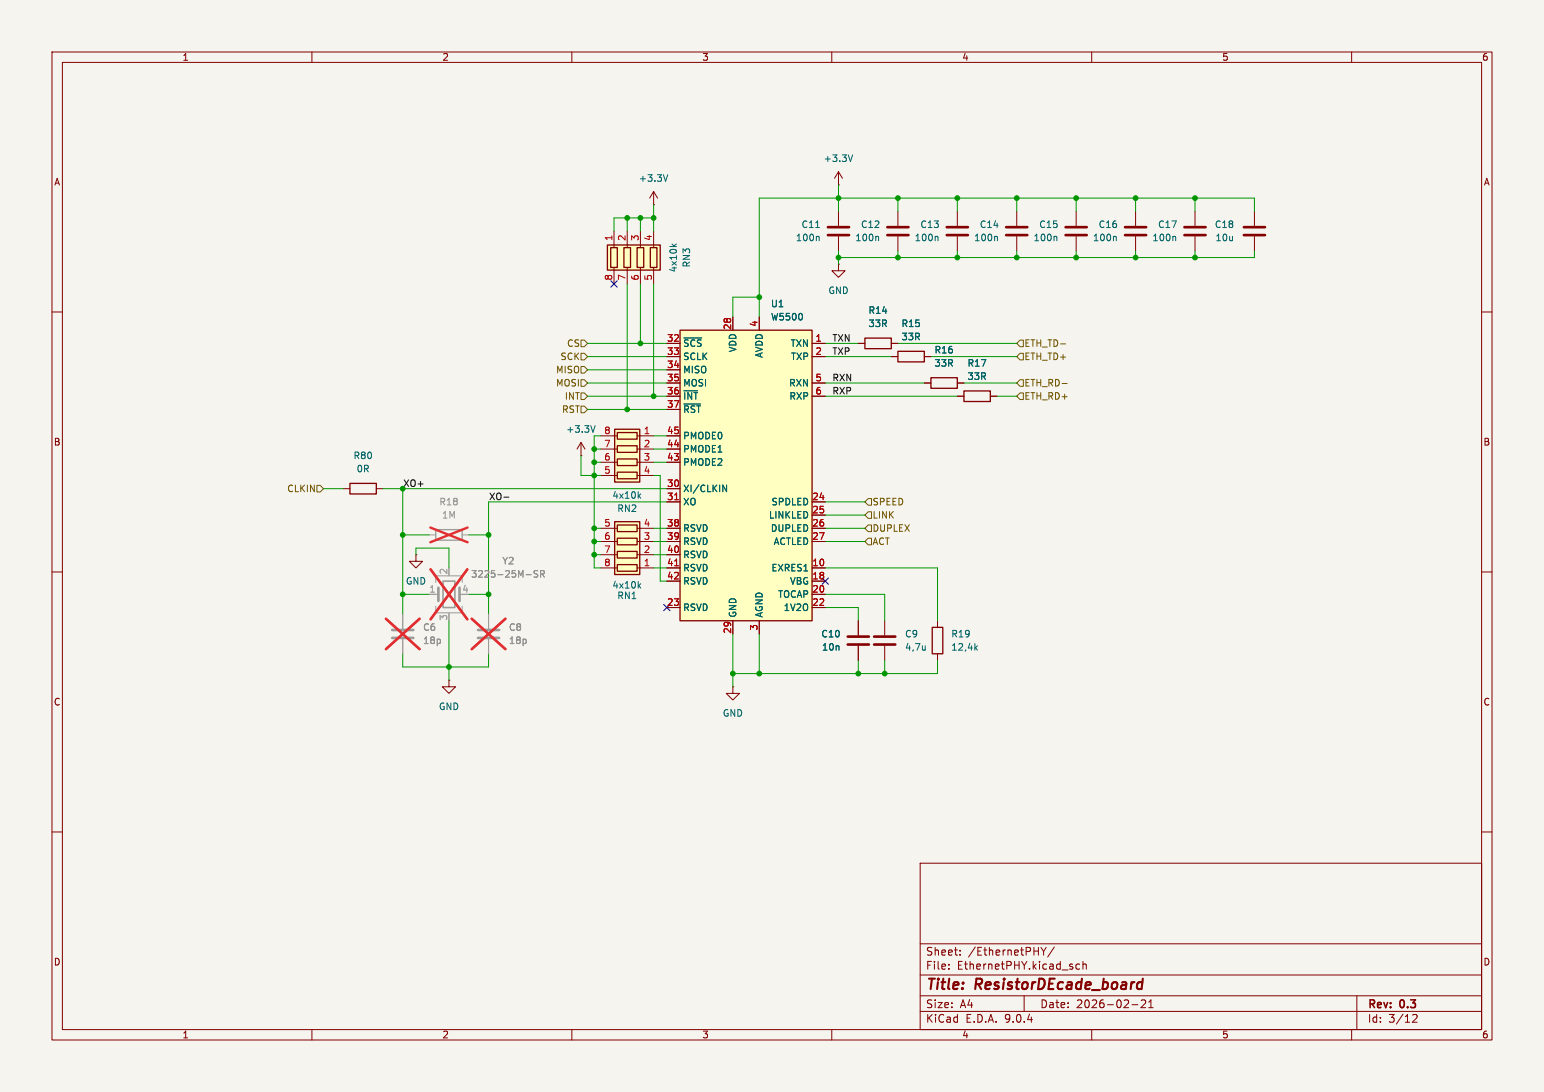
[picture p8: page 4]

CS MOSI SCK MISO

3 TXN 1 TXP 2 RXN 5 RXP 6 SPDLED 24

File: EthernetPHY.kicad_sch Sheet: /EthernetPHY/
Id: 3/12 Title: ResistorDEcade_board

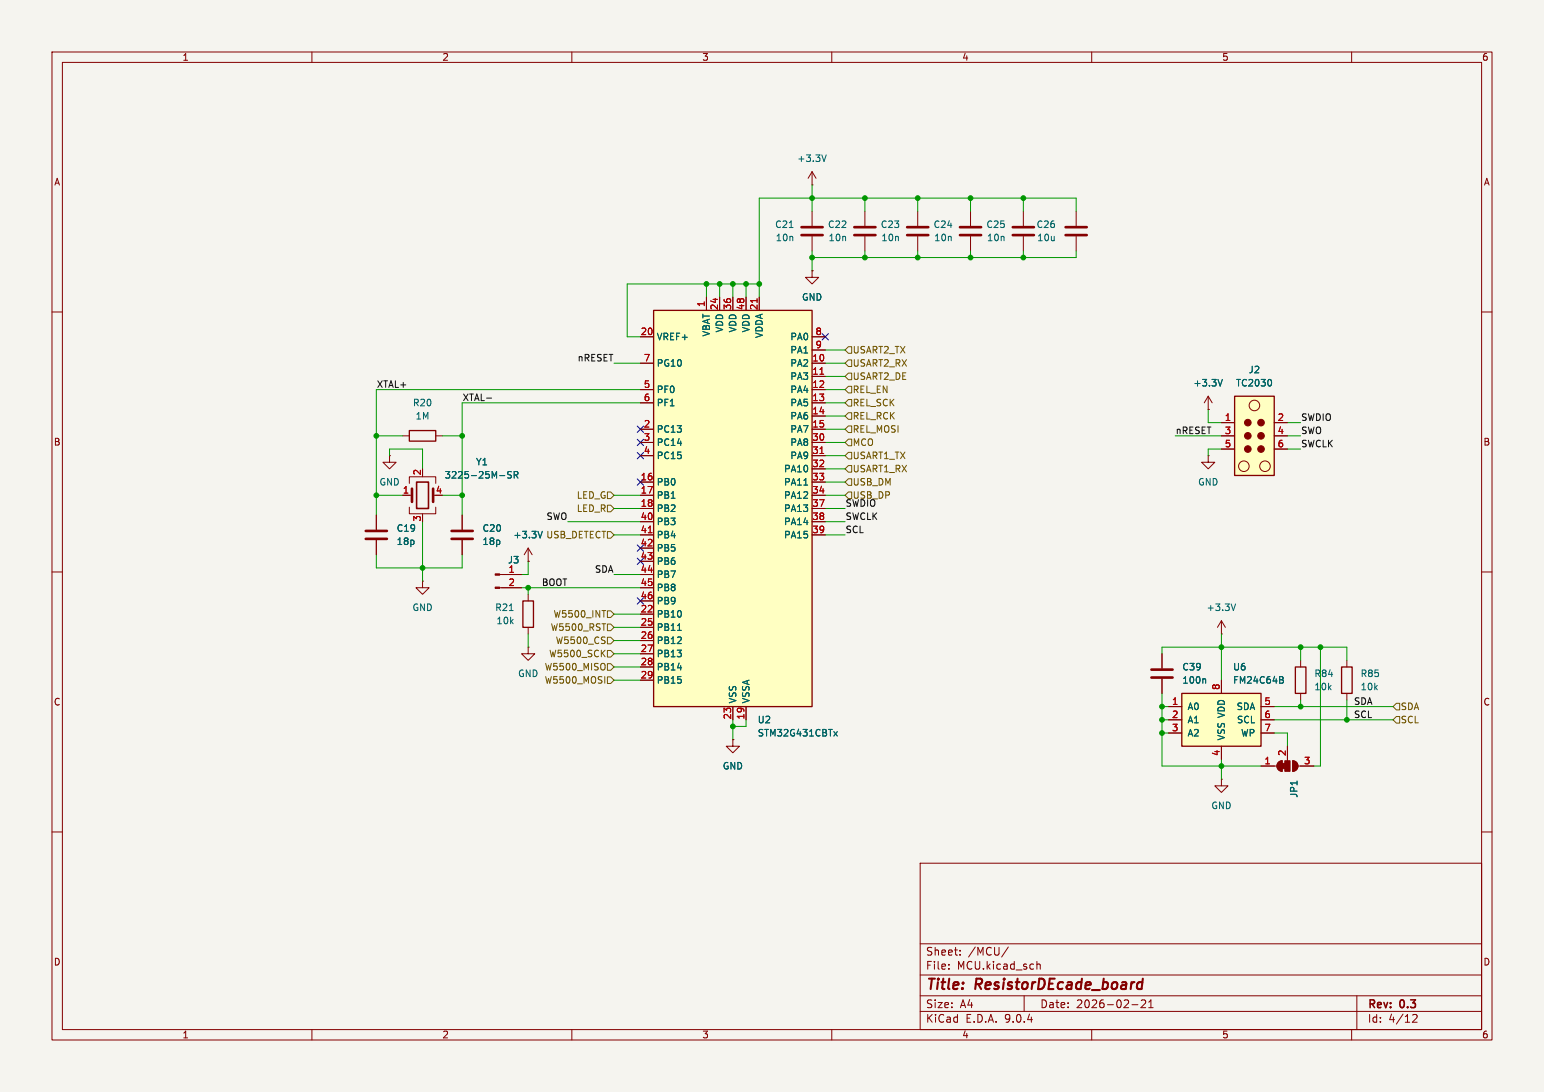
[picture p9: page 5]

1 VDD 24 VDD 36 VSS 23 VDD 48 VSSA 19 VDDA 21 PA0 8 PA1 9 PA2 10 PA3 11 PA4 12 PA5 13 PA6 14 PA7 15 PA8 30 PA9 31 PA10 32 PA11 33 PA12 34 PA13 37 PA14 38 PA15 39 GND GND

1 VDD 24 VDD 36 VSS 23 VDD 48 VSSA 19 VDDA 21 PA0 8 PA1 9 PA2 10 PA3 11 PA4 12 PA5 13 PA6 14 PA7 15 PA8 30 PA9 31 PA10 32 PA11 33 PA12 34 PA13 37 PA14 38 PA15 39 U2STM32G431CBTx GND

File: MCU.kicad_sch Sheet: /MCU/
Id: 4/12 Title: ResistorDEcade_board

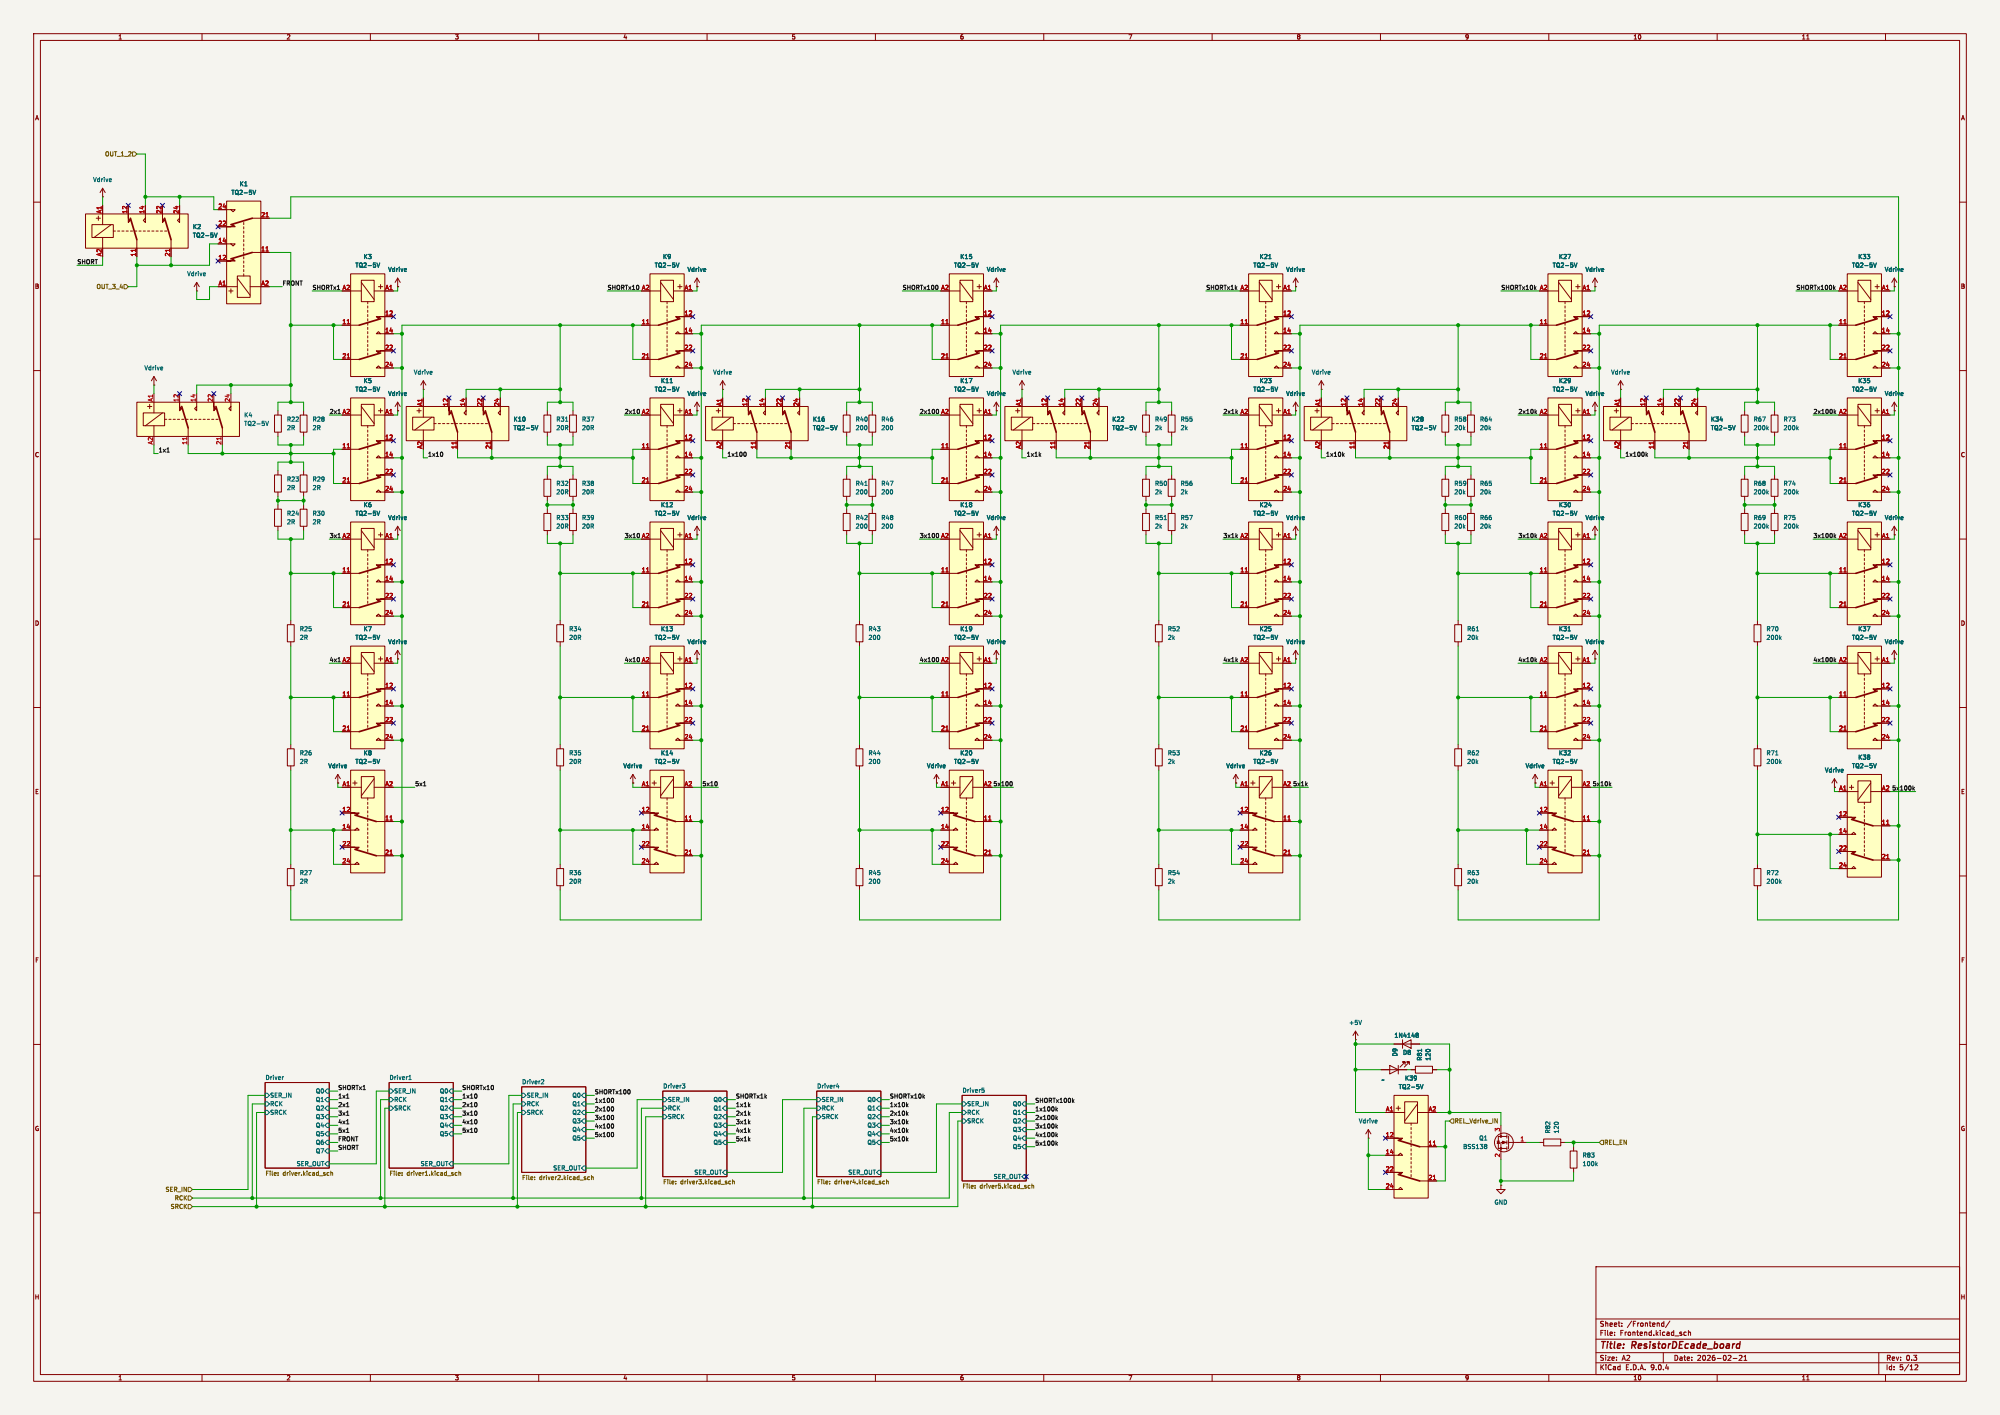
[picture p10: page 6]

File: Frontend.kicad_sch Sheet: /Frontend/ Q0 Q1 Q2 Q3 Q4 Q5 Q6 Q7 RCK
SER_IN

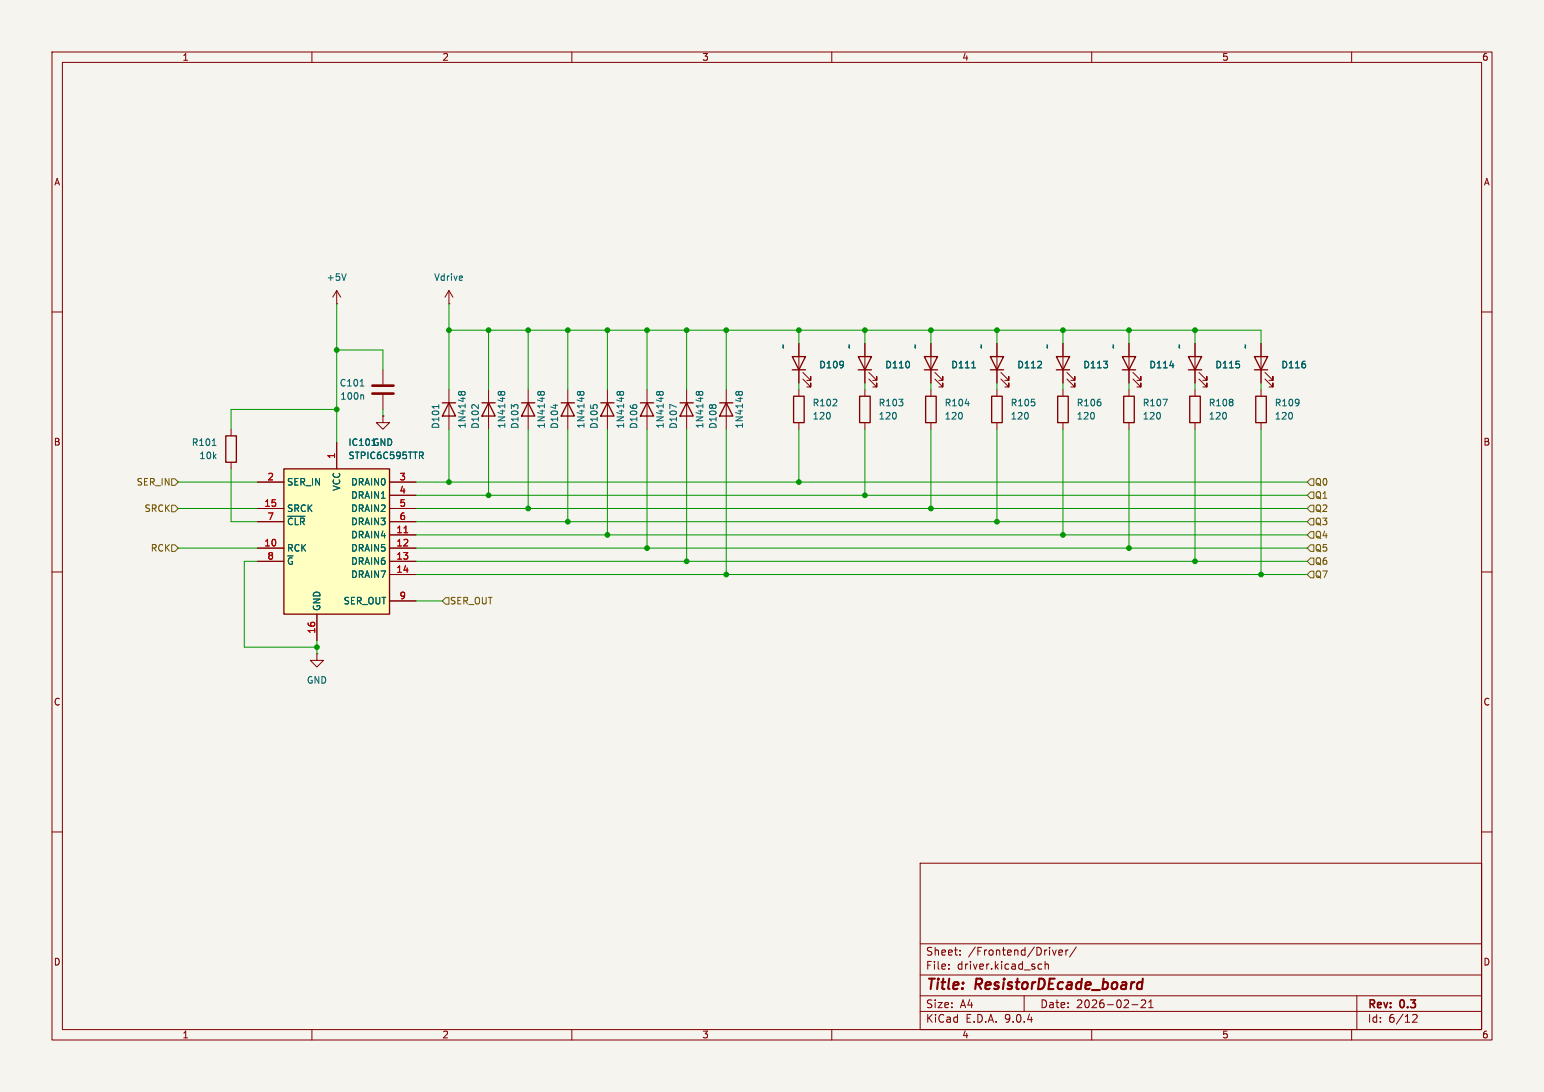
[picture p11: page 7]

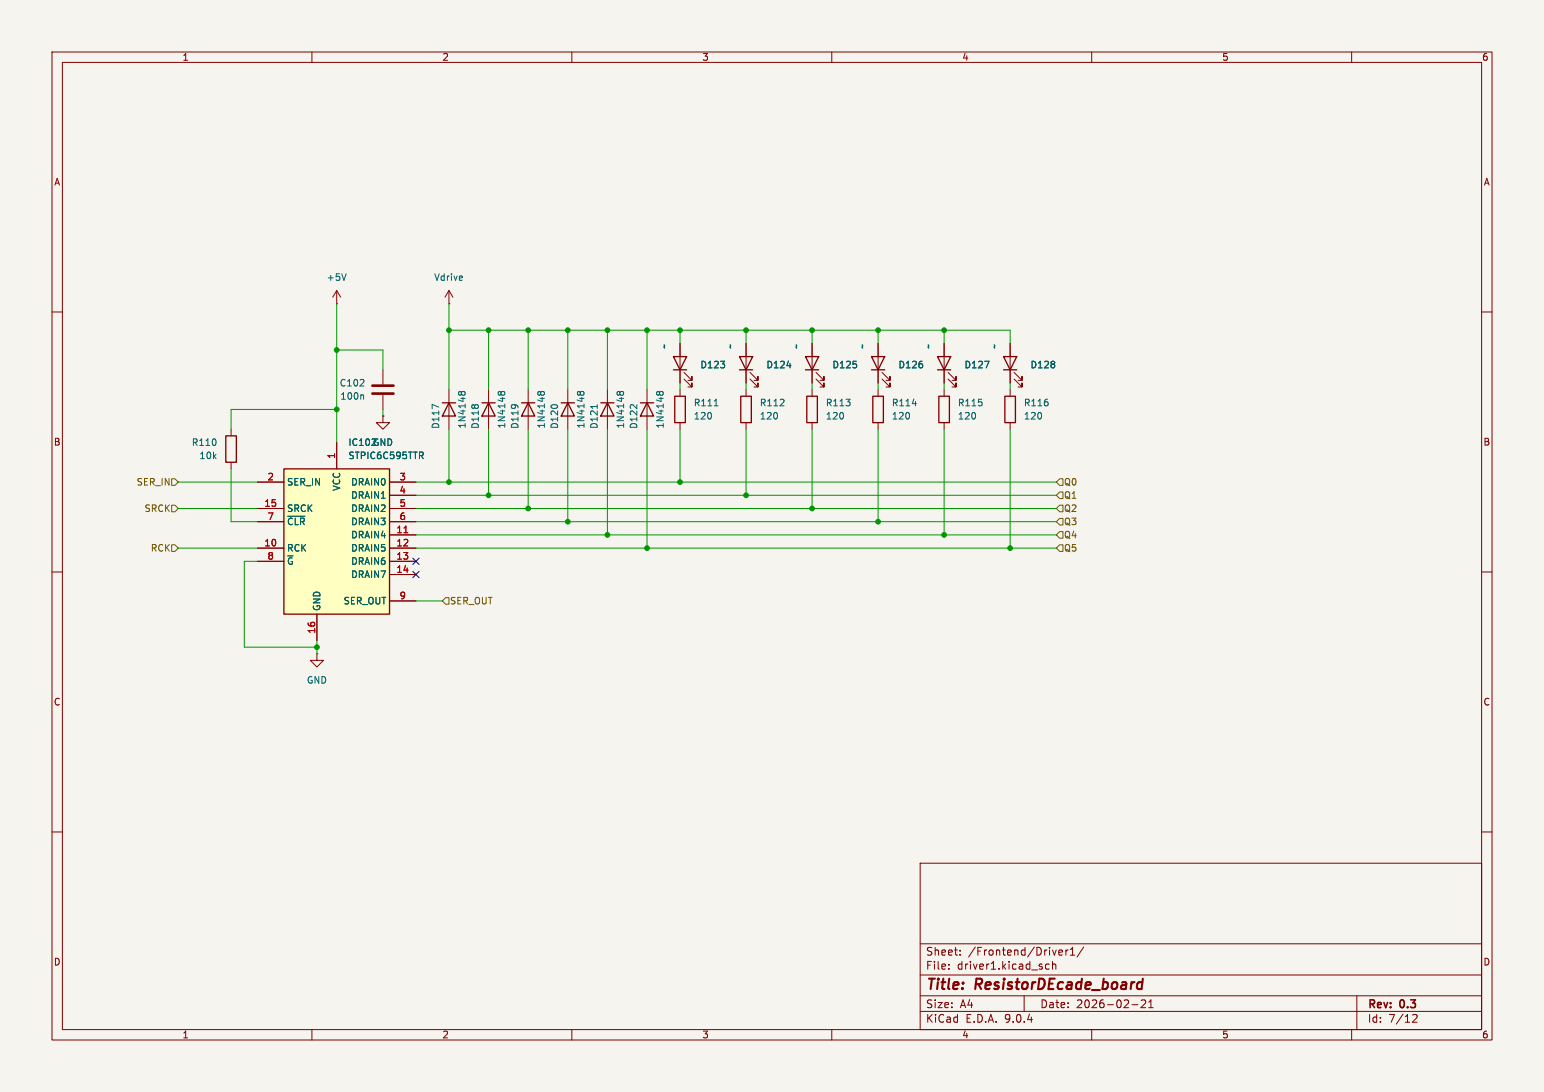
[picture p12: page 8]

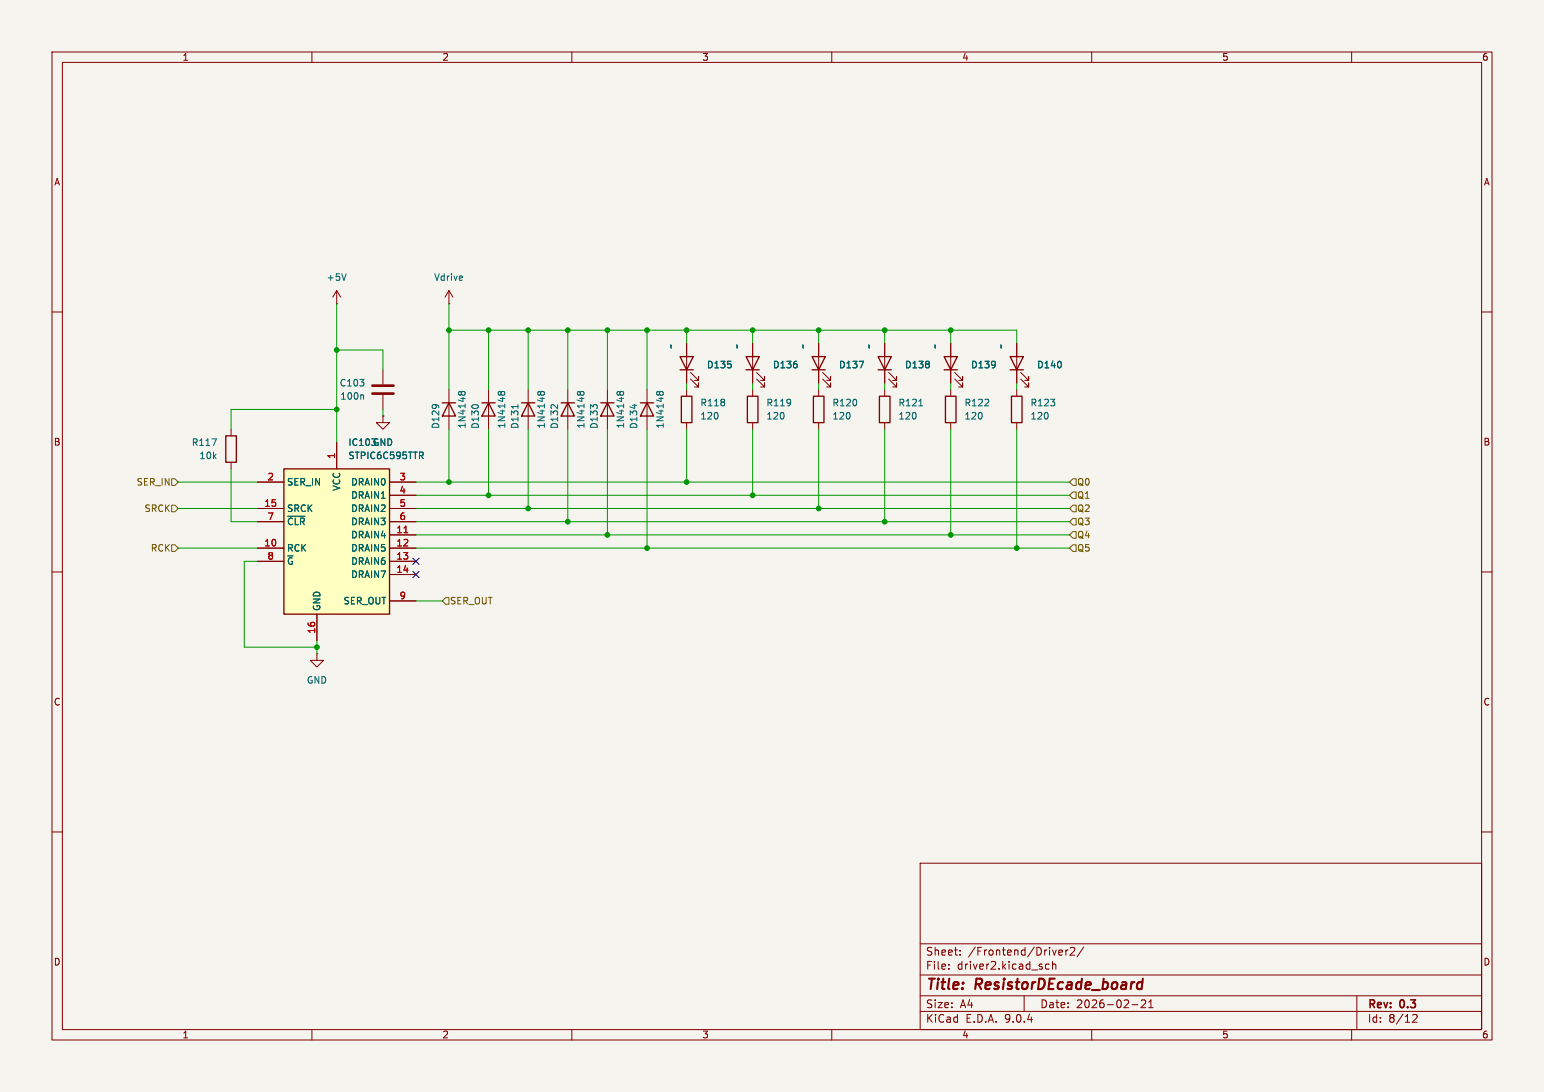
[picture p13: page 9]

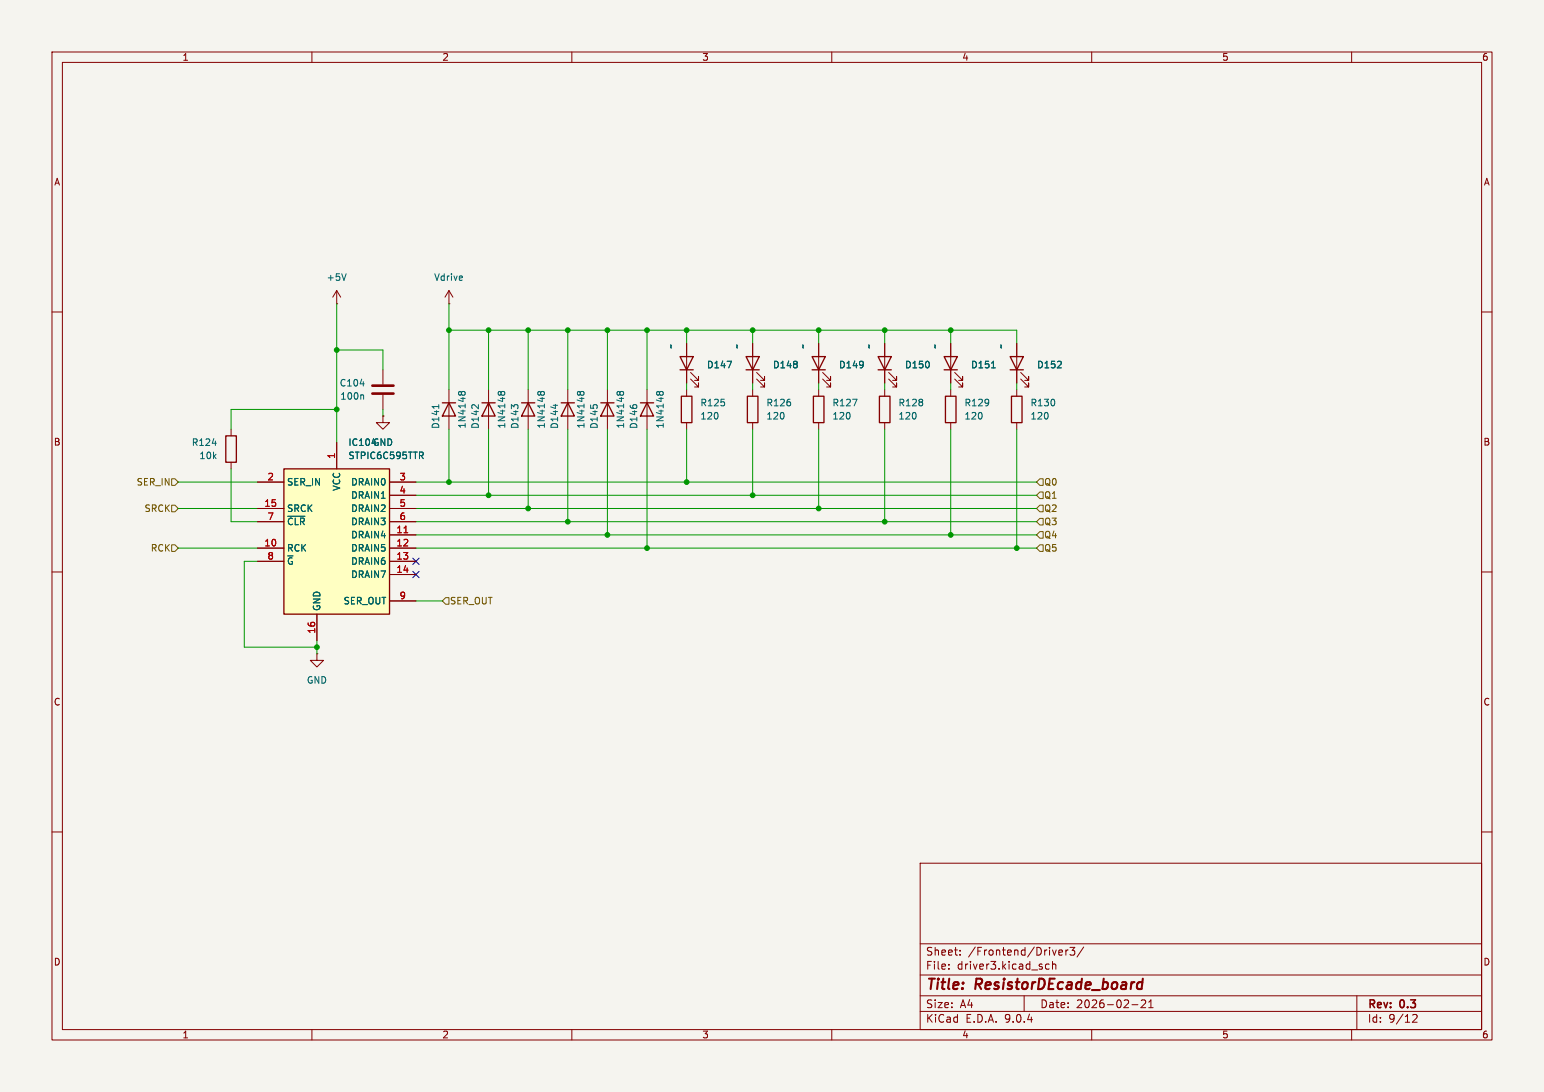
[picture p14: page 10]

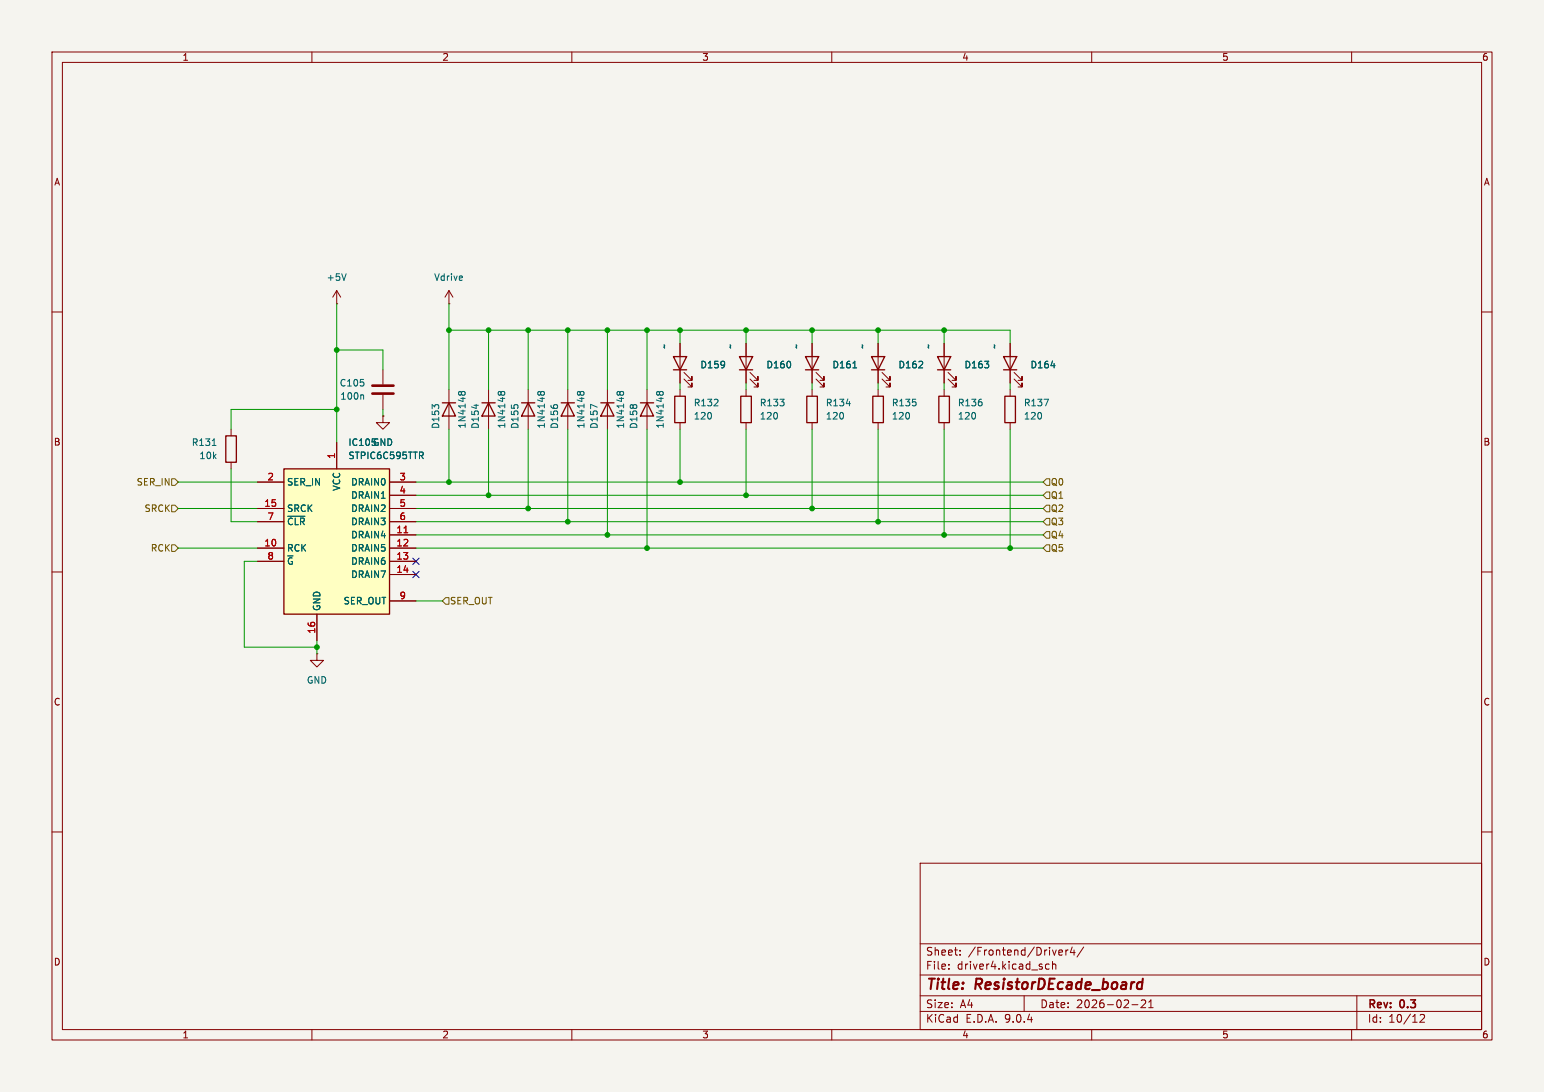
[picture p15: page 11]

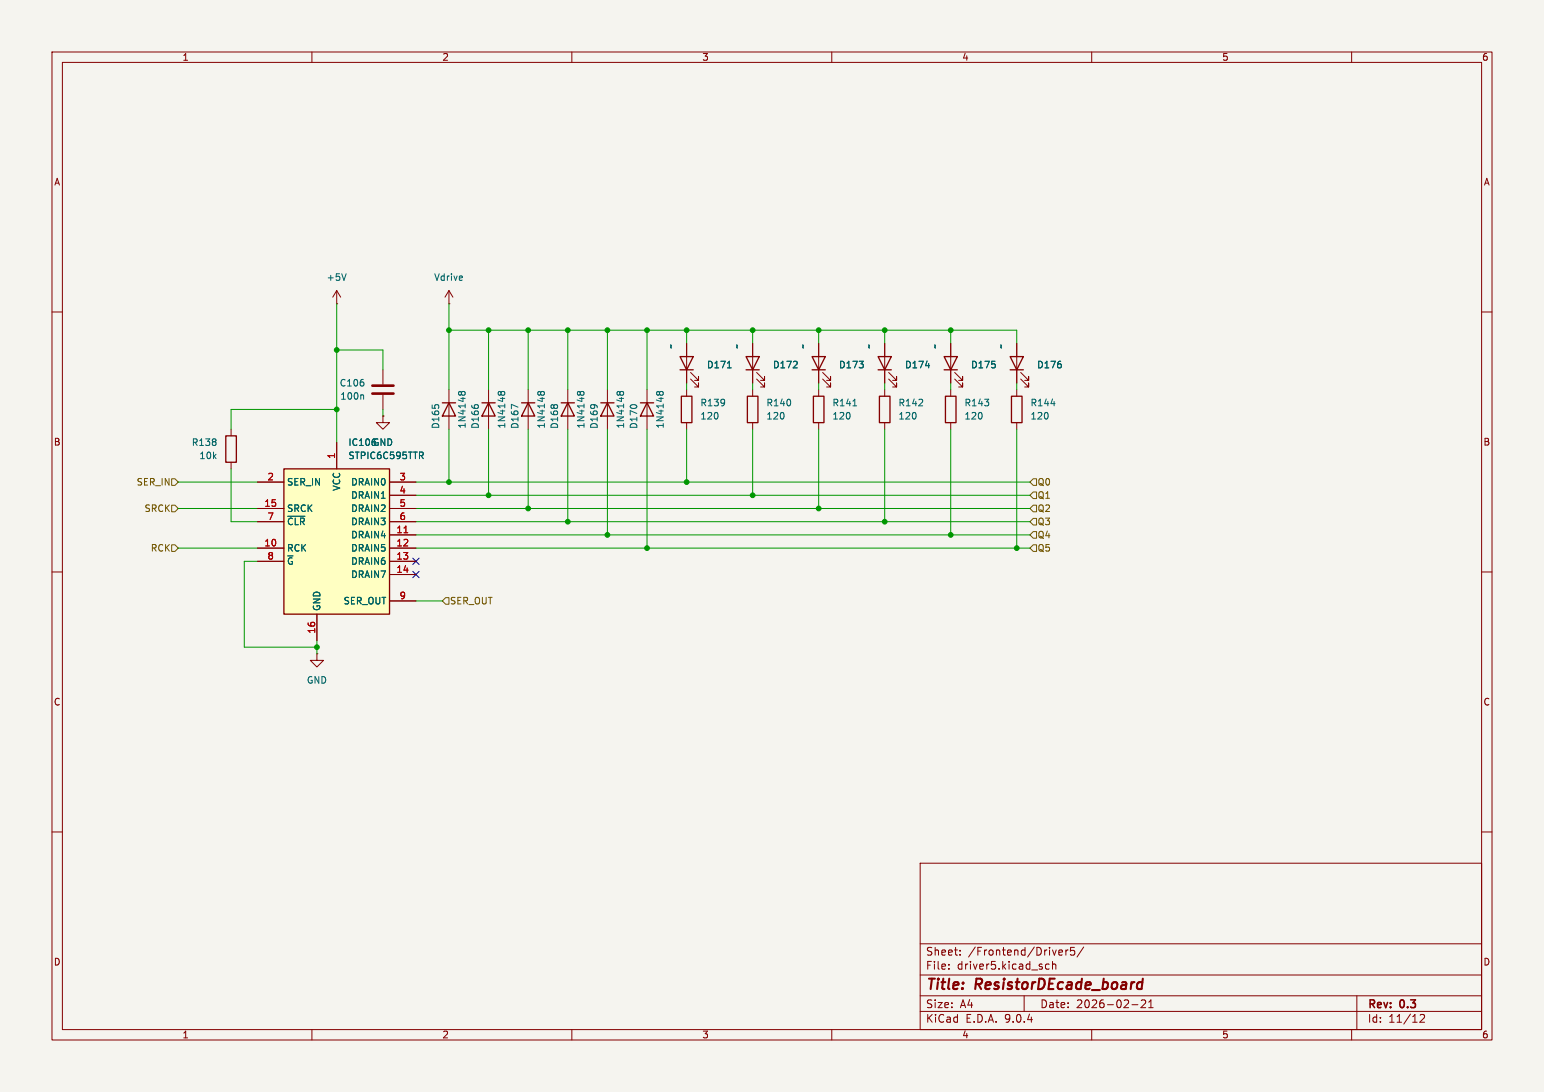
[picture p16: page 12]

File: driver5.kicad_sch Sheet: /Frontend/Driver5/ GND





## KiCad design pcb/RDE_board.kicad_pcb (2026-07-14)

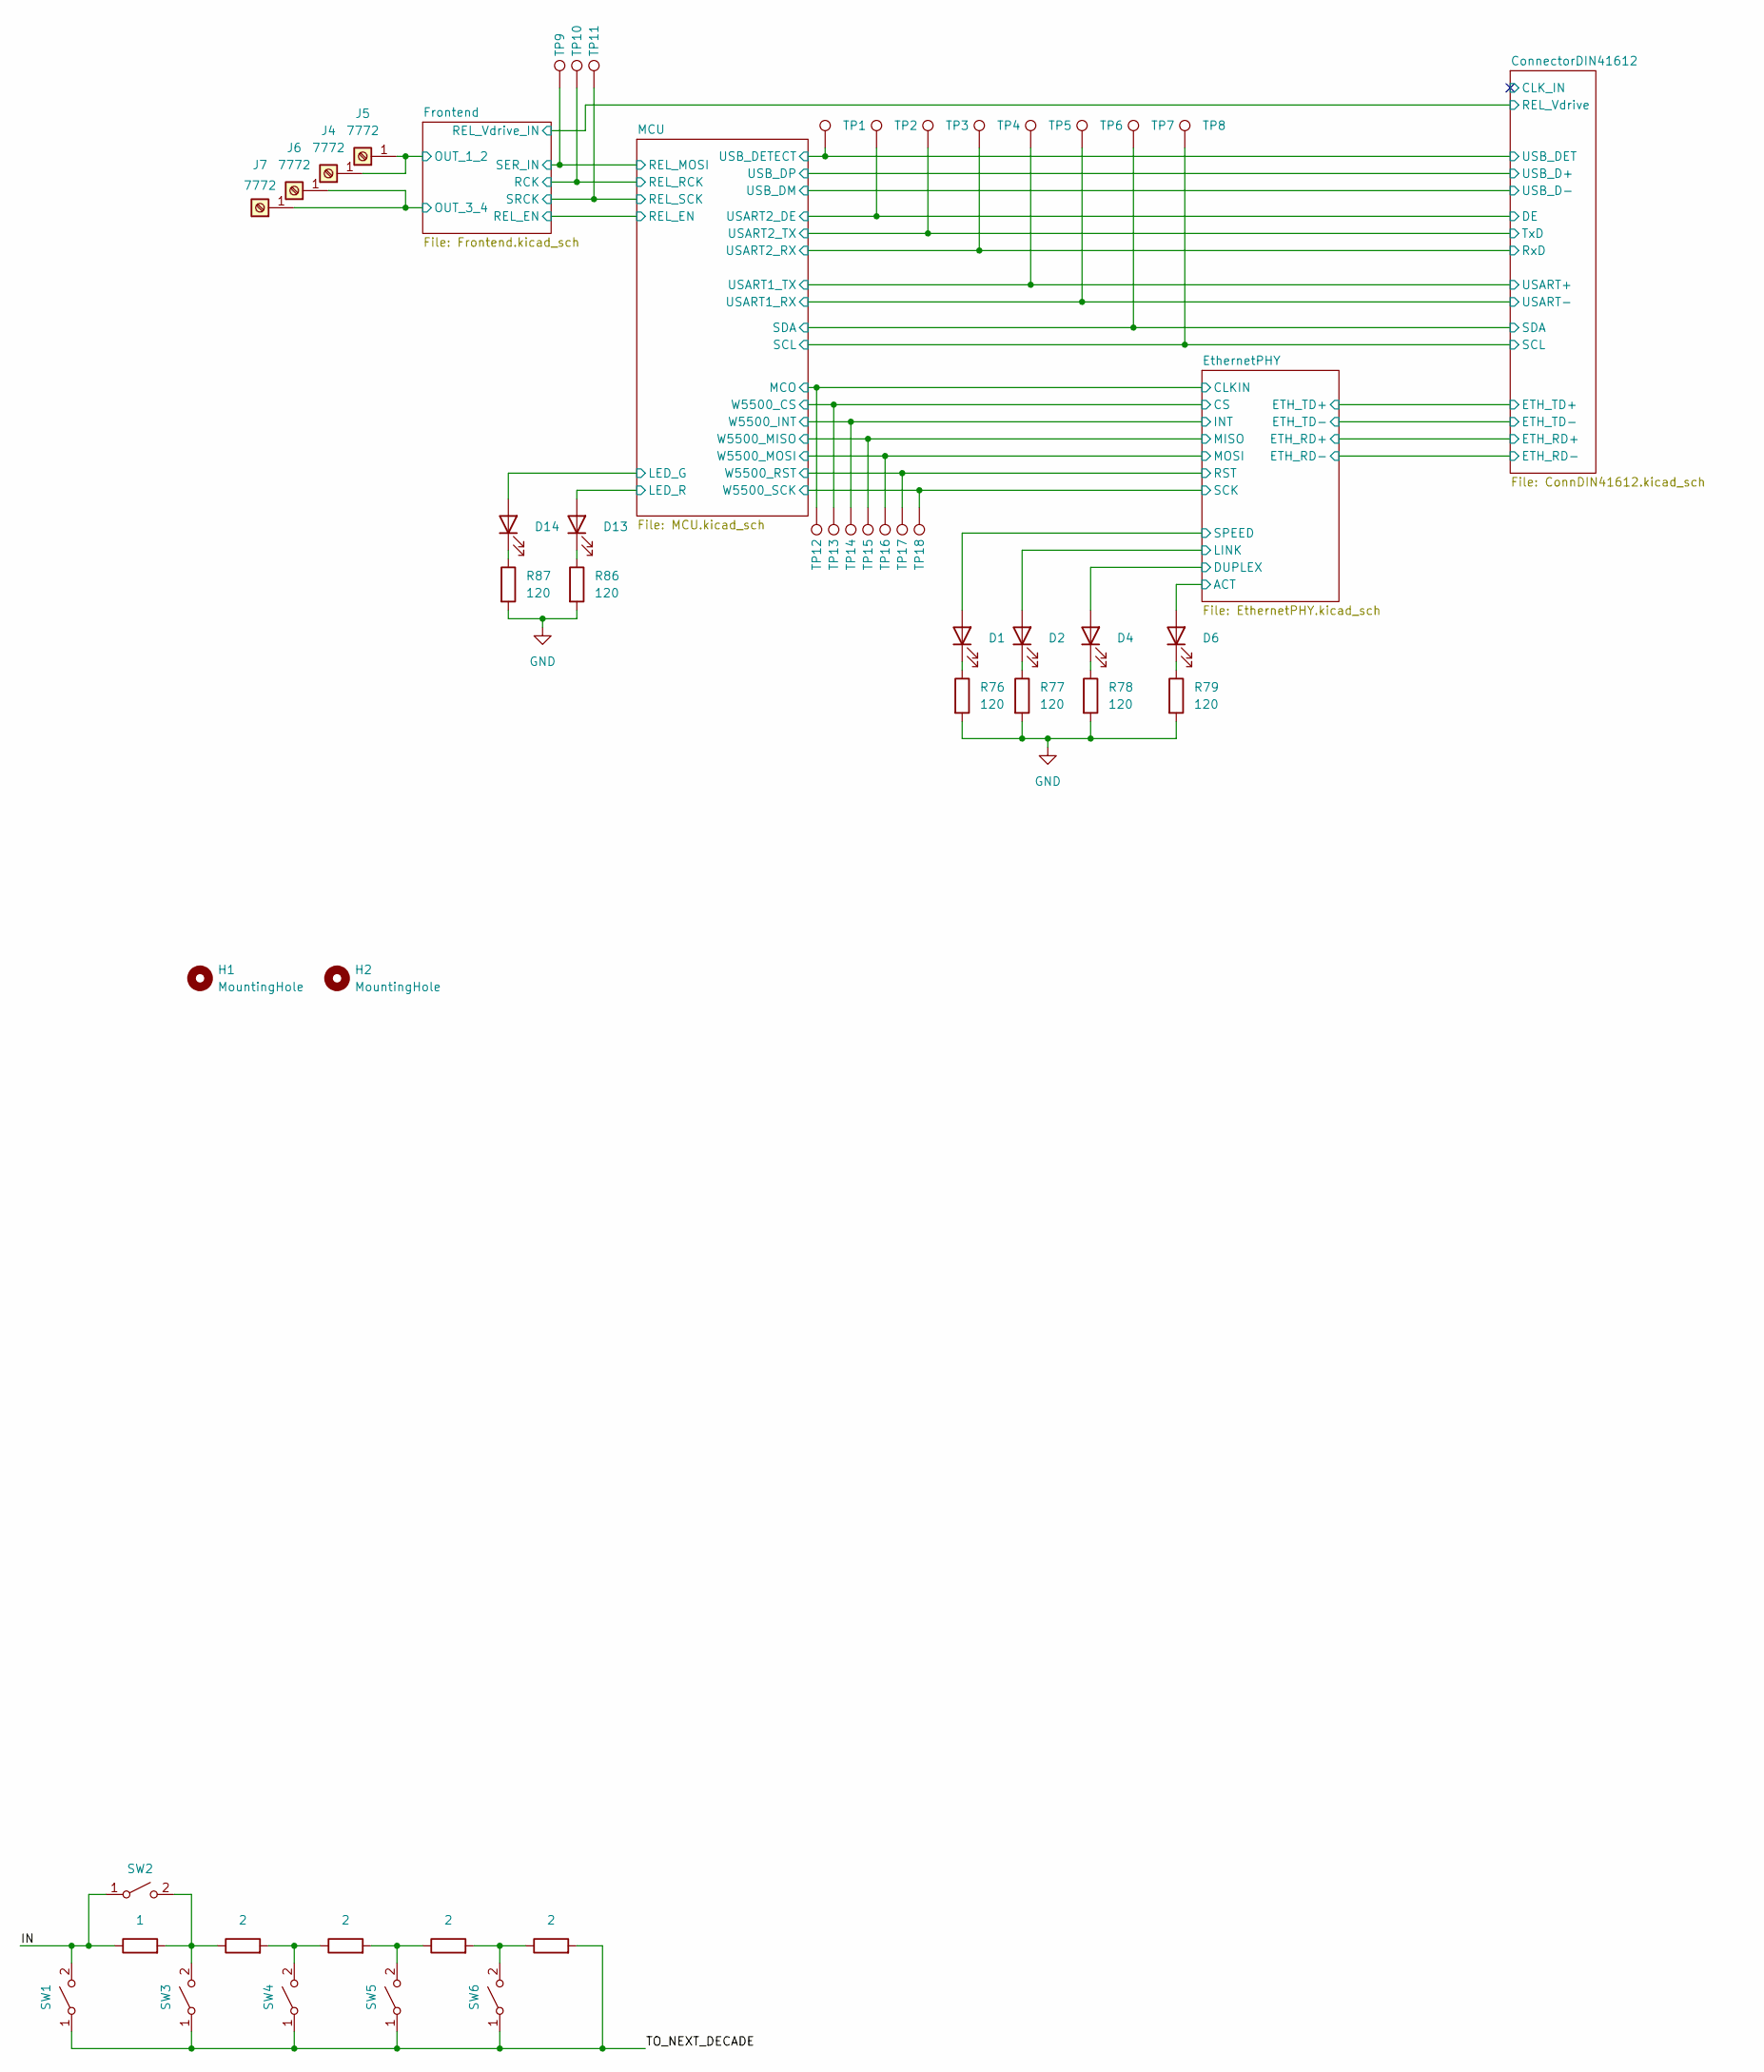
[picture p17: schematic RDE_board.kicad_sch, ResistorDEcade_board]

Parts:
D1, D2, D4, D6, D13, D14: LED_0603_1608Metric_Pad1.05x0.95mm_HandSolder
H1, H2: MountingHole; MountingHole_2.7mm_M2.5
J4, J5, J6, J7: 7772; Manufacturer_Part_Number 7772
R76, R77, R78, R79, R86, R87: 120; R_0603_1608Metric_Pad0.98x0.95mm_HandSolder
R92: 1; R_0603_1608Metric_Pad0.98x0.95mm_HandSolder
R93, R94, R95, R96: 2; R_0603_1608Metric_Pad0.98x0.95mm_HandSolder
SW1, SW2, SW3, SW4, SW5, SW6: SW_SPST
TP1, TP2, TP3, TP4, TP5, TP6, TP7, TP8, TP9, TP10, TP11, TP12, TP13, TP14, TP15, TP16, TP17, TP18: TestPoint; TestPoint_Pad_D1.0mm

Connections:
/ConnectorDIN41612/DE: TP2.1; also elsewhere on the board
/ConnectorDIN41612/RxD: TP4.1; also elsewhere on the board
/ConnectorDIN41612/TxD: TP3.1; also elsewhere on the board
/ConnectorDIN41612/USART+: TP5.1; also elsewhere on the board
/ConnectorDIN41612/USART-: TP6.1; also elsewhere on the board
/ConnectorDIN41612/USB_DET: TP1.1; also elsewhere on the board
/EthernetPHY/ACT: D6.2 (A); also elsewhere on the board
/EthernetPHY/CLKIN: TP12.1; also elsewhere on the board
/EthernetPHY/CS: TP13.1; also elsewhere on the board
/EthernetPHY/DUPLEX: D4.2 (A); also elsewhere on the board
/EthernetPHY/INT: TP14.1; also elsewhere on the board
/EthernetPHY/LINK: D2.2 (A); also elsewhere on the board
/EthernetPHY/MISO: TP15.1; also elsewhere on the board
/EthernetPHY/MOSI: TP16.1; also elsewhere on the board
/EthernetPHY/RST: TP17.1; also elsewhere on the board
/EthernetPHY/SCK: TP18.1; also elsewhere on the board
/EthernetPHY/SPEED: D1.2 (A); also elsewhere on the board
/Frontend/OUT_1_2: J4.1, J5.1; also elsewhere on the board
/Frontend/OUT_3_4: J6.1, J7.1; also elsewhere on the board
/Frontend/RCK: TP10.1; also elsewhere on the board
/Frontend/SER_IN: TP9.1; also elsewhere on the board
/Frontend/SRCK: TP11.1; also elsewhere on the board
/IN: R92.1, SW1.2 (B), SW2.1 (A)
/MCU/LED_G: D14.2 (A); also elsewhere on the board
/MCU/LED_R: D13.2 (A); also elsewhere on the board
/MCU/SCL: TP8.1; also elsewhere on the board
/MCU/SDA: TP7.1; also elsewhere on the board
/TO_NEXT_DECADE: R96.2, SW1.1 (A), SW3.1 (A), SW4.1 (A), SW5.1 (A), SW6.1 (A)
GND: R76.2, R77.2, R78.2, R79.2, R86.2, R87.2; also elsewhere on the board
unnamed: D1.1 (K), R76.1
unnamed: D2.1 (K), R77.1
unnamed: D4.1 (K), R78.1
unnamed: D6.1 (K), R79.1
unnamed: D13.1 (K), R86.1
unnamed: D14.1 (K), R87.1
unnamed: R92.2, R93.1, SW2.2 (B), SW3.2 (B)
unnamed: R93.2, R94.1, SW4.2 (B)
unnamed: R94.2, R95.1, SW5.2 (B)
unnamed: R95.2, R96.1, SW6.2 (B)

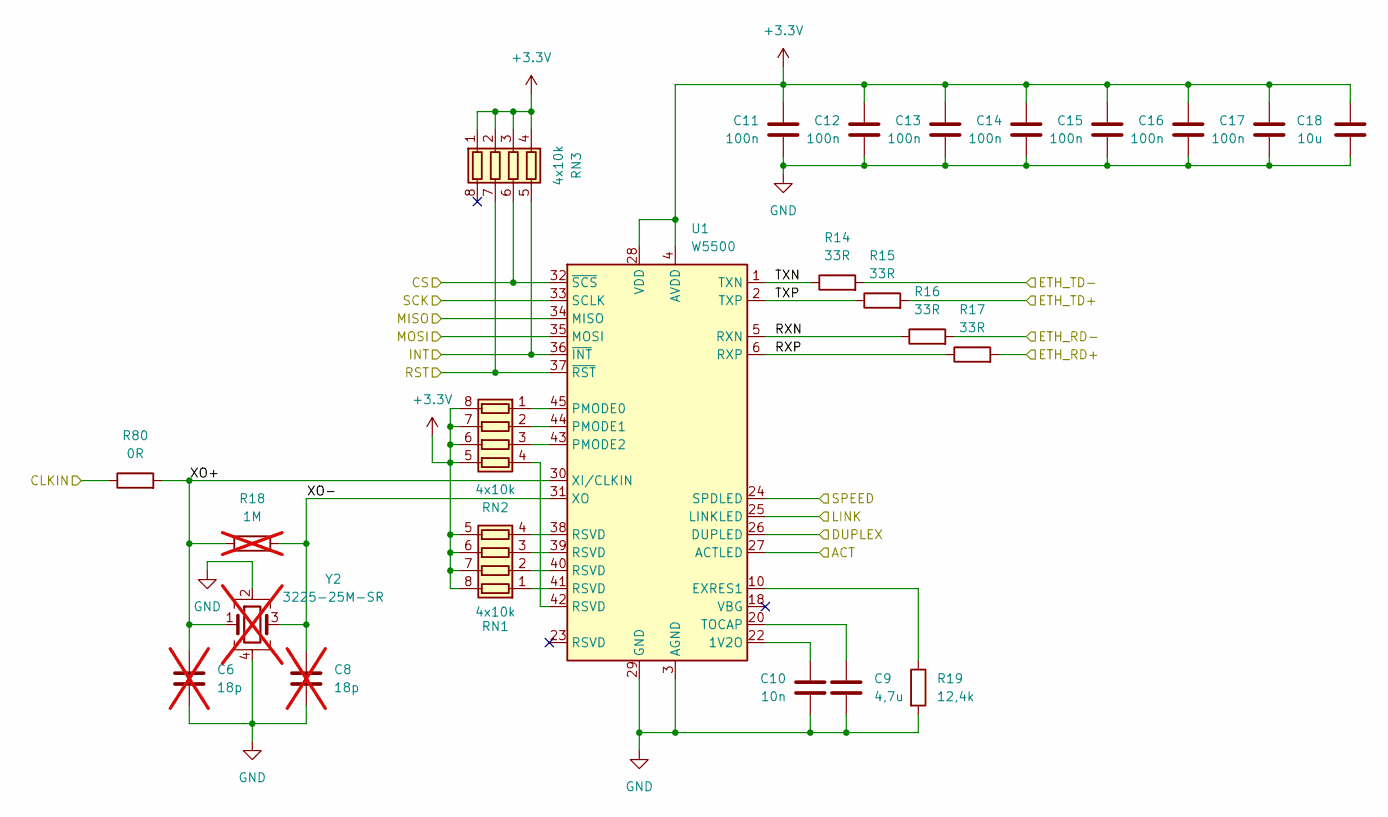
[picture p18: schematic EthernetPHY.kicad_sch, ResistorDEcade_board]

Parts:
C6, C8: 18p; C_0402_1005Metric_Pad0.74x0.62mm_HandSolder; not fitted
C9: 4,7u; C_0603_1608Metric_Pad1.08x0.95mm_HandSolder
C10: 10n; C_0603_1608Metric_Pad1.08x0.95mm_HandSolder
C11, C12, C13, C14, C15, C16, C17: 100n; C_0603_1608Metric_Pad1.08x0.95mm_HandSolder
C18: 10u; C_1206_3216Metric_Pad1.33x1.80mm_HandSolder
R14, R15, R16, R17: 33R; R_0603_1608Metric_Pad0.98x0.95mm_HandSolder
R18: 1M; R_0402_1005Metric_Pad0.72x0.64mm_HandSolder; not fitted
R19: 12,4k; R_0603_1608Metric_Pad0.98x0.95mm_HandSolder
R80: 0R; R_0402_1005Metric_Pad0.72x0.64mm_HandSolder
RN1, RN2, RN3: 4x10k; R_Array_Convex_4x0603
U1: W5500; LQFP-48_7x7mm_P0.5mm
Y2: 3225-25M-SR; Crystal_SMD_3225-4Pin_3.2x2.5mm; not fitted

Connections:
+3.3V: C11.2, C12.2, C13.2, C14.2, C15.2, C16.2, C17.2, C18.1, RN1.5 (R4.2), RN1.6 (R3.2), RN1.7 (R2.2), RN1.8 (R1.2), RN2.5 (R4.2), RN2.6 (R3.2), RN2.7 (R2.2), RN2.8 (R1.2), RN3.1 (R1.1), RN3.2 (R2.1), RN3.3 (R3.1), RN3.4 (R4.1), U1.4 (AVDD), U1.8 (AVDD), U1.11 (AVDD), U1.15 (AVDD), U1.17 (AVDD), U1.21 (AVDD), U1.28 (VDD); also elsewhere on the board
/ConnectorDIN41612/ETH_RD+: R17.2; also elsewhere on the board
/ConnectorDIN41612/ETH_RD-: R16.2; also elsewhere on the board
/ConnectorDIN41612/ETH_TD+: R15.2; also elsewhere on the board
/ConnectorDIN41612/ETH_TD-: R14.2; also elsewhere on the board
/EthernetPHY/ACT: U1.27 (ACTLED); also elsewhere on the board
/EthernetPHY/CLKIN: R80.1; also elsewhere on the board
/EthernetPHY/CS: RN3.6 (R3.2), U1.32 (~SCS); also elsewhere on the board
/EthernetPHY/DUPLEX: U1.26 (DUPLED); also elsewhere on the board
/EthernetPHY/INT: RN3.5 (R4.2), U1.36 (~INT); also elsewhere on the board
/EthernetPHY/LINK: U1.25 (LINKLED); also elsewhere on the board
/EthernetPHY/MISO: U1.34 (MISO); also elsewhere on the board
/EthernetPHY/MOSI: U1.35 (MOSI); also elsewhere on the board
/EthernetPHY/RST: RN3.7 (R2.2), U1.37 (~RST); also elsewhere on the board
/EthernetPHY/RXN: R16.1, U1.5 (RXN)
/EthernetPHY/RXP: R17.1, U1.6 (RXP)
/EthernetPHY/SCK: U1.33 (SCLK); also elsewhere on the board
/EthernetPHY/SPEED: U1.24 (SPDLED); also elsewhere on the board
/EthernetPHY/TXN: R14.1, U1.1 (TXN)
/EthernetPHY/TXP: R15.1, U1.2 (TXP)
/EthernetPHY/XO+: C6.1, R18.1, R80.2, U1.30 (XI/CLKIN), Y2.1
/EthernetPHY/XO-: C8.1, R18.2, U1.31 (XO), Y2.3
GND: C6.2, C8.2, C9.2, C10.1, C11.1, C12.1, C13.1, C14.1, C15.1, C16.1, C17.1, C18.2, R19.2, U1.3 (AGND), U1.9 (AGND), U1.14 (AGND), U1.16 (AGND), U1.19 (AGND), U1.29 (GND), U1.48 (AGND), Y2.2, Y2.4; also elsewhere on the board
unnamed: RN1.1 (R1.1), U1.41 (RSVD)
unnamed: RN1.2 (R2.1), U1.40 (RSVD)
unnamed: RN1.3 (R3.1), U1.39 (RSVD)
unnamed: RN1.4 (R4.1), U1.38 (RSVD)
unnamed: RN2.1 (R1.1), U1.45 (PMODE0)
unnamed: RN2.2 (R2.1), U1.44 (PMODE1)
unnamed: RN2.3 (R3.1), U1.43 (PMODE2)
unnamed: RN2.4 (R4.1), U1.42 (RSVD)
unnamed: C10.2, U1.22 (1V2O)
unnamed: R19.1, U1.10 (EXRES1)
unnamed: C9.1, U1.20 (TOCAP)

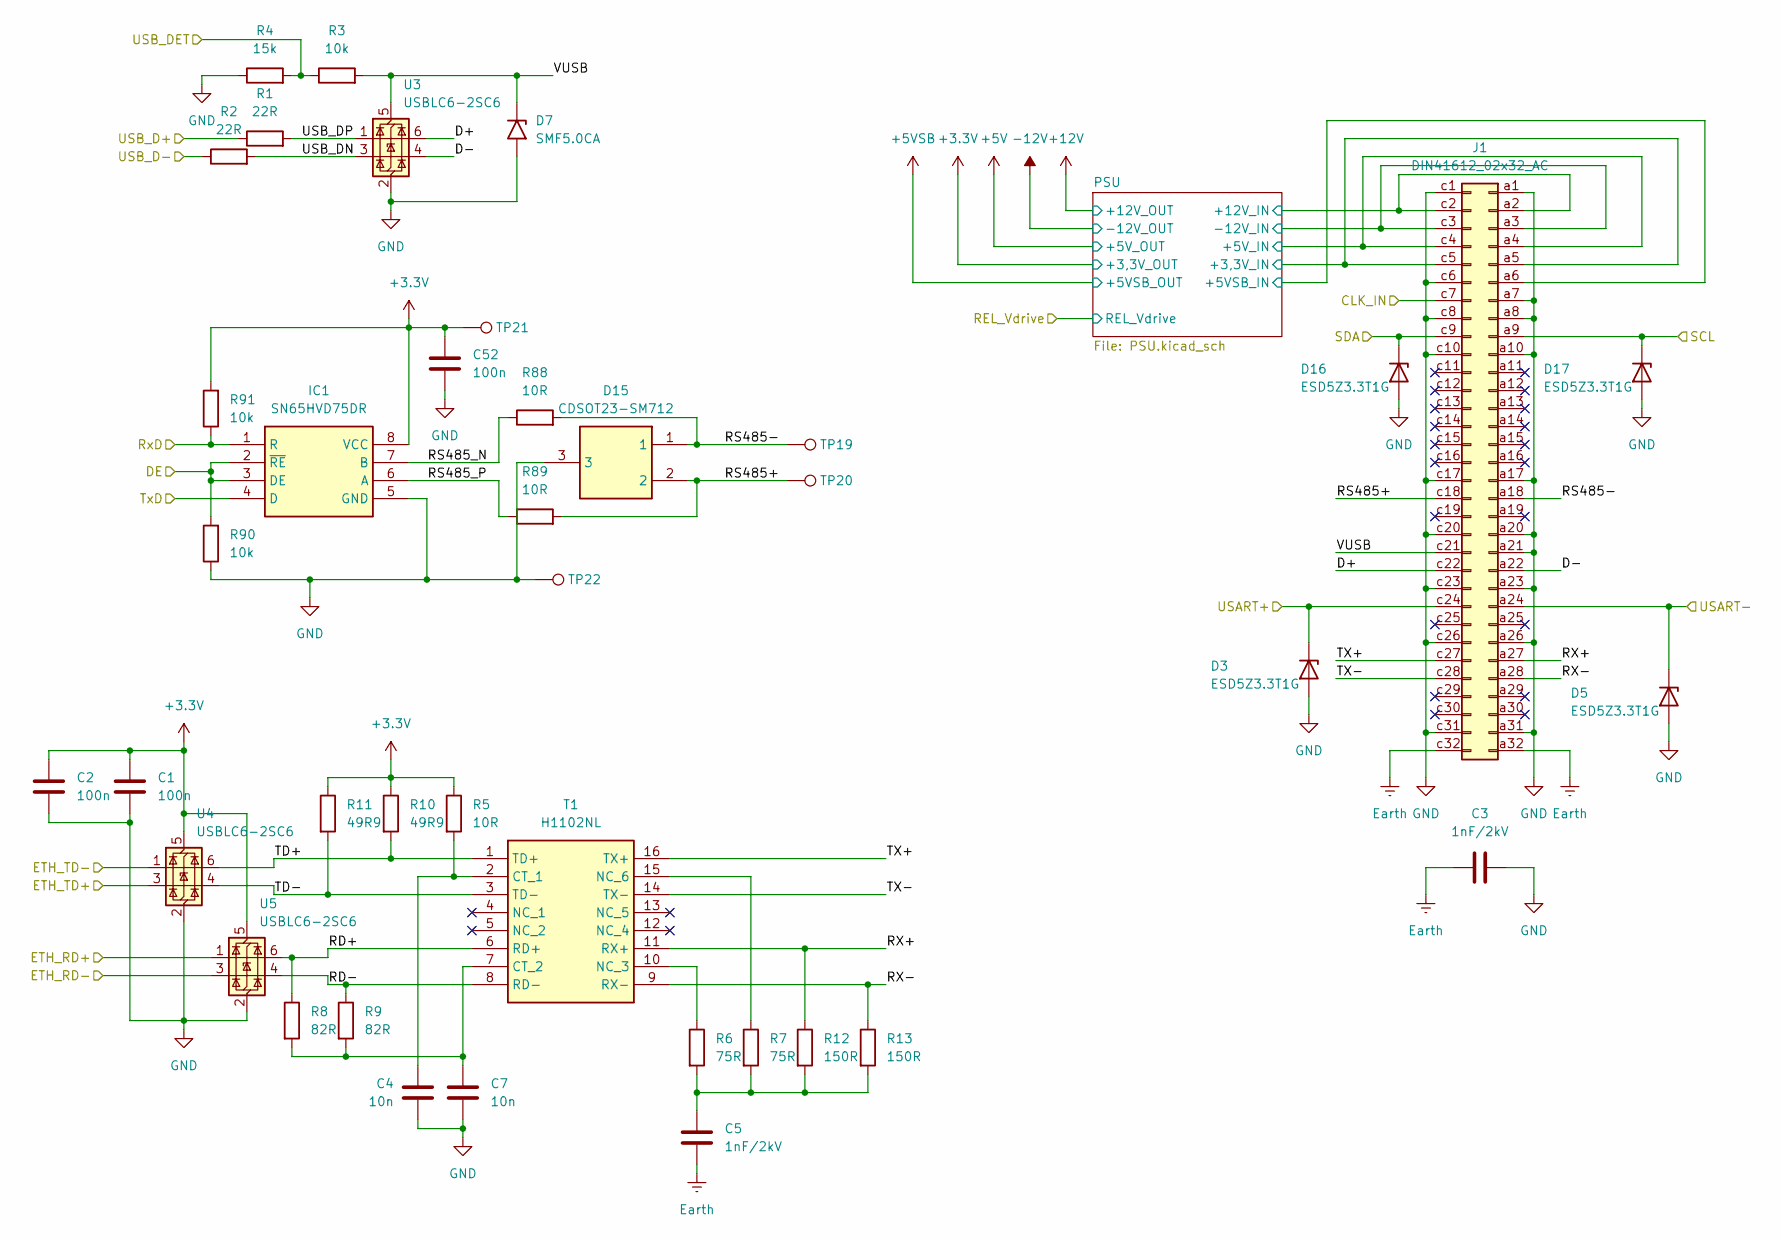
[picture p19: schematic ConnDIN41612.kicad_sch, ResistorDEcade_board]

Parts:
C1, C2, C52: 100n; C_0603_1608Metric_Pad1.08x0.95mm_HandSolder
C3, C5: 1nF/2kV; C_1206_3216Metric_Pad1.33x1.80mm_HandSolder
C4, C7: 10n; C_0603_1608Metric_Pad1.08x0.95mm_HandSolder
D3, D5, D16, D17: ESD5Z3.3T1G; D_SOD-523
D7: SMF5.0CA; D_SMF
D15: CDSOT23-SM712; SOT95P230X117-3N; Manufacturer_Part_Number CDSOT23-SM712
IC1: SN65HVD75DR; SOIC127P600X175-8N; Manufacturer_Part_Number SN65HVD75DR
J1: DIN41612_02x32_AC; DIN41612_C_2x32_Male_Horizontal_THT
R1, R2: 22R; R_0402_1005Metric_Pad0.72x0.64mm_HandSolder
R3, R90, R91: 10k; R_0603_1608Metric_Pad0.98x0.95mm_HandSolder
R4: 15k; R_0603_1608Metric_Pad0.98x0.95mm_HandSolder
R5, R88, R89: 10R; R_0603_1608Metric_Pad0.98x0.95mm_HandSolder
R6, R7: 75R; R_0603_1608Metric_Pad0.98x0.95mm_HandSolder
R8, R9: 82R; R_0603_1608Metric_Pad0.98x0.95mm_HandSolder
R10, R11: 49R9; R_0603_1608Metric_Pad0.98x0.95mm_HandSolder
R12, R13: 150R; R_0603_1608Metric_Pad0.98x0.95mm_HandSolder
T1: H1102NL; SOIC127P940X597-16N; Manufacturer_Part_Number H1102NL
TP19, TP20, TP21, TP22: TestPoint; TestPoint_Pad_D1.0mm
U3, U4, U5: USBLC6-2SC6; SOT-23-6_Handsoldering

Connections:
+3.3V: C1.1, C2.1, C52.1, IC1.8 (VCC), R5.1, R10.1, R11.1, R91.2, TP21.1, U4.5 (VBUS), U5.5 (VBUS); also elsewhere on the board
/ConnectorDIN41612/CLK_IN: J1.c7
/ConnectorDIN41612/D+: J1.c22, U3.6 (I/O1)
/ConnectorDIN41612/D-: J1.a22, U3.4 (I/O2)
/ConnectorDIN41612/DE: IC1.2 (~RE), IC1.3 (DE), R90.2; also elsewhere on the board
/ConnectorDIN41612/ETH_RD+: U5.1 (I/O1); also elsewhere on the board
/ConnectorDIN41612/ETH_RD-: U5.3 (I/O2); also elsewhere on the board
/ConnectorDIN41612/ETH_TD+: U4.3 (I/O2); also elsewhere on the board
/ConnectorDIN41612/ETH_TD-: U4.1 (I/O1); also elsewhere on the board
/ConnectorDIN41612/PSU/+3,3V_IN: J1.a5, J1.c5; also elsewhere on the board
/ConnectorDIN41612/PSU/+5VSB_IN: J1.a6
/ConnectorDIN41612/PSU/+5V_IN: J1.a4, J1.c4; also elsewhere on the board
/ConnectorDIN41612/PSU/+12V_IN: J1.a2, J1.c2
/ConnectorDIN41612/PSU/-12V_IN: J1.a3, J1.c3
/ConnectorDIN41612/RD+: R8.1, T1.6 (RD+), U5.6 (I/O1)
/ConnectorDIN41612/RD-: R9.1, T1.8 (RD-), U5.4 (I/O2)
/ConnectorDIN41612/RS485+: D15.2, J1.c18, R89.2, TP20.1
/ConnectorDIN41612/RS485-: D15.1, J1.a18, R88.2, TP19.1
/ConnectorDIN41612/RS485_N: IC1.7 (B), R88.1
/ConnectorDIN41612/RS485_P: IC1.6 (A), R89.1
/ConnectorDIN41612/RX+: J1.a27, R12.1, T1.11 (RX+)
/ConnectorDIN41612/RX-: J1.a28, R13.1, T1.9 (RX-)
/ConnectorDIN41612/RxD: IC1.1 (R), R91.1; also elsewhere on the board
/ConnectorDIN41612/TD+: R10.2, T1.1 (TD+), U4.6 (I/O1)
/ConnectorDIN41612/TD-: R11.2, T1.3 (TD-), U4.4 (I/O2)
/ConnectorDIN41612/TX+: J1.c27, T1.16 (TX+)
/ConnectorDIN41612/TX-: J1.c28, T1.14 (TX-)
/ConnectorDIN41612/TxD: IC1.4 (D); also elsewhere on the board
/ConnectorDIN41612/USART+: D3.1 (K), J1.c24; also elsewhere on the board
/ConnectorDIN41612/USART-: D5.1 (K), J1.a24; also elsewhere on the board
/ConnectorDIN41612/USB_D+: R1.1; also elsewhere on the board
/ConnectorDIN41612/USB_D-: R2.1; also elsewhere on the board
/ConnectorDIN41612/USB_DET: R3.1, R4.2; also elsewhere on the board
/ConnectorDIN41612/USB_DN: R2.2, U3.3 (I/O2)
/ConnectorDIN41612/USB_DP: R1.2, U3.1 (I/O1)
/ConnectorDIN41612/VUSB: D7.1 (A1), J1.c21, R3.2, U3.5 (VBUS)
/MCU/SCL: D17.1 (K), J1.a9; also elsewhere on the board
/MCU/SDA: D16.1 (K), J1.c9; also elsewhere on the board
Earth: C3.1, C5.2, J1.a32, J1.c32
GND: C1.2, C2.2, C3.2, C4.1, C7.2, C52.2, D3.2 (A), D5.2 (A), D7.2 (A2), D15.3, D16.2 (A), D17.2 (A), IC1.5 (GND), J1.a1, J1.a7, J1.a8, J1.a10, J1.a17, J1.a20, J1.a21, J1.a23, J1.a26, J1.a31, J1.c1, J1.c6, J1.c8, J1.c10, J1.c17, J1.c20, J1.c23, J1.c26, J1.c31, R4.1, R90.1, TP22.1, U3.2 (GND), U4.2 (GND), U5.2 (GND); also elsewhere on the board
unnamed: C5.1, R6.2, R7.2, R12.2, R13.2
unnamed: C4.2, R5.2, T1.2 (CT_1)
unnamed: C7.1, R8.2, R9.2, T1.7 (CT_2)
unnamed: R6.1, T1.10 (NC_3)
unnamed: R7.1, T1.15 (NC_6)

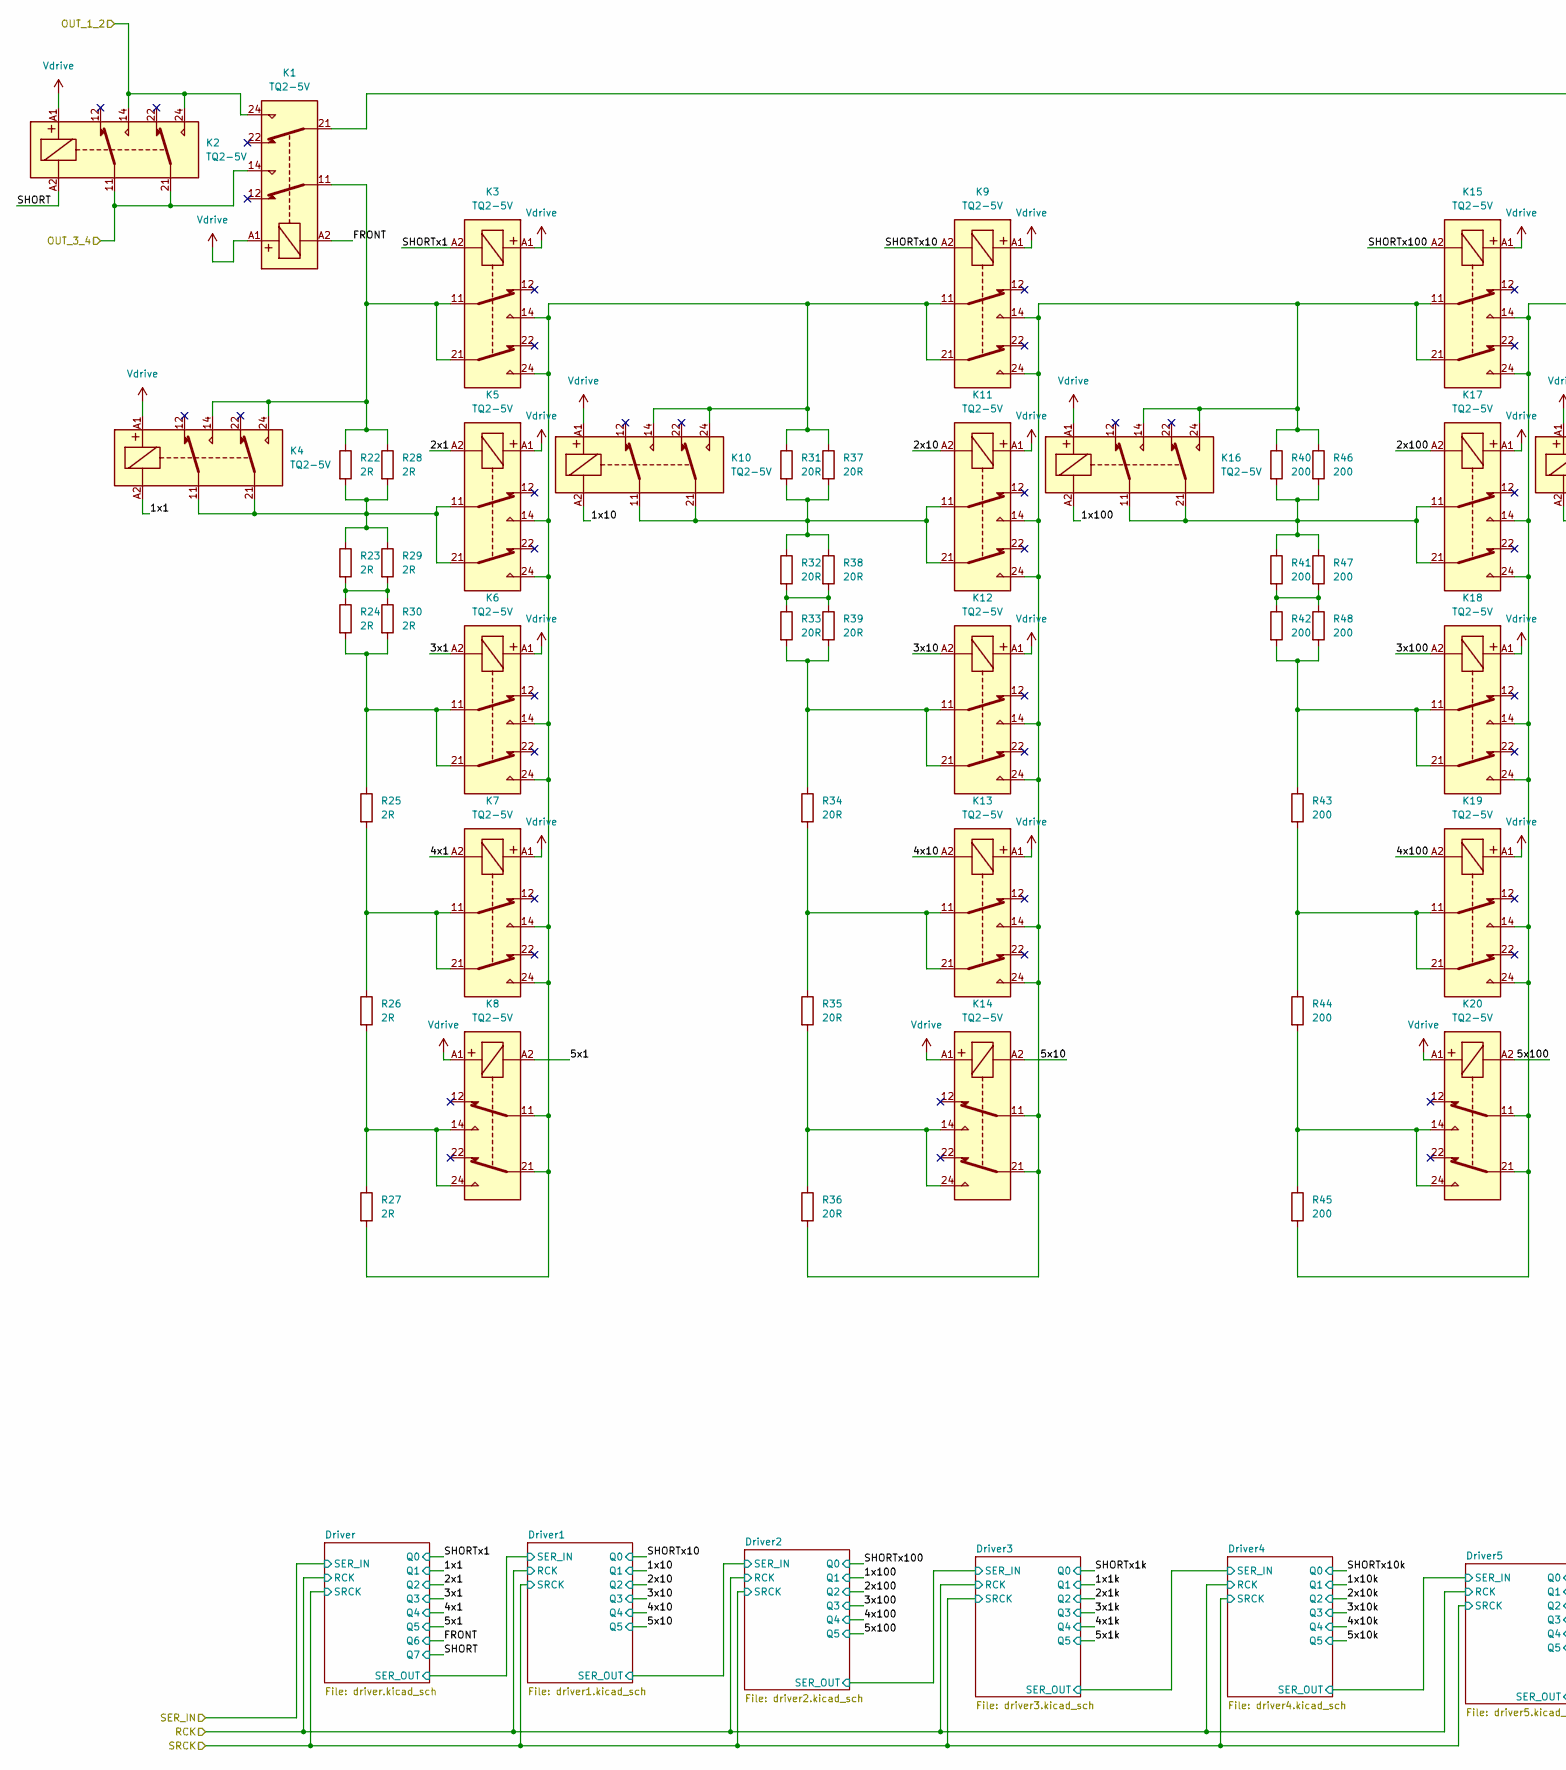
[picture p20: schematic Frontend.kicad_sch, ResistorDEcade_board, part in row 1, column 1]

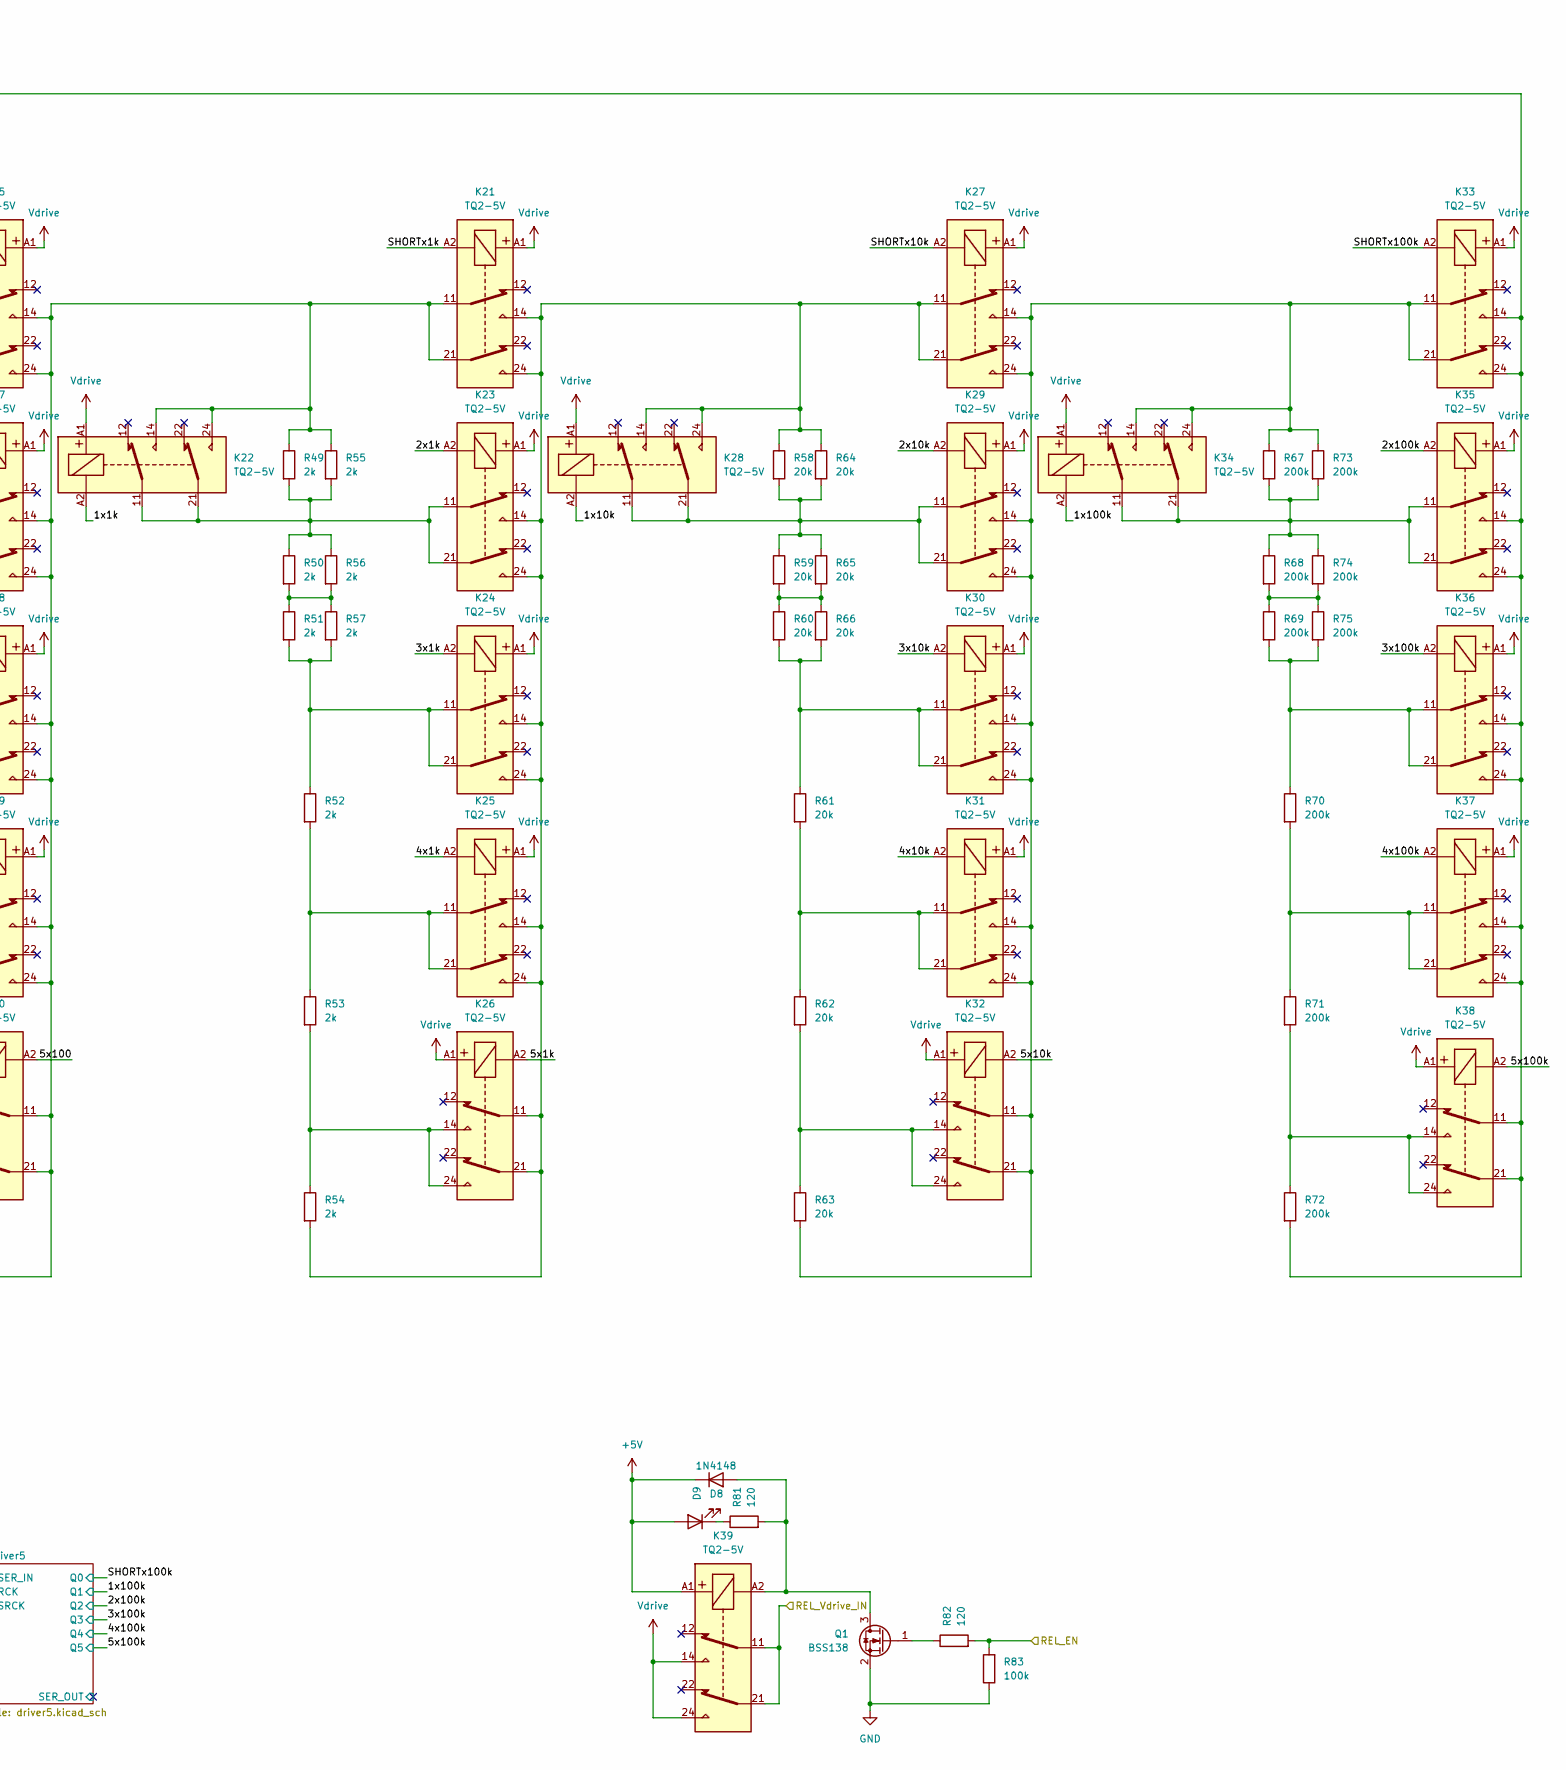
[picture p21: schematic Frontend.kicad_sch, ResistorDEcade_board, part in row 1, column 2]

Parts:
D8: 1N4148; D_MiniMELF
D9: LED_0603_1608Metric_Pad1.05x0.95mm_HandSolder
K1, K2, K3, K4, K5, K6, K7, K8, K9, K10, K11, K12, K13, K14, K15, K16, K17, K18, K19, K20, K21, K22, K23, K24, K25, K26, K27, K28, K29, K30, K31, K32, K33, K34, K35, K36, K37, K38, K39: TQ2-5V; TX2L25V; Manufacturer_Part_Number TQ2-5V
Q1: BSS138; SOT-23
R22, R23, R24, R25, R26, R27, R28, R29, R30: 2R; R_0603_1608Metric_Pad0.98x0.95mm_HandSolder
R31, R32, R33, R34, R35, R36, R37, R38, R39: 20R; R_0603_1608Metric_Pad0.98x0.95mm_HandSolder
R40, R41, R42, R43, R44, R45, R46, R47, R48: 200; R_0603_1608Metric_Pad0.98x0.95mm_HandSolder
R49, R50, R51, R52, R53, R54, R55, R56, R57: 2k; R_0603_1608Metric_Pad0.98x0.95mm_HandSolder
R58, R59, R60, R61, R62, R63, R64, R65, R66: 20k; R_0603_1608Metric_Pad0.98x0.95mm_HandSolder
R67, R68, R69, R70, R71, R72, R73, R74, R75: 200k; R_0603_1608Metric_Pad0.98x0.95mm_HandSolder
R81, R82: 120; R_0603_1608Metric_Pad0.98x0.95mm_HandSolder
R83: 100k; R_0603_1608Metric_Pad0.98x0.95mm_HandSolder

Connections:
+5V: D8.1 (K), D9.2 (A), K39.A1; also elsewhere on the board
/ConnectorDIN41612/REL_Vdrive: K39.11, K39.21; also elsewhere on the board
/Frontend/1x1: K4.A2; also elsewhere on the board
/Frontend/1x1k: K22.A2; also elsewhere on the board
/Frontend/1x10: K10.A2; also elsewhere on the board
/Frontend/1x10k: K28.A2; also elsewhere on the board
/Frontend/1x100: K16.A2; also elsewhere on the board
/Frontend/1x100k: K34.A2; also elsewhere on the board
/Frontend/2x1: K5.A2; also elsewhere on the board
/Frontend/2x1k: K23.A2; also elsewhere on the board
/Frontend/2x10: K11.A2; also elsewhere on the board
/Frontend/2x10k: K29.A2; also elsewhere on the board
/Frontend/2x100: K17.A2; also elsewhere on the board
/Frontend/2x100k: K35.A2; also elsewhere on the board
/Frontend/3x1: K6.A2; also elsewhere on the board
/Frontend/3x1k: K24.A2; also elsewhere on the board
/Frontend/3x10: K12.A2; also elsewhere on the board
/Frontend/3x10k: K30.A2; also elsewhere on the board
/Frontend/3x100: K18.A2; also elsewhere on the board
/Frontend/3x100k: K36.A2; also elsewhere on the board
/Frontend/4x1: K7.A2; also elsewhere on the board
/Frontend/4x1k: K25.A2; also elsewhere on the board
/Frontend/4x10: K13.A2; also elsewhere on the board
/Frontend/4x10k: K31.A2; also elsewhere on the board
/Frontend/4x100: K19.A2; also elsewhere on the board
/Frontend/4x100k: K37.A2; also elsewhere on the board
/Frontend/5x1: K8.A2; also elsewhere on the board
/Frontend/5x1k: K26.A2; also elsewhere on the board
/Frontend/5x10: K14.A2; also elsewhere on the board
/Frontend/5x10k: K32.A2; also elsewhere on the board
/Frontend/5x100: K20.A2; also elsewhere on the board
/Frontend/5x100k: K38.A2; also elsewhere on the board
/Frontend/FRONT: K1.A2; also elsewhere on the board
/Frontend/OUT_1_2: K1.24, K2.14, K2.24; also elsewhere on the board
/Frontend/OUT_3_4: K1.14, K2.11, K2.21; also elsewhere on the board
/Frontend/REL_EN: R82.2, R83.2; also elsewhere on the board
/Frontend/SHORT: K2.A2; also elsewhere on the board
/Frontend/SHORTx1: K3.A2; also elsewhere on the board
/Frontend/SHORTx1k: K21.A2; also elsewhere on the board
/Frontend/SHORTx10: K9.A2; also elsewhere on the board
/Frontend/SHORTx10k: K27.A2; also elsewhere on the board
/Frontend/SHORTx100: K15.A2; also elsewhere on the board
/Frontend/SHORTx100k: K33.A2; also elsewhere on the board
GND: Q1.2 (S), R83.1; also elsewhere on the board
unnamed: D8.2 (A), K39.A2, Q1.3 (D), R81.2
unnamed: D9.1 (K), R81.1
unnamed: K1.11, K3.11, K3.21, K4.14, K4.24, R22.1, R28.1
unnamed: K1.21, K33.14, K33.24, K35.14, K35.24, K36.14, K36.24, K37.14, K37.24, K38.11, K38.21, R72.2
unnamed: K4.11, K4.21, K5.11, K5.21, R22.2, R23.1, R28.2, R29.1
unnamed: K6.11, K6.21, R24.2, R25.1, R30.2
unnamed: K7.11, K7.21, R25.2, R26.1
unnamed: K8.14, K8.24, R26.2, R27.1
unnamed: K10.11, K10.21, K11.11, K11.21, R31.2, R32.1, R37.2, R38.1
unnamed: K3.14, K3.24, K5.14, K5.24, K6.14, K6.24, K7.14, K7.24, K8.11, K8.21, K9.11, K9.21, K10.14, K10.24, R27.2, R31.1, R37.1
unnamed: K9.14, K9.24, K11.14, K11.24, K12.14, K12.24, K13.14, K13.24, K14.11, K14.21, K15.11, K15.21, K16.14, K16.24, R36.2, R40.1, R46.1
unnamed: K12.11, K12.21, R33.2, R34.1, R39.2
unnamed: K13.11, K13.21, R34.2, R35.1
unnamed: K14.14, K14.24, R35.2, R36.1
unnamed: K15.14, K15.24, K17.14, K17.24, K18.14, K18.24, K19.14, K19.24, K20.11, K20.21, K21.11, K21.21, K22.14, K22.24, R45.2, R49.1, R55.1
unnamed: K16.11, K16.21, K17.11, K17.21, R40.2, R41.1, R46.2, R47.1
unnamed: K18.11, K18.21, R42.2, R43.1, R48.2
unnamed: K19.11, K19.21, R43.2, R44.1
unnamed: K20.14, K20.24, R44.2, R45.1
unnamed: K21.14, K21.24, K23.14, K23.24, K24.14, K24.24, K25.14, K25.24, K26.11, K26.21, K27.11, K27.21, K28.14, K28.24, R54.2, R58.1, R64.1
unnamed: K22.11, K22.21, K23.11, K23.21, R49.2, R50.1, R55.2, R56.1
unnamed: K24.11, K24.21, R51.2, R52.1, R57.2
unnamed: K25.11, K25.21, R52.2, R53.1
unnamed: K26.14, K26.24, R53.2, R54.1
unnamed: K27.14, K27.24, K29.14, K29.24, K30.14, K30.24, K31.14, K31.24, K32.11, K32.21, K33.11, K33.21, K34.14, K34.24, R63.2, R67.1, R73.1
unnamed: K28.11, K28.21, K29.11, K29.21, R58.2, R59.1, R64.2, R65.1
unnamed: K30.11, K30.21, R60.2, R61.1, R66.2
unnamed: K31.11, K31.21, R61.2, R62.1
unnamed: K32.14, K32.24, R62.2, R63.1
unnamed: K34.11, K34.21, K35.11, K35.21, R67.2, R68.1, R73.2, R74.1
unnamed: K36.11, K36.21, R69.2, R70.1, R75.2
unnamed: K37.11, K37.21, R70.2, R71.1
unnamed: K38.14, K38.24, R71.2, R72.1
unnamed: Q1.1 (G), R82.1
unnamed: R23.2, R24.1, R29.2, R30.1
unnamed: R32.2, R33.1, R38.2, R39.1
unnamed: R41.2, R42.1, R47.2, R48.1
unnamed: R50.2, R51.1, R56.2, R57.1
unnamed: R59.2, R60.1, R65.2, R66.1
unnamed: R68.2, R69.1, R74.2, R75.1
Vdrive: K1.A1, K2.A1, K3.A1, K4.A1, K5.A1, K6.A1, K7.A1, K8.A1, K9.A1, K10.A1, K11.A1, K12.A1, K13.A1, K14.A1, K15.A1, K16.A1, K17.A1, K18.A1, K19.A1, K20.A1, K21.A1, K22.A1, K23.A1, K24.A1, K25.A1, K26.A1, K27.A1, K28.A1, K29.A1, K30.A1, K31.A1, K32.A1, K33.A1, K34.A1, K35.A1, K36.A1, K37.A1, K38.A1, K39.14, K39.24; also elsewhere on the board

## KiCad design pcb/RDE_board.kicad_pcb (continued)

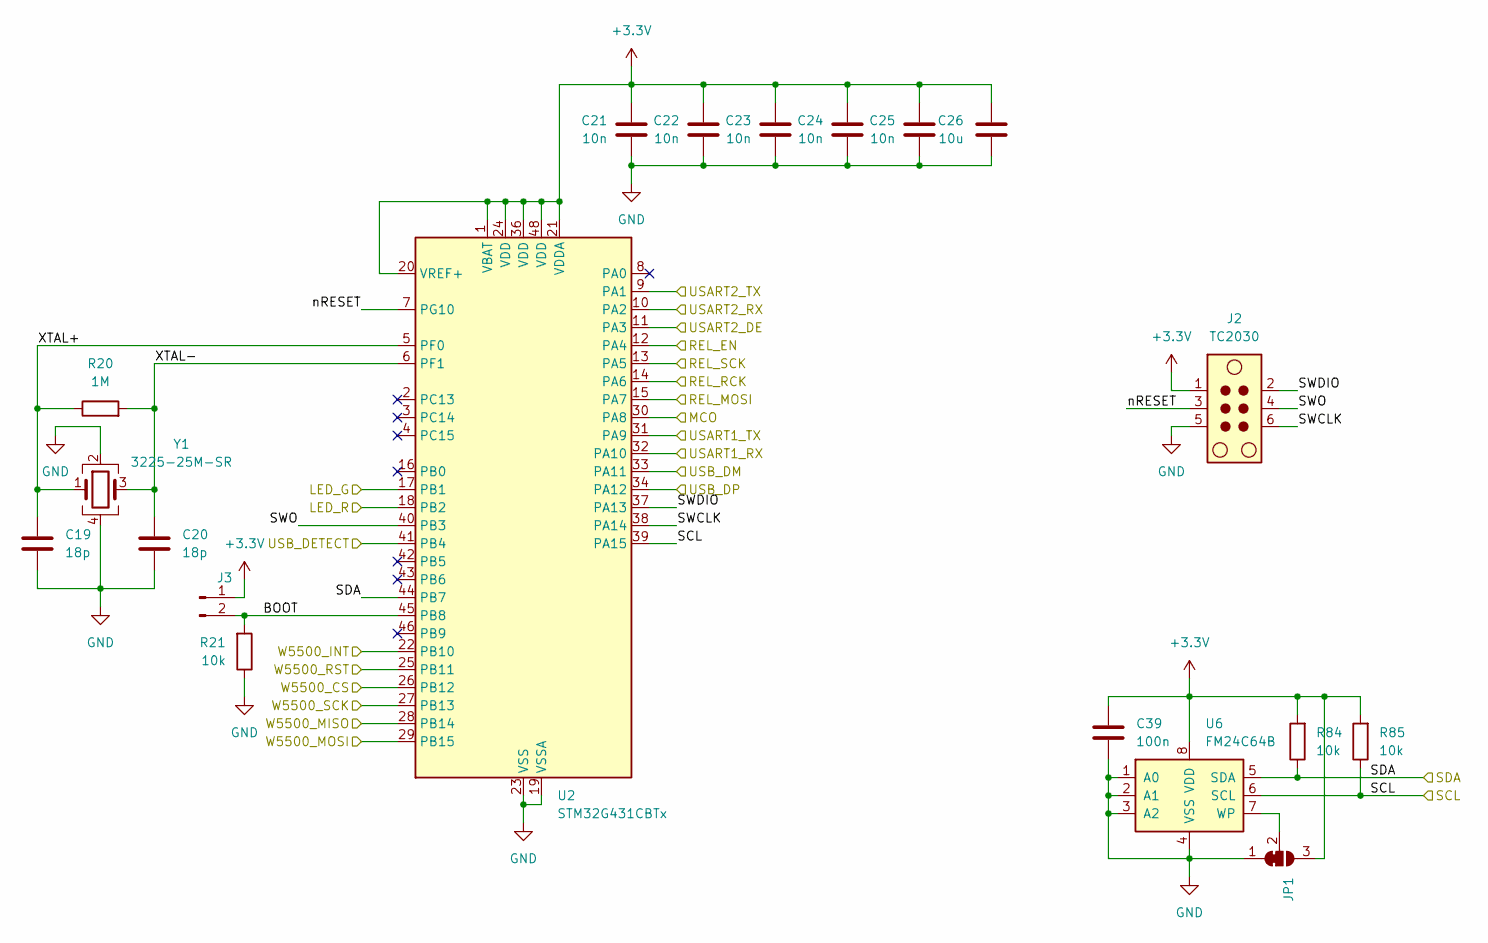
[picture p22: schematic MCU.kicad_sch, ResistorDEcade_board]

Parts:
C19, C20: 18p; C_0402_1005Metric_Pad0.74x0.62mm_HandSolder
C21, C22, C23, C24, C25: 10n; C_0603_1608Metric_Pad1.08x0.95mm_HandSolder
C26: 10u; C_1206_3216Metric_Pad1.33x1.80mm_HandSolder
C39: 100n; C_0603_1608Metric_Pad1.08x0.95mm_HandSolder
J2: TC2030; Tag-Connect_TC2030-IDC-NL_2x03_P1.27mm_Vertical
J3: Conn_01x02_Pin; PinHeader_1x02_P2.00mm_Vertical
JP1: SolderJumper_3_Bridged12; SolderJumper-3_P1.3mm_Bridged12_Pad1.0x1.5mm
R20: 1M; R_0402_1005Metric_Pad0.72x0.64mm_HandSolder
R21, R84, R85: 10k; R_0603_1608Metric_Pad0.98x0.95mm_HandSolder
U2: STM32G431CBTx; LQFP-48_7x7mm_P0.5mm
U6: FM24C64B; SOIC-8_3.9x4.9mm_P1.27mm
Y1: 3225-25M-SR; Crystal_SMD_3225-4Pin_3.2x2.5mm

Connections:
+3.3V: C21.2, C22.2, C23.2, C24.2, C25.2, C26.1, C39.1, J2.1, J3.1, JP1.3 (B), R84.2, R85.2, U2.1 (VBAT), U2.20 (VREF+), U2.21 (VDDA), U2.24 (VDD), U2.36 (VDD), U2.48 (VDD), U6.8 (VDD); also elsewhere on the board
/ConnectorDIN41612/DE: U2.11 (PA3); also elsewhere on the board
/ConnectorDIN41612/RxD: U2.10 (PA2); also elsewhere on the board
/ConnectorDIN41612/TxD: U2.9 (PA1); also elsewhere on the board
/ConnectorDIN41612/USART+: U2.31 (PA9); also elsewhere on the board
/ConnectorDIN41612/USART-: U2.32 (PA10); also elsewhere on the board
/ConnectorDIN41612/USB_D+: U2.34 (PA12); also elsewhere on the board
/ConnectorDIN41612/USB_D-: U2.33 (PA11); also elsewhere on the board
/ConnectorDIN41612/USB_DET: U2.41 (PB4); also elsewhere on the board
/EthernetPHY/CLKIN: U2.30 (PA8); also elsewhere on the board
/EthernetPHY/CS: U2.26 (PB12); also elsewhere on the board
/EthernetPHY/INT: U2.22 (PB10); also elsewhere on the board
/EthernetPHY/MISO: U2.28 (PB14); also elsewhere on the board
/EthernetPHY/MOSI: U2.29 (PB15); also elsewhere on the board
/EthernetPHY/RST: U2.25 (PB11); also elsewhere on the board
/EthernetPHY/SCK: U2.27 (PB13); also elsewhere on the board
/Frontend/RCK: U2.14 (PA6); also elsewhere on the board
/Frontend/REL_EN: U2.12 (PA4); also elsewhere on the board
/Frontend/SER_IN: U2.15 (PA7); also elsewhere on the board
/Frontend/SRCK: U2.13 (PA5); also elsewhere on the board
/MCU/BOOT: J3.2, R21.2, U2.45 (PB8)
/MCU/LED_G: U2.17 (PB1); also elsewhere on the board
/MCU/LED_R: U2.18 (PB2); also elsewhere on the board
/MCU/SCL: R85.1, U2.39 (PA15), U6.6 (SCL); also elsewhere on the board
/MCU/SDA: R84.1, U2.44 (PB7), U6.5 (SDA); also elsewhere on the board
/MCU/SWCLK: J2.6, U2.38 (PA14)
/MCU/SWDIO: J2.2, U2.37 (PA13)
/MCU/SWO: J2.4, U2.40 (PB3)
/MCU/XTAL+: C19.1, R20.1, U2.5 (PF0), Y1.1
/MCU/XTAL-: C20.1, R20.2, U2.6 (PF1), Y1.3
/MCU/nRESET: J2.3, U2.7 (PG10)
GND: C19.2, C20.2, C21.1, C22.1, C23.1, C24.1, C25.1, C26.2, C39.2, J2.5, JP1.1 (A), R21.1, U2.19 (VSSA), U2.23 (VSS), U2.35 (VSS), U2.47 (VSS), U6.1 (A0), U6.2 (A1), U6.3 (A2), U6.4 (VSS), Y1.2, Y1.4; also elsewhere on the board
unnamed: JP1.2 (C), U6.7 (WP)

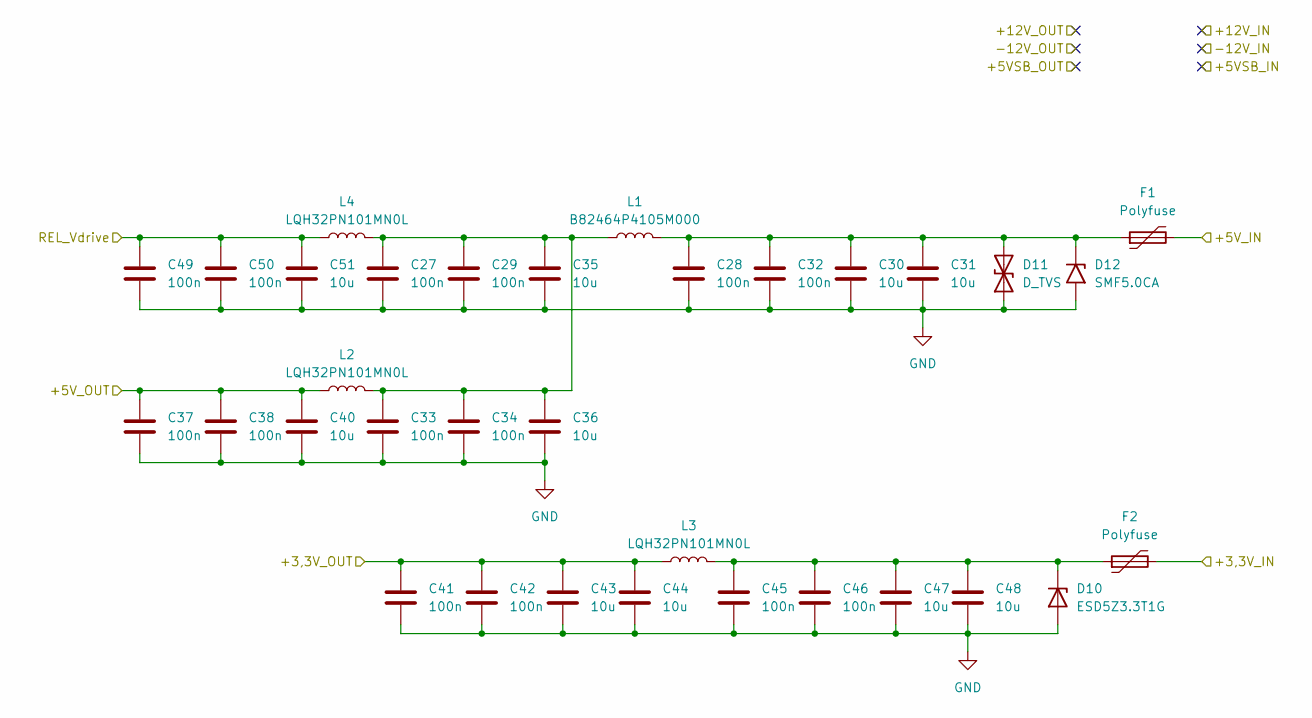
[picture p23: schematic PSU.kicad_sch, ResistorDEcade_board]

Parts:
C27, C28, C29, C32, C33, C34, C37, C38, C41, C42, C45, C46, C49, C50: 100n; C_0603_1608Metric_Pad1.08x0.95mm_HandSolder
C30, C31, C35, C36, C40, C43, C44, C47, C48, C51: 10u; C_1206_3216Metric_Pad1.33x1.80mm_HandSolder
D10: ESD5Z3.3T1G; D_SOD-523
D11: D_TVS; D_MiniMELF
D12: SMF5.0CA; D_SMF
F1, F2: Polyfuse; Fuse_1206_3216Metric_Pad1.42x1.75mm_HandSolder
L1: B82464P4105M000; L_10.4x10.4_H4.8
L2, L3, L4: LQH32PN101MN0L; L_1210_3225Metric

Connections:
+3.3V: C41.1, C42.1, C43.1, C44.1, L3.1; also elsewhere on the board
+5V: C37.1, C38.1, C40.1, L2.1; also elsewhere on the board
/ConnectorDIN41612/PSU/+3,3V_IN: F2.2; also elsewhere on the board
/ConnectorDIN41612/PSU/+5V_IN: F1.2; also elsewhere on the board
/ConnectorDIN41612/REL_Vdrive: C49.1, C50.1, C51.1, L4.1; also elsewhere on the board
GND: C27.2, C28.2, C29.2, C30.2, C31.2, C32.2, C33.2, C34.2, C35.2, C36.2, C37.2, C38.2, C40.2, C41.2, C42.2, C43.2, C44.2, C45.2, C46.2, C47.2, C48.2, C49.2, C50.2, C51.2, D10.2 (A), D11.1 (A1), D12.2 (A2); also elsewhere on the board
unnamed: C27.1, C29.1, C33.1, C34.1, C35.1, C36.1, L1.1, L2.2, L4.2
unnamed: C45.1, C46.1, C47.1, C48.1, D10.1 (K), F2.1, L3.2
unnamed: C28.1, C30.1, C31.1, C32.1, D11.2 (A2), D12.1 (A1), F1.1, L1.2

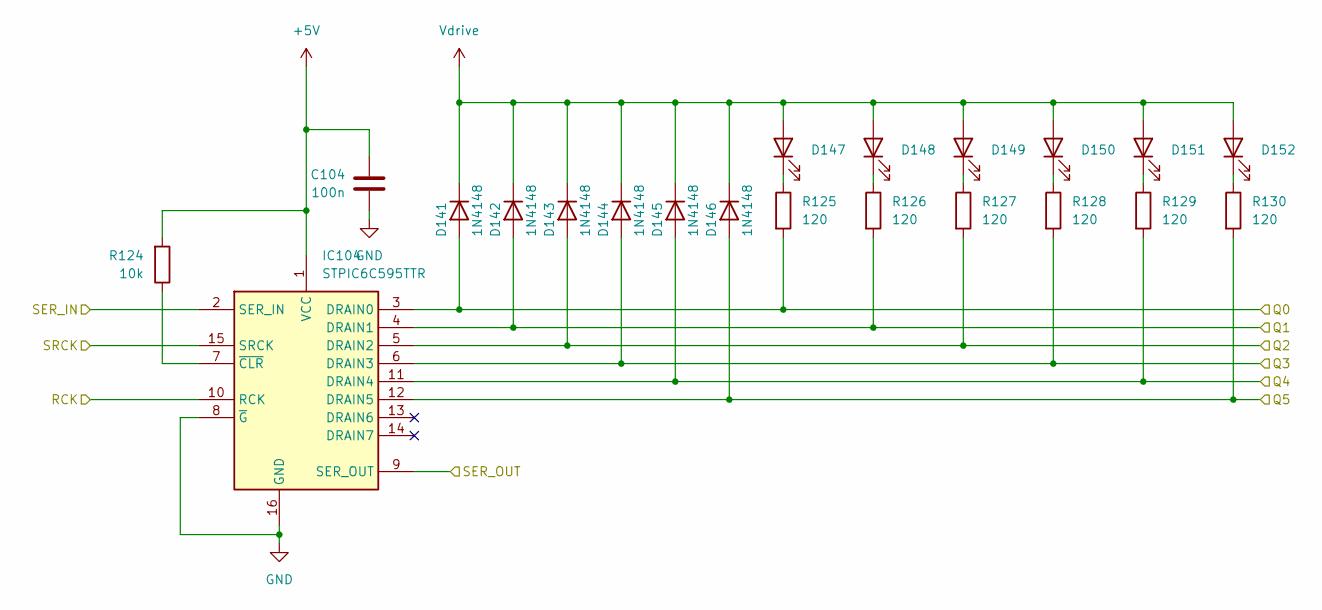
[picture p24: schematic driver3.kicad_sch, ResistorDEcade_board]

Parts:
C104: 100n; C_0603_1608Metric_Pad1.08x0.95mm_HandSolder
D141, D142, D143, D144, D145, D146: 1N4148; D_MiniMELF
D147, D148, D149, D150, D151, D152: LED_0603_1608Metric_Pad1.05x0.95mm_HandSolder
IC104: STPIC6C595TTR; SOP65P640X120-16N; Manufacturer_Part_Number STPIC6C595TTR
R124: 10k; R_0603_1608Metric_Pad0.98x0.95mm_HandSolder
R125, R126, R127, R128, R129, R130: 120; R_0603_1608Metric_Pad0.98x0.95mm_HandSolder

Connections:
+5V: C104.2, IC104.1 (VCC), R124.2; also elsewhere on the board
/Frontend/1x1k: D142.2 (A), IC104.4 (DRAIN1), R126.2; also elsewhere on the board
/Frontend/2x1k: D143.2 (A), IC104.5 (DRAIN2), R127.2; also elsewhere on the board
/Frontend/3x1k: D144.2 (A), IC104.6 (DRAIN3), R128.2; also elsewhere on the board
/Frontend/4x1k: D145.2 (A), IC104.11 (DRAIN4), R129.2; also elsewhere on the board
/Frontend/5x1k: D146.2 (A), IC104.12 (DRAIN5), R130.2; also elsewhere on the board
/Frontend/Driver2/SER_OUT: IC104.2 (SER_IN); also elsewhere on the board
/Frontend/Driver3/SER_OUT: IC104.9 (SER_OUT); also elsewhere on the board
/Frontend/RCK: IC104.10 (RCK); also elsewhere on the board
/Frontend/SHORTx1k: D141.2 (A), IC104.3 (DRAIN0), R125.2; also elsewhere on the board
/Frontend/SRCK: IC104.15 (SRCK); also elsewhere on the board
GND: C104.1, IC104.8 (~G), IC104.16 (GND); also elsewhere on the board
unnamed: D147.1 (K), R125.1
unnamed: D148.1 (K), R126.1
unnamed: D149.1 (K), R127.1
unnamed: D150.1 (K), R128.1
unnamed: D151.1 (K), R129.1
unnamed: D152.1 (K), R130.1
unnamed: IC104.7 (~CLR), R124.1
Vdrive: D141.1 (K), D142.1 (K), D143.1 (K), D144.1 (K), D145.1 (K), D146.1 (K), D147.2 (A), D148.2 (A), D149.2 (A), D150.2 (A), D151.2 (A), D152.2 (A); also elsewhere on the board

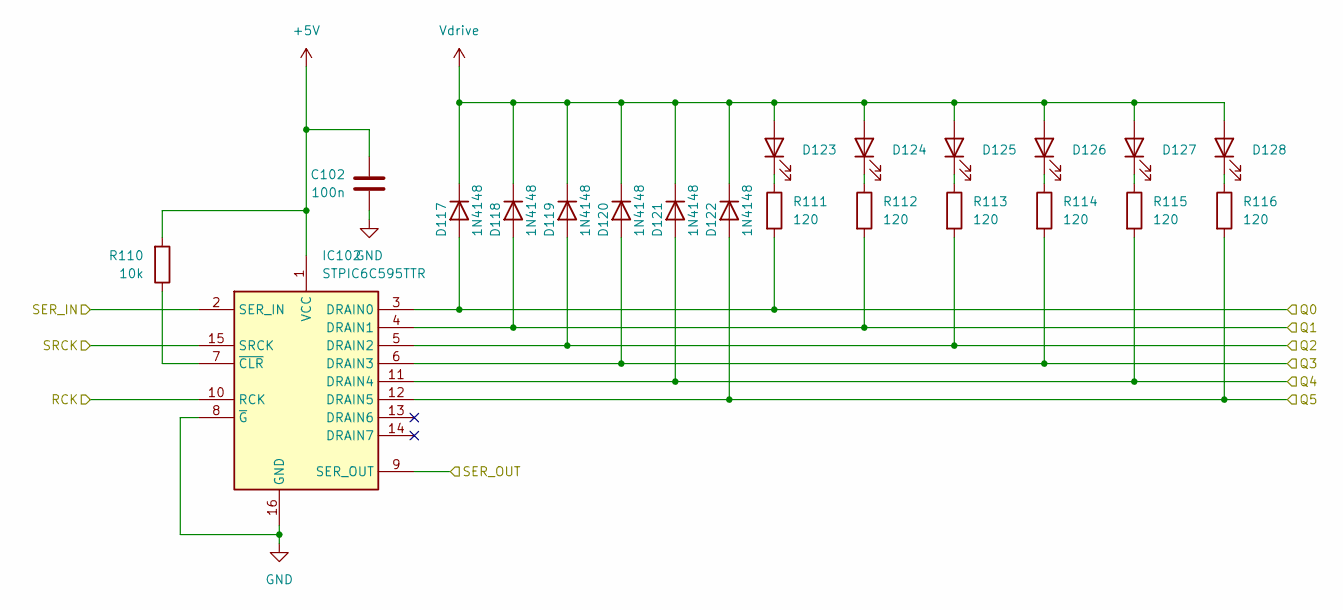
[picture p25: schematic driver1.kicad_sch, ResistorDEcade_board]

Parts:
C102: 100n; C_0603_1608Metric_Pad1.08x0.95mm_HandSolder
D117, D118, D119, D120, D121, D122: 1N4148; D_MiniMELF
D123, D124, D125, D126, D127, D128: LED_0603_1608Metric_Pad1.05x0.95mm_HandSolder
IC102: STPIC6C595TTR; SOP65P640X120-16N; Manufacturer_Part_Number STPIC6C595TTR
R110: 10k; R_0603_1608Metric_Pad0.98x0.95mm_HandSolder
R111, R112, R113, R114, R115, R116: 120; R_0603_1608Metric_Pad0.98x0.95mm_HandSolder

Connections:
+5V: C102.2, IC102.1 (VCC), R110.2; also elsewhere on the board
/Frontend/1x10: D118.2 (A), IC102.4 (DRAIN1), R112.2; also elsewhere on the board
/Frontend/2x10: D119.2 (A), IC102.5 (DRAIN2), R113.2; also elsewhere on the board
/Frontend/3x10: D120.2 (A), IC102.6 (DRAIN3), R114.2; also elsewhere on the board
/Frontend/4x10: D121.2 (A), IC102.11 (DRAIN4), R115.2; also elsewhere on the board
/Frontend/5x10: D122.2 (A), IC102.12 (DRAIN5), R116.2; also elsewhere on the board
/Frontend/Driver1/SER_OUT: IC102.9 (SER_OUT); also elsewhere on the board
/Frontend/Driver/SER_OUT: IC102.2 (SER_IN); also elsewhere on the board
/Frontend/RCK: IC102.10 (RCK); also elsewhere on the board
/Frontend/SHORTx10: D117.2 (A), IC102.3 (DRAIN0), R111.2; also elsewhere on the board
/Frontend/SRCK: IC102.15 (SRCK); also elsewhere on the board
GND: C102.1, IC102.8 (~G), IC102.16 (GND); also elsewhere on the board
unnamed: D123.1 (K), R111.1
unnamed: D124.1 (K), R112.1
unnamed: D125.1 (K), R113.1
unnamed: D126.1 (K), R114.1
unnamed: D127.1 (K), R115.1
unnamed: D128.1 (K), R116.1
unnamed: IC102.7 (~CLR), R110.1
Vdrive: D117.1 (K), D118.1 (K), D119.1 (K), D120.1 (K), D121.1 (K), D122.1 (K), D123.2 (A), D124.2 (A), D125.2 (A), D126.2 (A), D127.2 (A), D128.2 (A); also elsewhere on the board

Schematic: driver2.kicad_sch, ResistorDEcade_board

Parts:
C103: 100n; C_0603_1608Metric_Pad1.08x0.95mm_HandSolder
D129, D130, D131, D132, D133, D134: 1N4148; D_MiniMELF
D135, D136, D137, D138, D139, D140: LED_0603_1608Metric_Pad1.05x0.95mm_HandSolder
IC103: STPIC6C595TTR; SOP65P640X120-16N; Manufacturer_Part_Number STPIC6C595TTR
R117: 10k; R_0603_1608Metric_Pad0.98x0.95mm_HandSolder
R118, R119, R120, R121, R122, R123: 120; R_0603_1608Metric_Pad0.98x0.95mm_HandSolder

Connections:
+5V: C103.2, IC103.1 (VCC), R117.2; also elsewhere on the board
/Frontend/1x100: D130.2 (A), IC103.4 (DRAIN1), R119.2; also elsewhere on the board
/Frontend/2x100: D131.2 (A), IC103.5 (DRAIN2), R120.2; also elsewhere on the board
/Frontend/3x100: D132.2 (A), IC103.6 (DRAIN3), R121.2; also elsewhere on the board
/Frontend/4x100: D133.2 (A), IC103.11 (DRAIN4), R122.2; also elsewhere on the board
/Frontend/5x100: D134.2 (A), IC103.12 (DRAIN5), R123.2; also elsewhere on the board
/Frontend/Driver1/SER_OUT: IC103.2 (SER_IN); also elsewhere on the board
/Frontend/Driver2/SER_OUT: IC103.9 (SER_OUT); also elsewhere on the board
/Frontend/RCK: IC103.10 (RCK); also elsewhere on the board
/Frontend/SHORTx100: D129.2 (A), IC103.3 (DRAIN0), R118.2; also elsewhere on the board
/Frontend/SRCK: IC103.15 (SRCK); also elsewhere on the board
GND: C103.1, IC103.8 (~G), IC103.16 (GND); also elsewhere on the board
unnamed: D135.1 (K), R118.1
unnamed: D136.1 (K), R119.1
unnamed: D137.1 (K), R120.1
unnamed: D138.1 (K), R121.1
unnamed: D139.1 (K), R122.1
unnamed: D140.1 (K), R123.1
unnamed: IC103.7 (~CLR), R117.1
Vdrive: D129.1 (K), D130.1 (K), D131.1 (K), D132.1 (K), D133.1 (K), D134.1 (K), D135.2 (A), D136.2 (A), D137.2 (A), D138.2 (A), D139.2 (A), D140.2 (A); also elsewhere on the board

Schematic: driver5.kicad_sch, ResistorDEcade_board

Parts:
C106: 100n; C_0603_1608Metric_Pad1.08x0.95mm_HandSolder
D165, D166, D167, D168, D169, D170: 1N4148; D_MiniMELF
D171, D172, D173, D174, D175, D176: LED_0603_1608Metric_Pad1.05x0.95mm_HandSolder
IC106: STPIC6C595TTR; SOP65P640X120-16N; Manufacturer_Part_Number STPIC6C595TTR
R138: 10k; R_0603_1608Metric_Pad0.98x0.95mm_HandSolder
R139, R140, R141, R142, R143, R144: 120; R_0603_1608Metric_Pad0.98x0.95mm_HandSolder

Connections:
+5V: C106.2, IC106.1 (VCC), R138.2; also elsewhere on the board
/Frontend/1x100k: D166.2 (A), IC106.4 (DRAIN1), R140.2; also elsewhere on the board
/Frontend/2x100k: D167.2 (A), IC106.5 (DRAIN2), R141.2; also elsewhere on the board
/Frontend/3x100k: D168.2 (A), IC106.6 (DRAIN3), R142.2; also elsewhere on the board
/Frontend/4x100k: D169.2 (A), IC106.11 (DRAIN4), R143.2; also elsewhere on the board
/Frontend/5x100k: D170.2 (A), IC106.12 (DRAIN5), R144.2; also elsewhere on the board
/Frontend/Driver4/SER_OUT: IC106.2 (SER_IN); also elsewhere on the board
/Frontend/Driver5/SER_OUT: IC106.9 (SER_OUT)
/Frontend/RCK: IC106.10 (RCK); also elsewhere on the board
/Frontend/SHORTx100k: D165.2 (A), IC106.3 (DRAIN0), R139.2; also elsewhere on the board
/Frontend/SRCK: IC106.15 (SRCK); also elsewhere on the board
GND: C106.1, IC106.8 (~G), IC106.16 (GND); also elsewhere on the board
unnamed: D171.1 (K), R139.1
unnamed: D172.1 (K), R140.1
unnamed: D173.1 (K), R141.1
unnamed: D174.1 (K), R142.1
unnamed: D175.1 (K), R143.1
unnamed: D176.1 (K), R144.1
unnamed: IC106.7 (~CLR), R138.1
Vdrive: D165.1 (K), D166.1 (K), D167.1 (K), D168.1 (K), D169.1 (K), D170.1 (K), D171.2 (A), D172.2 (A), D173.2 (A), D174.2 (A), D175.2 (A), D176.2 (A); also elsewhere on the board

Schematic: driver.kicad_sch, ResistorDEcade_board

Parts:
C101: 100n; C_0603_1608Metric_Pad1.08x0.95mm_HandSolder
D101, D102, D103, D104, D105, D106, D107, D108: 1N4148; D_MiniMELF
D109, D110, D111, D112, D113, D114, D115, D116: LED_0603_1608Metric_Pad1.05x0.95mm_HandSolder
IC101: STPIC6C595TTR; SOP65P640X120-16N; Manufacturer_Part_Number STPIC6C595TTR
R101: 10k; R_0603_1608Metric_Pad0.98x0.95mm_HandSolder
R102, R103, R104, R105, R106, R107, R108, R109: 120; R_0603_1608Metric_Pad0.98x0.95mm_HandSolder

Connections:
+5V: C101.2, IC101.1 (VCC), R101.2; also elsewhere on the board
/Frontend/1x1: D102.2 (A), IC101.4 (DRAIN1), R103.2; also elsewhere on the board
/Frontend/2x1: D103.2 (A), IC101.5 (DRAIN2), R104.2; also elsewhere on the board
/Frontend/3x1: D104.2 (A), IC101.6 (DRAIN3), R105.2; also elsewhere on the board
/Frontend/4x1: D105.2 (A), IC101.11 (DRAIN4), R106.2; also elsewhere on the board
/Frontend/5x1: D106.2 (A), IC101.12 (DRAIN5), R107.2; also elsewhere on the board
/Frontend/Driver/SER_OUT: IC101.9 (SER_OUT); also elsewhere on the board
/Frontend/FRONT: D107.2 (A), IC101.13 (DRAIN6), R108.2; also elsewhere on the board
/Frontend/RCK: IC101.10 (RCK); also elsewhere on the board
/Frontend/SER_IN: IC101.2 (SER_IN); also elsewhere on the board
/Frontend/SHORT: D108.2 (A), IC101.14 (DRAIN7), R109.2; also elsewhere on the board
/Frontend/SHORTx1: D101.2 (A), IC101.3 (DRAIN0), R102.2; also elsewhere on the board
/Frontend/SRCK: IC101.15 (SRCK); also elsewhere on the board
GND: C101.1, IC101.8 (~G), IC101.16 (GND); also elsewhere on the board
unnamed: D109.1 (K), R102.1
unnamed: D110.1 (K), R103.1
unnamed: D111.1 (K), R104.1
unnamed: D112.1 (K), R105.1
unnamed: D113.1 (K), R106.1
unnamed: D114.1 (K), R107.1
unnamed: D115.1 (K), R108.1
unnamed: D116.1 (K), R109.1
unnamed: IC101.7 (~CLR), R101.1
Vdrive: D101.1 (K), D102.1 (K), D103.1 (K), D104.1 (K), D105.1 (K), D106.1 (K), D107.1 (K), D108.1 (K), D109.2 (A), D110.2 (A), D111.2 (A), D112.2 (A), D113.2 (A), D114.2 (A), D115.2 (A), D116.2 (A); also elsewhere on the board

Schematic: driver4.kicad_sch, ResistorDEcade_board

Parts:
C105: 100n; C_0603_1608Metric_Pad1.08x0.95mm_HandSolder
D153, D154, D155, D156, D157, D158: 1N4148; D_MiniMELF
D159, D160, D161, D162, D163, D164: LED_0603_1608Metric_Pad1.05x0.95mm_HandSolder
IC105: STPIC6C595TTR; SOP65P640X120-16N; Manufacturer_Part_Number STPIC6C595TTR
R131: 10k; R_0603_1608Metric_Pad0.98x0.95mm_HandSolder
R132, R133, R134, R135, R136, R137: 120; R_0603_1608Metric_Pad0.98x0.95mm_HandSolder

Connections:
+5V: C105.2, IC105.1 (VCC), R131.2; also elsewhere on the board
/Frontend/1x10k: D154.2 (A), IC105.4 (DRAIN1), R133.2; also elsewhere on the board
/Frontend/2x10k: D155.2 (A), IC105.5 (DRAIN2), R134.2; also elsewhere on the board
/Frontend/3x10k: D156.2 (A), IC105.6 (DRAIN3), R135.2; also elsewhere on the board
/Frontend/4x10k: D157.2 (A), IC105.11 (DRAIN4), R136.2; also elsewhere on the board
/Frontend/5x10k: D158.2 (A), IC105.12 (DRAIN5), R137.2; also elsewhere on the board
/Frontend/Driver3/SER_OUT: IC105.2 (SER_IN); also elsewhere on the board
/Frontend/Driver4/SER_OUT: IC105.9 (SER_OUT); also elsewhere on the board
/Frontend/RCK: IC105.10 (RCK); also elsewhere on the board
/Frontend/SHORTx10k: D153.2 (A), IC105.3 (DRAIN0), R132.2; also elsewhere on the board
/Frontend/SRCK: IC105.15 (SRCK); also elsewhere on the board
GND: C105.1, IC105.8 (~G), IC105.16 (GND); also elsewhere on the board
unnamed: D159.1 (K), R132.1
unnamed: D160.1 (K), R133.1
unnamed: D161.1 (K), R134.1
unnamed: D162.1 (K), R135.1
unnamed: D163.1 (K), R136.1
unnamed: D164.1 (K), R137.1
unnamed: IC105.7 (~CLR), R131.1
Vdrive: D153.1 (K), D154.1 (K), D155.1 (K), D156.1 (K), D157.1 (K), D158.1 (K), D159.2 (A), D160.2 (A), D161.2 (A), D162.2 (A), D163.2 (A), D164.2 (A); also elsewhere on the board

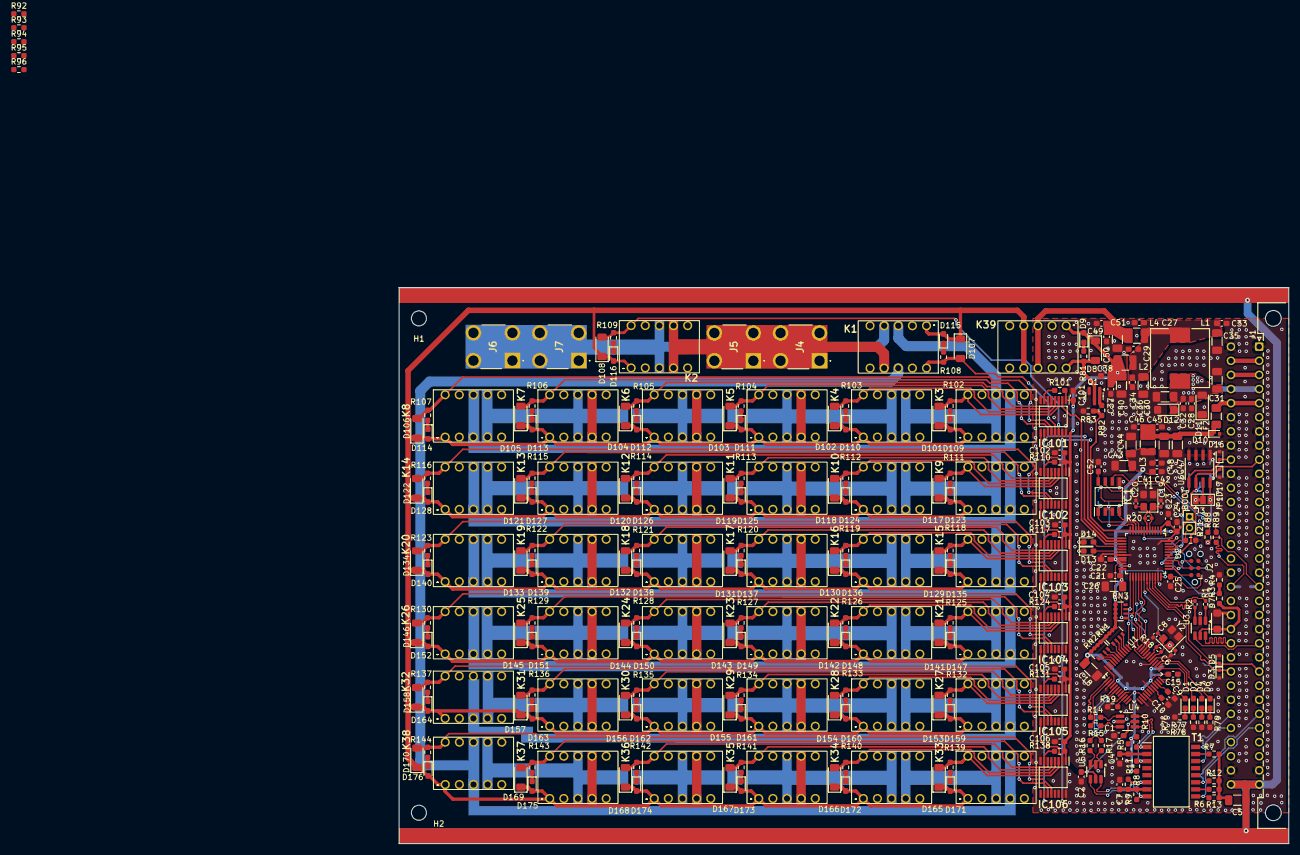
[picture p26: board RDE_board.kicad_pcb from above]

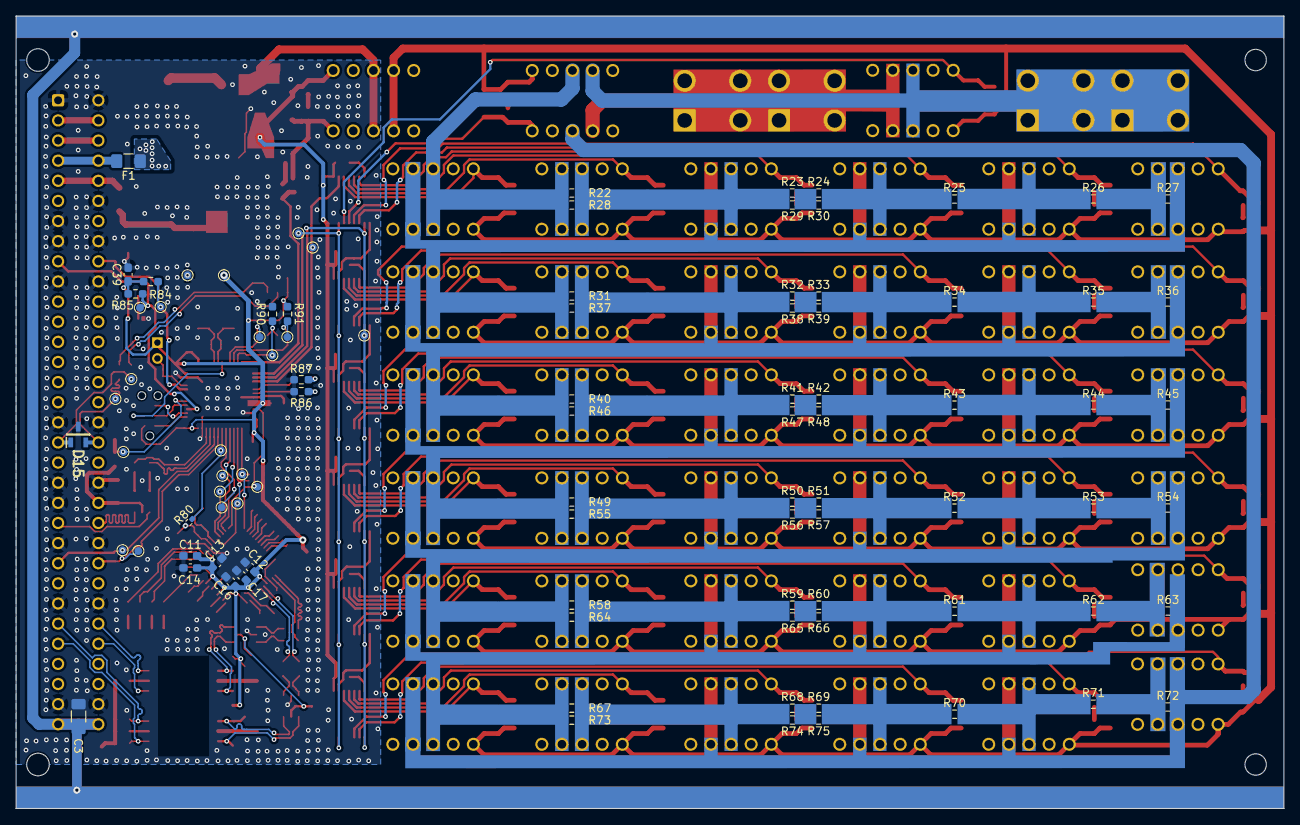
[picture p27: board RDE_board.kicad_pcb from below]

Board: 2 copper layers, 160.0 x 100.0 mm, 388 parts (93 on the bottom side), 230 nets.

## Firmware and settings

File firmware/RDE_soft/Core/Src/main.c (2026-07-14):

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
/* Includes ------------------------------------------------------------------*/
#include "main.h"

/* USER CODE BEGIN Includes */
#include "tusb.h"
#include "scpi_def.h"
#include "usbtmc_app.h"
#include "relay/relay_ctrl.h"
#include "relay/relay_cal.h"
#include "net_config.h"
#include "w5500_net.h"
/* USER CODE END Includes */

CRC_HandleTypeDef hcrc;

I2C_HandleTypeDef hi2c1;

SPI_HandleTypeDef hspi1;
SPI_HandleTypeDef hspi2;

UART_HandleTypeDef huart1;
UART_HandleTypeDef huart2;

PCD_HandleTypeDef hpcd_USB_FS;

void SystemClock_Config(void);
static void MX_GPIO_Init(void);
static void MX_I2C1_Init(void);
static void MX_SPI1_Init(void);
static void MX_SPI2_Init(void);
static void MX_USART1_UART_Init(void);
static void MX_USART2_UART_Init(void);
static void MX_USB_PCD_Init(void);
static void MX_CRC_Init(void);
/**
  * @brief  The application entry point.
  * @retval int
  */
int main(void)
{

  /* MCU Configuration--------------------------------------------------------*/

  /* Reset of all peripherals, Initializes the Flash interface and the Systick. */
  HAL_Init();

  /* Configure the system clock */
  SystemClock_Config();

  /* Initialize all configured peripherals */
  MX_GPIO_Init();
  MX_I2C1_Init();
  MX_SPI1_Init();
  MX_SPI2_Init();
  MX_USART1_UART_Init();
  MX_USART2_UART_Init();
  MX_USB_PCD_Init();
  MX_CRC_Init();
  /* USER CODE BEGIN 2 */

  /* CRS: trim HSI48 via USB SOF – required for USB ±500 ppm clock accuracy */
  __HAL_RCC_CRS_CLK_ENABLE();
  RCC_CRSInitTypeDef crs_init = {0};
  crs_init.Prescaler             = RCC_CRS_SYNC_DIV1;
  crs_init.Source                = RCC_CRS_SYNC_SOURCE_USB;
  crs_init.Polarity              = RCC_CRS_SYNC_POLARITY_RISING;
  crs_init.ReloadValue           = __HAL_RCC_CRS_RELOADVALUE_CALCULATE(48000000, 1000);
  crs_init.ErrorLimitValue       = 34;
  crs_init.HSI48CalibrationValue = 32;
  HAL_RCCEx_CRSConfig(&crs_init);

  HAL_GPIO_WritePin(REL_EN_GPIO_Port, REL_EN_Pin, GPIO_PIN_RESET); /* relay PSU off – activate via relay_enable(true) */
  relay_init();
  SCPI_Main_Init();   /* init SCPI early so startup errors can be pushed to the queue */

  net_config_init();   /* load network config from NVM before w5500_net_init */
  relay_cal_init();    /* load decade calibration from NVM */

  tud_init(BOARD_TUD_RHPORT);
  tud_disconnect();   /* self-powered: do not pull D+ until VUSB detected */
  w5500_net_init();
  /* USER CODE END 2 */

  /* Infinite loop */
  /* USER CODE BEGIN WHILE */
  while (1)
  {
    /* USER CODE END WHILE */

    /* USER CODE BEGIN 3 */

    /* ── LED_G heartbeat – toggle every 500 ms (1 Hz blink) ── */
    static uint32_t led_tick = 0u;
    if (HAL_GetTick() - led_tick >= 500u) {
        led_tick = HAL_GetTick();
        HAL_GPIO_TogglePin(LED_G_GPIO_Port, LED_G_Pin);
    }

    /* ── LED_R error indicator – ON while SCPI error queue non-empty ── */
    /* Cleared automatically when SYST:ERR:NEXT? drains the queue or *CLS is sent */
    HAL_GPIO_WritePin(LED_R_GPIO_Port, LED_R_Pin,
                      SCPI_Main_HasErrors() ? GPIO_PIN_SET : GPIO_PIN_RESET);

    /* ── USB_DETECT – connect/disconnect D+ based on VUSB presence ── */
    /* 20 ms debounce: require stable signal before acting to avoid spurious
     * connect/disconnect on VBUS glitches. */
    static bool     usb_prev    = false;
    static bool     usb_stable  = false;
    static uint32_t usb_deb_ms  = 0;
    bool usb_raw = (HAL_GPIO_ReadPin(USB_DETECT_GPIO_Port, USB_DETECT_Pin) == GPIO_PIN_SET);
    if (usb_raw != usb_stable) {
        if (HAL_GetTick() - usb_deb_ms >= 20u) {
            usb_stable = usb_raw;
        }
    } else {
        usb_deb_ms = HAL_GetTick();
    }
    bool usb_now = usb_stable;

    if (usb_now && !usb_prev) {
        tud_connect();
    } else if (!usb_now && usb_prev) {
        tud_disconnect();
    }
    usb_prev = usb_now;

    /* ── USB tasks (only while VUSB present) ── */
    if (usb_now) {
        tud_task();
        usbtmc_app_task_iter();
    }

    SCPI_Main_Poll();
    w5500_net_task();

  }
  /* USER CODE END 3 */
}

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


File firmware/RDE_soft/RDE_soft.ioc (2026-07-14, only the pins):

Mcu.UserName=STM32G431CBTx
PA1.Signal=USART2_DE
PA10.Signal=USART1_RX
PA11.Signal=USB_DM
PA12.Signal=USB_DP
PA13.Signal=SYS_JTMS-SWDIO
PA14.Signal=SYS_JTCK-SWCLK
PA15.Signal=I2C1_SCL
PA2.Signal=USART2_TX
PA3.Signal=USART2_RX
PA4.GPIO_Label=REL_EN
PA4.Signal=GPIO_Output
PA5.GPIO_Label=REL_SCK
PA5.Signal=SPI1_SCK
PA6.GPIO_Label=REL_RCK
PA6.Signal=GPIO_Output
PA7.GPIO_Label=REL_MOSI
PA7.Signal=SPI1_MOSI
PA8.GPIO_Label=W5500_CLK
PA8.Signal=RCC_MCO
PA9.Signal=USART1_TX
PB1.GPIO_Label=LED_G
PB1.Signal=GPIO_Output
PB10.GPIO_Label=W5500_INT
PB10.Signal=GPIO_Input
PB11.GPIO_Label=W5500_RST
PB11.Signal=GPIO_Output
PB12.GPIO_Label=W5500_CS
PB12.Signal=GPIO_Output
PB13.GPIO_Label=W5500_SCK
PB13.Signal=SPI2_SCK
PB14.GPIO_Label=W5500_MISO
PB14.Signal=SPI2_MISO
PB15.GPIO_Label=W5500_MOSI
PB15.Signal=SPI2_MOSI
PB2.GPIO_Label=LED_R
PB2.Signal=GPIO_Output
PB3.Signal=SYS_JTDO-SWO
PB4.GPIO_Label=USB_DETECT
PB4.Signal=GPIO_Input
PB7.Signal=I2C1_SDA
PF0-OSC_IN.Signal=RCC_OSC_IN
PF1-OSC_OUT.Signal=RCC_OSC_OUT

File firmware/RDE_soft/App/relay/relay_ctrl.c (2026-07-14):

/*
 * relay_ctrl.c – 6x STPIC6C595TTR resistance decade relay driver
 *
 * Topology (1-2-2-2-2 series string with taps):
 *
 *   IN ─┬─────[R1=1]─────[R2=2]─────[R3=2]─────[R4=2]─────[R5=2]─── TO_NEXT
 *       │          │            │           │           │
 *      SW1        SW3          SW4         SW5         SW6
 *   (Q0=bypass) (Q2=tap) (Q3=tap) (Q4=tap) (Q5=tap)
 *       └────────────────────────────────────────────────────────────── OUT bus
 *
 *   SW2 (Q1): connects IN directly to after-R1 (bypasses R1)
 *
 * Value encoding per decade digit d (0-9):
 *   d=0:     Q0=1  (SW1 closed → direct short of this decade)
 *   d=1:     Q2=1  (SW3, tap after R1=1Ω)
 *   d=2:     Q1=1, Q3=1  (bypass R1, tap after R2→2Ω)
 *   d=3:     Q3=1  (tap after R1+R2=3Ω)
 *   d=4:     Q1=1, Q4=1  (bypass R1, tap after R3→4Ω)
 *   d=5:     Q4=1  (tap after R1+R2+R3=5Ω)
 *   d=6:     Q1=1, Q5=1  (bypass R1, tap after R4→6Ω)
 *   d=7:     Q5=1  (tap after R1+R2+R3+R4=7Ω)
 *   d=8:     Q1=1  (bypass R1, all taps open → R2+R3+R4+R5=8Ω)
 *   d=9:     all 0 (R1+R2+R3+R4+R5=9Ω through-path)
 *
 * STPIC sink-mode: bit 1 in shift register → DRAIN LOW → relay energised (CLOSED).
 *
 * Output relay states (Q6/Q7 in data[5]):
 *   Resistance >0 Ω : Q6=1 (CONNECT ON),  Q7=0 (SHORT OFF)
 *   Resistance = 0 Ω : Q6=0 (CONNECT OFF), Q7=1 (SHORT ON) – only SHORT relay used
 *   Output OFF      : Q6=0 (CONNECT OFF),  Q7=1 (SHORT ON) – terminals shorted (safe)
 *
 * Resistance change: relay values are written directly – no SHORT toggle during change.
 */

#include "relay_ctrl.h"
#include "main.h"
#include "stm32g4xx_hal.h"
#include <string.h>

extern SPI_HandleTypeDef hspi1;

/* ── Private state ─────────────────────────────────────────────────────── */

static uint8_t  relay_state[6]     = {0x00, 0x00, 0x00, 0x00, 0x00, 0x00};
static uint8_t  decade_digits[6]   = {0, 0, 0, 0, 0, 0};
static uint32_t current_resistance = 0;
static bool     output_connected   = false;
static bool     relay_en_state     = false;

/* ── SPI transfer ──────────────────────────────────────────────────────── */

static void relay_latch(void)
{
    HAL_GPIO_WritePin(REL_RCK_GPIO_Port, REL_RCK_Pin, GPIO_PIN_RESET);
    HAL_GPIO_WritePin(REL_RCK_GPIO_Port, REL_RCK_Pin, GPIO_PIN_SET);
    HAL_GPIO_WritePin(REL_RCK_GPIO_Port, REL_RCK_Pin, GPIO_PIN_RESET);
}

/* ── Decade encoding ───────────────────────────────────────────────────── */

/*
 * Returns the 8-bit STPIC output word for a single decade digit d (0–9).
 * STPIC sink: 1 = relay ON (DRAIN LOW, coil energised), 0 = relay OFF.
 * Bits 6 and 7 are left 0 (protection relays set separately).
 */
static uint8_t decade_byte(uint8_t d)
{
    uint8_t bits = 0x00;  /* all relays OFF */

    switch (d) {
    case 0: bits |= (1u << 0);                     break;  /* Q0=ON (SW1 short)         */
    case 1: bits |= (1u << 2);                     break;  /* Q2=ON (SW3, 1R tap)        */
    case 2: bits |= ((1u<<1)|(1u<<3));             break;  /* Q1+Q3 (bypass+SW4, 2R)     */
    case 3: bits |= (1u << 3);                     break;  /* Q3=ON (SW4, 3R tap)        */
    case 4: bits |= ((1u<<1)|(1u<<4));             break;  /* Q1+Q4 (bypass+SW5, 4R)     */
    case 5: bits |= (1u << 4);                     break;  /* Q4=ON (SW5, 5R tap)        */
    case 6: bits |= ((1u<<1)|(1u<<5));             break;  /* Q1+Q5 (bypass+SW6, 6R)     */
    case 7: bits |= (1u << 5);                     break;  /* Q5=ON (SW6, 7R tap)        */
    case 8: bits |= (1u << 1);                     break;  /* Q1=ON (bypass, 8R through) */
    case 9: /* all 0 → 9R full string */            break;
    default: break;
    }

    return bits;
}

/*
 * Build the full 6-byte data array from an ohms value.
 * data[0] → STPIC6 (100 kΩ decade), data[5] → STPIC1 (1 Ω decade).
 * Q6/Q7 bits in data[5] are NOT set here – caller sets them.
 */
static void build_data(uint32_t ohms, uint8_t data[6])
{
    static const uint32_t scale[6] = {100000, 10000, 1000, 100, 10, 1};
    uint32_t r = ohms;
    for (int i = 0; i < 6; i++) {
        uint8_t d = (uint8_t)(r / scale[i]);
        r %= scale[i];
        data[i] = decade_byte(d);
    }
}

/*
 * Write data array with correct Q6/Q7 for the given ohms value.
 *   ohms  > 0 : Q6=ON (CONNECT), Q7=OFF  – decade chain in circuit
 *   ohms == 0 : Q6=OFF,          Q7=ON   – SHORT relay only, decades all off
 */
static void apply_output(uint8_t data[6], uint32_t ohms)
{
    if (ohms == 0) {
        data[5] &= ~(1u << 6);  /* Q6=OFF: CONNECT open   */
        data[5] |=  (1u << 7);  /* Q7=ON:  SHORT closed   */
    } else {
        data[5] |=  (1u << 6);  /* Q6=ON:  CONNECT closed */
        data[5] &= ~(1u << 7);  /* Q7=OFF: SHORT open     */
    }
}

/* ── Public API ────────────────────────────────────────────────────────── */

void relay_init(void)
{
    HAL_GPIO_WritePin(REL_EN_GPIO_Port,  REL_EN_Pin,  GPIO_PIN_RESET);
    HAL_GPIO_WritePin(REL_RCK_GPIO_Port, REL_RCK_Pin, GPIO_PIN_RESET);

    /* Initial state: all relays open (deenergised) – 0 = relay OFF */
    uint8_t data[6];
    memset(data, 0x00, 6);

    memcpy(relay_state, data, 6);
    HAL_SPI_Transmit(&hspi1, data, 6, 20);
    relay_latch();
   // relay_enable(true);
}

void relay_set_raw(const uint8_t data[6])
{
    memcpy(relay_state, data, 6);
    HAL_SPI_Transmit(&hspi1, (uint8_t *)data, 6, 20);
    relay_latch();
}

void relay_enable(bool en)
{
    relay_en_state = en;
    HAL_GPIO_WritePin(REL_EN_GPIO_Port, REL_EN_Pin,
                      en ? GPIO_PIN_SET : GPIO_PIN_RESET);
}

bool relay_is_enabled(void)
{
    return relay_en_state;
}

void relay_get_raw(uint8_t out[6])
{
    memcpy(out, relay_state, 6);
}

void relay_set_resistance(uint32_t ohms)
{
    if (ohms > 999999u) ohms = 999999u;
    current_resistance = ohms;

    /* Populate decade_digits */
    static const uint32_t scale6[6] = {100000, 10000, 1000, 100, 10, 1};
    uint32_t r2 = ohms;
    for (int i = 0; i < 6; i++) {
        decade_digits[i] = (uint8_t)(r2 / scale6[i]);
        r2 %= scale6[i];
    }

    uint8_t data[6];
    if (ohms == 0) {
        /* 0 Ω: SHORT relay only – no decade bypass relays, CONNECT off */
        memset(data, 0x00, 6);
    } else {
        build_data(ohms, data);
    }
    apply_output(data, ohms);
    relay_set_raw(data);
    HAL_Delay(10);
    output_connected = true;
}

uint32_t relay_get_resistance(void)
{
    return current_resistance;
}
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

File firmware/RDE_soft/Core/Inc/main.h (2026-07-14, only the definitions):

#define REL_EN_Pin GPIO_PIN_4
#define REL_EN_GPIO_Port GPIOA
#define REL_SCK_Pin GPIO_PIN_5
#define REL_SCK_GPIO_Port GPIOA
#define REL_RCK_Pin GPIO_PIN_6
#define REL_RCK_GPIO_Port GPIOA
#define REL_MOSI_Pin GPIO_PIN_7
#define REL_MOSI_GPIO_Port GPIOA
#define LED_G_Pin GPIO_PIN_1
#define LED_G_GPIO_Port GPIOB
#define LED_R_Pin GPIO_PIN_2
#define LED_R_GPIO_Port GPIOB
#define W5500_INT_Pin GPIO_PIN_10
#define W5500_INT_GPIO_Port GPIOB
#define W5500_RST_Pin GPIO_PIN_11
#define W5500_RST_GPIO_Port GPIOB
#define W5500_CS_Pin GPIO_PIN_12
#define W5500_CS_GPIO_Port GPIOB
#define W5500_SCK_Pin GPIO_PIN_13
#define W5500_SCK_GPIO_Port GPIOB
#define W5500_MISO_Pin GPIO_PIN_14
#define W5500_MISO_GPIO_Port GPIOB
#define W5500_MOSI_Pin GPIO_PIN_15
#define W5500_MOSI_GPIO_Port GPIOB
#define W5500_CLK_Pin GPIO_PIN_8
#define W5500_CLK_GPIO_Port GPIOA
#define USB_DETECT_Pin GPIO_PIN_4
#define USB_DETECT_GPIO_Port GPIOB

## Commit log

2026-02-11 First sch and pcb revision, README and LICENSE update.
    [ConnDIN41612.kicad_sch, EthernetPHY.kicad_sch, Frontend.kicad_sch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]
2026-02-12 Added CSV bom
2026-02-14 Added i2c for backplane config, testpoints. File organization
    [ConnDIN41612.kicad_sch, MCU.kicad_sch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]
2026-02-18 Modified file organization, added jobsets, pcb sch cleaning
    [ConnDIN41612.kicad_sch, EthernetPHY.kicad_sch, Frontend.kicad_sch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]
2026-02-21 Little cleaning
    [ConnDIN41612.kicad_sch, RDE_board.kicad_pcb]
2026-02-21 Updated revision: v0.3
    [ConnDIN41612.kicad_sch, EthernetPHY.kicad_sch, Frontend.kicad_sch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]
2026-03-10 Edited Resistor array to be included in bom
    [EthernetPHY.kicad_sch]
2026-05-09 Firmware development. USBTMC done, ETH almost with hardware and soft modifications. By claude
    [scpi.g]
2026-05-10 Added FRAM param storage and calibration by claude
2026-05-24 Add NET:PHY:MODE SCPI, WIZnet OUI MAC, improved autocal and PDF report
    Firmware:
    - NET:PHY:MODE 0/1/2 (AUTO/10M-HD/100M-FD) configurable via SCPI, stored in FRAM
    - MAC address uses WIZnet OUI prefix (00:08:DC) instead of locally-administered
    - net_config_t: added phy_mode field, renamed mask→sn, magic updated
    - FRAM address map compacted (removed padding between cal_data and cal_config)
    - New SYSTem:FRAM:DIAG? and SYSTem:I2C:SCAN? SCPI commands for diagnostics
    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
2026-07-14 Modification based on prototype
    [ConnDIN41612.kicad_sch, EthernetPHY.kicad_sch, MCU.kicad_sch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]

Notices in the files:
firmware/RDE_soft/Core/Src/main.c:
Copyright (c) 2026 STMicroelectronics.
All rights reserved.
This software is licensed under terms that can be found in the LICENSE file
